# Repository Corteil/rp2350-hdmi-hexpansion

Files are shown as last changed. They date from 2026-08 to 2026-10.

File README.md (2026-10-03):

# Hexi-GFX — RP2350 HDMI Hexpansion for the EMF Tildagon Badge

A Tildagon hexpansion that mirrors the EMF badge's 240×240 round screen onto a
real HDMI/DVI monitor — an RP2350 drives the video over HSTX, pixel-doubled and
pillarboxed into a standard 640×480@60 signal. Every existing badge app gets
HDMI output with no code changes.

For the full design rationale, bench measurements, BOM, costing, and the
phase-by-phase delivery plan that got here, see [`HISTORY.md`](HISTORY.md).
This file covers what's true *now*.

## Status (03/10/26)

**Real mirroring and stable HSTX video work together, confirmed on real
hardware** — not just clean logs, actual moving content on a monitor. Current
firmware is `firmware/pio-testcard/`, running on an **Adafruit Metro RP2350**
dev board wired to a real badge hexpansion port, and since 03/10/26 also on
a **Raspberry Pi Pico 2 + Adafruit DVI Sock** (`-DHEXI_BOARD=pico2`, see
[its section](#alternative-bench-board-raspberry-pi-pico-2--adafruit-dvi-sock-tested)),
powered straight from the badge's 3V3. The custom hexpansion PCB's
schematic is drafted in `hardware/`; layout hasn't started (see
[Next step](#next-step)).

- Badge side: `display.attach_mirror()`, from a fork of
  [hazanjon/badge-2024-software](https://github.com/hazanjon/badge-2024-software)
  PR #454, with three real bugs found and fixed (SPI acquire-bus timeout, a
  non-idempotent display init that froze the badge's own screen, and an
  SPI-host/GPIO-pin ordering bug). Fixes were merged into hazanjon's
  `feature/hdmi-mirror` branch as
  [hazanjon/badge-2024-software#1](https://github.com/hazanjon/badge-2024-software/pull/1);
  that branch was rebuilt and flashed to the badge on 03/10/26 and the
  mirror was confirmed working with the Pico 2.
- RP2350 side: a from-scratch PIO-based SPI0 slave receiver (the hardware
  SPI0/PL022 peripheral loses byte alignment mid-burst on this chip and never
  recovers), double-buffered HSTX/DVI scanout, and a grey-to-black vignette
  fade on the pillarbox/mask area around the circular content.
- Known, understood, non-blocking: ~12% of frames (Metro) to ~18% (Pico 2,
  one sample) get abandoned when the badge starts a new frame before the
  RP2350 finishes the previous one — benign, fully instrumented, not a bug
  to fix.
- Known, benign: on the Pico 2 each port insertion resets the board twice
  about 2 s apart (likely the badge power-cycling the port); the mirror
  re-attaches by itself.

## Repo layout

| Path | What it is |
|---|---|
| `firmware/pio-testcard/` | **Current firmware.** Real HSTX/DVI video and real SPI mirror reception together — what's actually flashed to the bench Metro RP2350 today. |
| `firmware/testcard/` | Earlier milestone: full hexpansion-identity EEPROM emulation + the first end-to-end SPI link demo. Superseded by `pio-testcard` for the mirror path itself, but still the reference for EEPROM emulation. |
| `firmware/pin-probe/` | Pico 2 bench tool that counts transitions on every header GPIO (read over SWD), used with the badge's Pin Tester app to prove which Pico pin each `HS_F`..`HS_I` wire lands on. |
| `firmware/mirror_debug/` | Bench diagnostic tool used to bring up the PIO-based SPI slave receiver protocol. |
| `firmware/phase0-*/` | Individual bring-up experiments from early de-risking (HSTX/DVI basics, colour-channel fix, SPI speed sweep, EEPROM emulation, ctx rasterisation benchmark, microSD). Each has its own README. |
| `hdmi-mirror-plan.md` | Implementation notes for switching to hazanjon's real `attach_mirror()` protocol (SPI mode, byte order, per-port pin overrides). Completed; kept for reference. |
| `HISTORY.md` | The full design journal — rationale, bench measurements, BOM, costing, risk register, phase plan. Read this for *why*, not *what's true now*. |
| `hardware/` | KiCad 10 project for the hexpansion PCB (schematic v0.1 done, layout not started), `lib/jlc.*` (JLCPCB/LCSC symbols, footprints and 3D models), and `hexpansion_bom.xlsx`, the JLCPCB assembly BOM tracker. |
| `tildagon-base/` | Tildagon KiCad symbol and footprint library (hexpansion edge connector etc.), used by `hardware/`. |
| `bom.csv` | Machine-readable bill of materials, generated from the schematic (LCSC numbers, JLC Basic/Extended, prices). |

## Hardware today

Bench rig: an Adafruit Metro RP2350 (SPI0 slave on GPIO20–23, HSTX on
GPIO12–19), wired to a real hexpansion port on an EMF Tildagon badge.

**HS wiring gotcha (all ports):** hazanjon's badge-side `PORT_PINS` table
puts SCK on `HS_G` and CS on `HS_H`, the opposite of this project's original
`HS_G`=CS / `HS_H`=SCK convention. For a real mirror test, wire
`HS_F`→GPIO20, `HS_G`→GPIO22, `HS_H`→GPIO21, `HS_I`→GPIO23 at the RP2350 end.
First found on port 4, since tested on all six ports; the PCB is wired this
way. See `HISTORY.md` §4.1 for the full derivation and why the two sides
disagree.

VID/PID assigned for the eventual EEPROM-emulating hexpansion: `0x1969` /
`0x4544`.

### Alternative bench board: Adafruit Feather RP2350 + HSTX (builds, not yet tested on hardware)

Build with `-DHEXI_BOARD=feather` (see [Building and flashing](#building-and-flashing)).
The Feather is an RP2350A: the same die as the RP2354A the real hexpansion
uses (the RP2354A just adds 2 MB of flash in the package), and
its 22-pin HSTX FPC connector carries GPIO12–19 in the same lane order the
firmware already uses. So video needs no changes: plug in the same DVI
breakout and FPC cable as on the Metro.

Two things do move. GPIO21 is the Feather's onboard NeoPixel and isn't
broken out, so the Metro's GPIO20–23 SPI block can't be used. The
PIO-based receiver doesn't need hardware-SPI pins, just three consecutive
GPIOs for MOSI/CS/SCK, so it moves to D9–D11:

| Function | RP2350 GPIO | Feather pin |
|---|---|---|
| HSTX video (all 8 lines) | 12–19 | 22-pin HSTX FPC connector |
| SPI MOSI (`HS_F`) | 9 | D9 |
| SPI CS (`HS_H` on port 4) | 10 | D10 |
| SPI SCK (`HS_G` on port 4) | 11 | D11 |
| SPI MISO (`HS_I`, never driven) | 20 | MI |
| EEPROM-emulation I2C0 SDA / SCL | 4 / 5 | GPIO4 (CircuitPython `D12`/`IO4`) / D5 |
| Debug UART0 TX / RX (`_debug` build) | 0 / 1 | TX / RX |
| Status NeoPixel | 21 | onboard |
| `LS_A` → RUN | — | RST |
| GND | — | GND |

The port-4 SCK/CS crossover is already applied above. GPIO4 is labelled
from CircuitPython's pin map, so check the board silkscreen for that pad.
SWD is on the Feather's 3-pin JST-SH connector, so the Debug Probe cable
plugs straight in. UF2 flashing (hold BOOT, tap RESET) also works. Flash
is 8 MB, not 16 MB, which is plenty for this firmware. Use the RESET
button for step 3 of the reinsertion procedure below.

### Alternative bench board: Raspberry Pi Pico 2 + Adafruit DVI Sock (tested)

Build with `-DHEXI_BOARD=pico2`. **Confirmed working end to end on 03/10/26**:
stable mirror picture on the official Raspberry Pi monitor, status LED at
5 Hz while frames arrive. The Pico 2 is an RP2350A, so HSTX reaches the same
GPIO12–19 block the [Adafruit DVI Sock for Pico](https://www.adafruit.com/product/5957)
is wired to. The Sock is a passive connector plus 220 Ω series resistors, and
its product page describes it for the RP2040. It works fine with HSTX, but its
**lane order differs from the Metro/Feather wiring**, so this variant uses
`lane_to_output_bit = {0, 6, 4}` (D0 = GP12/13, D1 = GP18/19, D2 = GP16/17,
CK = GP14/15, "+" on the even GPIO).

| Function | RP2350 GPIO | Notes |
|---|---|---|
| HSTX video | 12–19 | DVI Sock, see lane order above |
| SPI MOSI (`HS_F`) | 0 | |
| SPI CS (`HS_H` on port 4) | 1 | |
| SPI SCK (`HS_G` on port 4) | 2 | port-4 SCK/CS crossover already applied |
| SPI MISO (`HS_I`, never driven) | 3 | |
| EEPROM-emulation I2C0 SDA / SCL | 4 / 5 | unchanged |
| Debug UART1 TX / RX (`_debug` build) | 8 / 9 | moved off GP0/1, which are now SPI inputs |
| Status LED (plain GPIO) | 25 | 1 Hz = running, no frames; 5 Hz = frames arriving |
| Status NeoPixel (external WS2812) | 22 | same colours as the other boards |
| `LS_A` → `RUN` | — | lets the badge reset the Pico 2; a reset switch from `RUN` to GND is also fitted |
| Badge 3V3 → VSYS (pin 39) | — | powers the board, with no USB attached |
| GND | — | shared with the badge: any GND pin on the port breakout hexpansion |

A step-by-step hardware build and flashing guide for this variant is in
[`docs/index.md`](docs/index.md), also published at
<https://corteil.github.io/rp2350-hdmi-hexpansion/>. A prebuilt UF2 is on the
[`pico2-v1` release](https://github.com/Corteil/rp2350-hdmi-hexpansion/releases/tag/pico2-v1).

Notes from bring-up:

- **Power:** it runs fine from the badge's 3V3 with no USB. Never connect USB
  and an external 3V3 into VSYS together: VBUS feeds VSYS through a diode, so
  the external source gets back-fed. Use a series Schottky if both are needed.
- **5 V on the Sock's 5 V pad** is monitor-dependent. Some monitors only show
  a signal when it is present; the official Raspberry Pi monitor and a video
  capture dongle don't need it. With no USB attached there is no VBUS, so for
  a monitor that needs it, use a boost converter: input from VSYS and GND,
  5 V output to the Sock's 5 V pad, GND common with the port breakout's GND.
- **Each port insertion resets the Pico 2 twice, about 2 s apart** (probably
  the badge power-cycling the port; not scoped). It is harmless: the mirror
  re-attaches and the picture returns by itself.
- **Wire-continuity check:** `firmware/pin-probe` plus Pin Tester's `blink`
  (via `mpremote exec`, store-installed path `/apps/Corteil_Pin_Tester`) maps
  each badge pin to a Pico GPIO. A bad `HS_F` wire here looked like CS/SCK
  arriving but a stuck-high or stuck-low data line and no `TDHD` match.

### Alternative bench board: Waveshare RP2350-PiZero (not yet tested)

The [Waveshare RP2350-PiZero](https://www.waveshare.com/wiki/RP2350-PiZero)
can stand in for the Metro, with one big caveat: its onboard mini-HDMI is
wired to **GPIO32–39**, and HSTX only reaches **GPIO12–19**, so the current
firmware can't drive the onboard connector. Instead, wire HSTX from the
40-pin header to an external DVI breakout, exactly as on the Metro.

Its chip (RP2350B), flash (W25Q128, 16 MB) and 12 MHz crystal match the
Metro, and every pin the firmware uses is on the header. The existing
`pio_testcard` build should therefore run unmodified, but that hasn't been
checked on real hardware yet.

**The header is not Raspberry-Pi numbered.** Waveshare's J5 net labels are
RP2350 GPIOs and differ from the silkscreen/BCM names (e.g. header pin 7 is
BCM4 but RP2350 **GPIO14**). Wire by *header pin number* from this table,
taken from Waveshare's schematic (`RP2350-PiZero.pdf`):

| Function | RP2350 GPIO | PiZero header pin |
|---|---|---|
| HSTX D2+ / D2− | 12 / 13 | 21 / 33 |
| HSTX CLK+ / CLK− | 14 / 15 | 7 / 29 |
| HSTX D1+ / D1− | 16 / 17 | 36 / 11 |
| HSTX D0+ / D0− | 18 / 19 | 12 / 35 |
| SPI MOSI (`HS_F`) | 20 | 38 |
| SPI CS (`HS_H` on port 4) | 21 | 40 |
| SPI SCK (`HS_G` on port 4) | 22 | 15 |
| SPI MISO (`HS_I`) | 23 | 16 |
| EEPROM-emulation I2C0 SDA / SCL | 4 / 5 | 8 / 10 |
| Debug UART0 TX / RX (`_debug` build) | 0 / 1 | 27 / 28 |
| GND | — | 6, 9, 14, 20, 25, 30, 34, 39 |
| `LS_A` → RUN | — | not on the header: solder to the RUN side of the reset button (Key2) |

HSTX lane assignment comes from `hstx_dvi_init()` in
`firmware/pio-testcard/src/main.c` (`lane_to_output_bit`), and the port-4
SCK/CS crossover above is already applied. Other differences from the Metro:

- **No addressable RGB LED.** The only LED is a red power LED. The firmware
  still drives its status-LED signal on GPIO25 (header pin 22). That's
  harmless, and you can wire a WS2812 there to get the status colours back.
- **SD card-detect isn't on a GPIO** (the slot's CD pin goes to GND), so
  GPIO22 is free for SCK.
- **Buttons:** Key1 is BOOTSEL and Key2 is reset (RUN). Use Key2 for step 3
  of the reinsertion procedure below.
- **SWD** is on the 3-pin header H1 (SWCLK / GND / SWDIO), so Debug Probe
  flashing works as documented. Holding Key1 while plugging in USB and
  copying `pio_testcard.uf2` also works.
- **Don't switch the build to the Pico SDK's `waveshare_rp2350_pizero` board
  file** without overriding its default UART. It puts UART1 on GPIO4/5,
  which collides with the EEPROM-emulation I2C in the `_debug` build. The
  Metro board file already used here puts UART0 on GPIO0/1.
- **Signal integrity:** the TMDS pairs are spread across the header, so they
  run at 252 Mbit/s over hand-run wires rather than an FPC cable. Keep each
  +/− pair short, equal-length and twisted together. Suspect the wiring
  first if the picture sparkles or drops out.

Using the onboard mini-HDMI would need one of two things. One is a PIO-based
PicoDVI scanout: 252 MHz `clk_sys`, a PIO block set to see GPIO16–47, and a
reworked framebuffer. The other is a board mod: remove the eight 200 Ω
series resistors (R1–R4, R6, R7, R10, R12) and feed GPIO12–19 into their
connector-side pads. Neither has been tried. The first diverges from the
HSTX design the hexpansion PCB will use.

## Reinsertion procedure (corrected 03/10/26, still manual)

Plugging the hexpansion into an already-running badge doesn't reliably start
mirroring on its own yet, even with the auto-attach relay packed into the
fake EEPROM (`firmware/testcard/badge_app/app.py`) and its LS_A-pulse
hardware reset (`firmware/pio-testcard/src/main.c`'s own comments have the
full root-cause trail on why a reset is needed at all). The sequence
confirmed working on the bench, in order:

1. Insert the `HDMI-HEX` hexpansion.
2. In `tildagon-hdmi-manager` (or `display_manager`), **detach** the mirror.
3. Press the physical **reset button** on the RP2350 board (SW2 on the Metro).
4. **Attach** the mirror again, from the same app.

The order matters: the reset goes between detach and attach, not after.
Auto-attach alone wasn't enough.

## Building and flashing

### RP2350 firmware (`pio-testcard`)

Needs the Raspberry Pi Pico SDK (2.x) and an `arm-none-eabi-gcc` toolchain,
with `PICO_SDK_PATH` set.

```sh
cd firmware/pio-testcard
mkdir -p build && cd build
cmake ..
cmake --build .
```

That builds for the Metro RP2350 (the default). For the Adafruit Feather
RP2350 + HSTX, configure a separate build directory from
`firmware/pio-testcard` instead:

```sh
cmake -B build-feather -DHEXI_BOARD=feather
cmake --build build-feather
```

For the Raspberry Pi Pico 2 + Adafruit DVI Sock, use `-DHEXI_BOARD=pico2`
the same way (`cmake -B build-pico2 -DHEXI_BOARD=pico2`).

Flash over SWD with a Raspberry Pi Debug Probe:

```sh
openocd -f interface/cmsis-dap.cfg -f target/rp2350.cfg -c "adapter speed 5000" \
  -c "program pio_testcard.elf verify reset exit"
```

### Badge-side driver

Depends on `display.attach_mirror()` from the fork above. Built via the
project's own Docker image (`ghcr.io/emfcamp/esp_idf:v5.5.1`):

```sh
git clone --recursive --branch pr-454-hazan-mirror https://github.com/Corteil/badge-2024-software.git
cd badge-2024-software
./scripts/firstTime.sh
docker run --rm --env "TARGET=esp32s3" -v "$(pwd)":/firmware -u "$(id -u):$(id -g)" \
  -e HOME=/tmp ghcr.io/emfcamp/esp_idf:v5.5.1
```

Flash to a real badge in bootloader mode (disconnect USB, hold **BAT + BOOP**
for ~20s, reconnect):

```sh
docker run --rm --device /dev/ttyACM0:/dev/ttyUSB0 --group-add <your dialout/plugdev GID> \
  --env "TARGET=esp32s3" -v "$(pwd)":/firmware -u "$(id -u):$(id -g)" -e HOME=/tmp \
  ghcr.io/emfcamp/esp_idf:v5.5.1 deploy
```

The badge stays in bootloader mode after flashing — disconnect/reconnect the
USB cable once more to actually boot the new image.

## Next step

Designing the actual hexpansion PCB (44 mm hexagon, EEPROM emulation, USB-C +
HDMI power isolation) — the whole plan for it, including the pin map, power
architecture, BOM, and costing this bench work was de-risking, is in
[`HISTORY.md`](HISTORY.md).

**Schematic v0.1 is done** (`hardware/rp2350-hdmi-hexpansion.kicad_sch`,
28/09/26). The PCB layout hasn't started: open the project and run
*Tools → Update PCB from Schematic*. Every part has a JLCPCB/LCSC number,
and its symbol, footprint and 3D model are in the project library
`hardware/lib/jlc.*`, pulled with
[easyeda2kicad](https://github.com/uPesy/easyeda2kicad.py). KiCad's ERC is
clean apart from one expected warning (HEXP_DET tied to GND is how the
badge detects a hexpansion), and the exported netlist was checked
pin-for-pin against the design. `bom.csv` and `hardware/hexpansion_bom.xlsx`
are generated from the schematic.

Changes from the `HISTORY.md` plan:

- **MCU is the RP2354A**, not the RP2350A: the same die and QFN-60 pinout,
  with 2 MB of flash in the package on QSPI CS0. There's no external flash
  chip (the W25Q128 is gone). 2 MB is plenty: the largest firmware build is
  about 260 KB. Build with `PICO_FLASH_SIZE_BYTES` set to 2 MB.
- **The PSRAM is footprint-only (DNP)**, for optional hand soldering. The
  part is the **APS6404L-3SQR-SN** (SOP-8, 3.3 V); the `-ZR` that the old
  BOM listed is USON-8. It stays on QSPI CS1 = GPIO0, with a 10k pull-up on
  CS that is fitted even when the PSRAM isn't, so firmware must detect it
  at boot rather than assume it.
- **Full-size HDMI Type A** socket instead of mini-HDMI. It's wider, so check
  the fit on the outer flat.
- **One Qwiic socket** instead of two, to save edge space.
- **TLV62569** 2 A buck instead of the TPS62203 (300 mA, poor stock).
- **No HDMI DDC/EDID.** The output is always 640×480@60, which every
  monitor must accept, so there's nothing to read. The PCA9306 and its six
  passives are gone. Hot-plug detect stays (GPIO2).
- **No microSD.** That frees the second side flat and GPIO5 and 8–11.
  Spare GPIOs are now **3, 4, 5, 8, 9, 10, 11**, all left no-connect.
- **Trimmed to the Raspberry Pi minimal design.** TMDS lines go straight
  from GPIO12–19 to the ESD chips and socket, with no 0R insurance resistors,
  as the bench has always run. There are 7 × 100 nF on 3.3 V (pins 44/45 and
  53/54 share, as in Raspberry Pi's reference), no BOOTSEL pull-up (QSPI_SS
  has one internally) and no RUN debounce cap. The ferrite beads are gone.
- Kept from the design guide: the 1k crystal series resistor, 33R
  VREG_AVDD filter, 27R USB series resistors and a 10k RUN pull-up (because
  of the badge reset). Also added: an HDMI +5V PTC fuse and test pads.
- Result: **80 JLC-placed parts, about $5.11 a board** at the 10-board price
  tier (25 capacitors, 32 resistors).

**Pin map changes from `HISTORY.md` §4.1.** It had no free GPIOs for three
signals, so `LS_C`/`LS_D`/`LS_E` are left unconnected and their GPIOs reused:

| GPIO | Now | Was |
|---:|---|---|
| 27 | SK6805 RGB LED data | `LS_C` (bootloader-entry idea) |
| 28 | Badge-rail sense (ADC2, 100k/100k from `3V3_BADGE`) | `LS_D` spare |
| 29 | HDMI +5V boost enable (100k pull-down) | `LS_E` spare |

On the board, `HS_G`→GPIO22 (SCK) and `HS_H`→GPIO21 (CS). That's the
crossing the badge's mirror driver needs, **tested on all six ports**.

**Firmware changes the PCB needs** (from `pio-testcard`): EEPROM emulation
moves from GPIO4/5 to **GPIO24/25**, with its internal pull-ups *off*
(they'd back-power an unpowered badge). The status NeoPixel moves to
**GPIO27**. Set the flash size to 2 MB.

**Badge reset without backfeed.** `LS_A` drives RUN through **U11, an
SN74LVC1G07 open-drain buffer powered from `3V3_BADGE`**. R4 (10k to
`3V3_BADGE`) holds `LS_A` high, so it idles at "not reset". When the badge
is off, U11 is unpowered. Its partial-power-down (I_off) spec, ≤10 µA and
typically far less, stops the RUN pull-up leaking into the badge, and the
RP2354A keeps running from USB. A plain diode can't do this: the reset
current and the leak flow the same way.

## Acknowledgements

This project depends on the work of [hazanjon](https://github.com/hazanjon).
The badge-side display mirroring that the hexpansion receives, including
`display.attach_mirror()`, the SPI frame protocol with its `TDHD` header, and
the per-port pin handling in `flow3r_bsp_display_mirror.c`, comes from
his [badge-2024-software](https://github.com/hazanjon/badge-2024-software)
work (PR #454 against `emfcamp/badge-2024-software`). His
[display_manager](https://github.com/hazanjon/display_manager) app provides
the badge-side driver definitions and attach controls used to drive it.
Without that groundwork there would be nothing for this hexpansion to mirror,
and the fixes in this repo's badge-side PR were built on top of it. Thank you.

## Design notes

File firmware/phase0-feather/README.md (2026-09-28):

# Phase 0, Part A / B3 — Adafruit Feather RP2350 (+ HSTX) bring-up

Bench firmware for the Feather in the design's [Phase 0
plan](../../HISTORY.md#phase-0--de-risk-on-the-bench-23-weekends) —
RP2350A, the chip variant the actual hexpansion design targets (see
`HISTORY.md` §4.1, "Why the RP2350A and not the B"). The PCB now uses the
RP2354A, which is the same RP2350A die with 2 MB of flash in the package,
so this bench is still representative.

Board: **Adafruit Feather RP2350 (+ HSTX)**, RP2350A, no PSRAM populated
by default (DNP footprint) unless someone's soldered an APS6404L onto it.

## What this is (and isn't)

Part A's real job — HSTX DVI mirroring (A1), pin-map validation against
the badge's hexpansion edge connector (A2), DVI output on a real monitor
(A3), current draw (A4) — needs the badge, a protoboard hexpansion, an
HSTX-to-DVI adapter, and a monitor. None of that is here yet.

**This is B3**: reusing `firmware/phase0-metro`'s PSRAM and ctx
benchmarks — both board-agnostic, no board-specific pins involved — to
get RP2350A vs. RP2350B numbers to compare against the Metro's results.
`src/ctx_bench.c`, `src/psram_dma_bench.c` and `third_party/ctx/` are
copies of the Metro's, not shared library code — see the note in
`firmware/phase0-metro/README.md` (and the design's own general
"duplication over premature abstraction" instinct) for why: this is
disposable Phase 0 bench code, not the eventual product firmware, so two
small independent copies beat coupling two separate bench projects
together.

**No SD card bench** — the Feather has no microSD slot, unlike the Metro.

**No custom board header needed** — unlike the Metro, Adafruit's Feather
RP2350 already has an official pico-sdk board header
(`adafruit_feather_rp2350.h`, RP2350A, LED GPIO7, PSRAM CS GPIO8 with
`PICO_AUTO_DETECT_PSRAM_SIZE` since Adafruit sells this board both with
and without PSRAM). `CMakeLists.txt` just sets `PICO_BOARD
adafruit_feather_rp2350`.

## PSRAM: populated or not, this runs either way

Both benchmarks already check `psram_is_available()` and skip themselves
cleanly (printing why) if PSRAM isn't detected. If you see them skip,
that itself answers "is PSRAM populated on this specific board" — no
separate check needed.

## Build

```bash
export PICO_SDK_PATH="$HOME/.pico-sdk/sdk/2.3.0"
export PICO_TOOLCHAIN_PATH="$HOME/.pico-sdk/toolchain/14_2_Rel1"
export PATH="$HOME/.pico-sdk/toolchain/14_2_Rel1/bin:$HOME/.pico-sdk/cmake/v3.31.5/bin:$HOME/.pico-sdk/ninja/v1.12.1:$HOME/.pico-sdk/picotool/2.3.0/picotool:$PATH"

cmake -G Ninja -B build .
cmake --build build
```

## Flash

Hold BOOT, tap RESET (or plug in while holding BOOT) to drop the Feather
into UF2 bootloader mode, then copy `build/bringup.uf2` onto the
`RPI-RP2` drive that appears. Or, with the board already running:

```bash
picotool load -f build/bringup.uf2
```

## Expected result

Same shape as the Metro's: USB CDC prints PSRAM detection (or a clear
"not populated" line), the self-test, the `clk_sys`/PSRAM-clock
diagnostic, the B1 ctx benchmark, then the B2 PSRAM-scanout DMA
benchmark — once. Then the LED (GPIO7) blinks at 1 Hz with a
`phase0-feather alive: tick N` heartbeat every 500 ms.

## Results (2026-08-30)

```
phase0-feather: PSRAM bring-up
PSRAM: not detected (CS GPIO 8) - expected if this board's
PSRAM footprint hasn't been populated (it ships DNP).

phase0-feather: B1 ctx rasterisation benchmark
  skipped: need >= 614400 bytes of PSRAM for a 640x480 framebuffer, have 0

phase0-feather: B2 PSRAM-backed scanout (DMA read) benchmark
  skipped: PSRAM not available
```

**This specific Feather doesn't have PSRAM populated.** Everything else
worked as designed: toolchain/board bring-up on real RP2350A silicon,
USB-CDC-wait logic, and both benchmarks skipping themselves cleanly with
a clear reason rather than hanging or crashing. No RP2350A vs. RP2350B
PSRAM/ctx comparison numbers without either populating the DNP PSRAM
footprint with an APS6404L (~$1.15, BOM line 3 — see `HISTORY.md` §8's
Phase 0 rig note) or accepting that this comparison isn't available on
this board as-is.

(An initial run of this firmware mislabelled both benchmarks'
output as "phase0-metro" — a copy-paste artifact in the duplicated
`ctx_bench.c`/`psram_dma_bench.c`, since fixed. The output above is from
the corrected build.)

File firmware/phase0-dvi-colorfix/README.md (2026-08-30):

# Phase 0, A1 — root-causing the colour channel rotation

Bench firmware for the **Metro RP2350**, not the Feather — see the main README's Phase 0
Part A ([A1](../../README.md#phase-0--de-risk-on-the-bench-23-weekends)) "Still open" note.
`firmware/phase0-dvi/` (Feather, Stage 1) found a clean 3-way colour rotation on real
hardware and worked around it with an empirically-inverted test-pattern colour table — a
test-pattern-level fix, not usable for real badge pixel data. This firmware is the actual
root-cause fix, derived from first principles and confirmed on real hardware, then backported
unchanged into `phase0-dvi/` and `phase0-dvi2/`.

## Why the Metro, not the Feather

The board available to test with at the time. Not a problem: HSTX is silicon-fixed to
GPIO12–19 regardless of RP2350A/RP2350B package (HSTX bit index `n` is always GPIO `12+n`),
and Adafruit's own Metro RP2350 pinout page confirms its dedicated 22-pin HSTX connector
breaks out exactly GPIO12–19 as D0P/D0N/D1P/D1N/D2P/D2N/CKP/CKN — the identical mapping
`phase0-dvi` already uses on the Feather. **The main README previously claimed the Metro has
"no HSTX peripheral broken out" — that was wrong**, corrected alongside this firmware. A fix
that's purely register-level TMDS math (this one) transfers between boards with zero risk;
DMA/HSTX/timing mechanics (already proven separately on the Feather in `phase0-dvi`/
`phase0-dvi2`) are untouched here.

## The root cause

Not a simple "swap two lanes" bug. Two separate mistakes compounded:

1. **Wrong lane order.** `phase0-dvi` copied Adafruit's PicoDVI driver's `expand_tmds`
   ROT/NBITS values under the assumption L0=Red, L1=Green, L2=Blue. The real DVI/HDMI TMDS
   channel convention is **L0=Blue, L1=Green, L2=Red** — not alphabetical, a well-known trap.
2. **Wrong bit-field math even for the assumed lane order.** Per pico-sdk's
   `hardware/regs/hstx_ctrl.h` (straight from the SVD): each lane's `ROT` is a **right-rotate**
   applied to the current 32-bit shifter word before that lane's encoder, and `NBITS` is the
   valid-bit count "starting from bit 7 of the rotated data" — so a channel's own MSB must
   land exactly on bit 7 after rotation. Adafruit's specific ROT values don't decode to a
   clean single-channel window under this formula against this project's own RGB565 packing
   (two pixels/word, earlier pixel in the low 16 bits, standard R\[15:11\]/G\[10:5\]/B\[4:0\]
   layout) — they must assume a different internal convention Adafruit's own driver uses
   internally, not stated anywhere obvious in their source.

**Validated the formula against a known-good reference before trusting it**: fetched
`raspberrypi/pico-examples`' own `hstx/dvi_out_hstx_encoder` RGB332 sample (L0 NBITS=1/ROT=26,
L1 NBITS=2/ROT=29, L2 NBITS=2/ROT=0) and decoded it by hand —

> `original_bit_index = (output_bit + ROT) mod 32`, window = rotated bits `[7 : 7-count+1]`

— which resolves EXACTLY to L0=Blue, L1=Green, L2=Red, matching RGB332's known bit layout
bit-for-bit. That confirmed both the rotate-direction/window formula and the true lane order,
independent of anything Adafruit-specific.

**Recomputed from scratch for this project's own RGB565 layout** using
`ROT = (channel_MSB_bit_index - 7) mod 32`:

| Channel | Lane | MSB bit | ROT | NBITS field | Bits |
|---|---|---:|---:|---:|---:|
| Red | L2 | 15 | 8 | 4 | 5 |
| Green | L1 | 10 | 3 | 5 | 6 |
| Blue | L0 | 4 | 29 | 4 | 5 |

`expand_shift`'s `ENC_SHIFT=16` right-rotates the whole 32-bit word by 16 between the two
packed pixels, bringing the second pixel down into the same low-16-bit position the first
started in — so these same fixed ROT values correctly decode both pixels per word, the same
way pico-examples' single fixed set works across all 4 sub-pixels of its RGB332 case.

## Test pattern

Same 8-bar pattern as `phase0-dvi` Stage 1 (white/yellow/cyan/green/magenta/red/blue/black,
80px each), but using the **true, uncompensated** RGB565 values directly — no software
inversion table. If the fix is right, colours come out correctly ordered with no further
massaging.

## Build

```bash
export PICO_SDK_PATH="$HOME/.pico-sdk/sdk/2.3.0"
export PICO_TOOLCHAIN_PATH="$HOME/.pico-sdk/toolchain/14_2_Rel1"
export PATH="$HOME/.pico-sdk/toolchain/14_2_Rel1/bin:$HOME/.pico-sdk/cmake/v3.31.5/bin:$HOME/.pico-sdk/ninja/v1.12.1:$HOME/.pico-sdk/picotool/2.3.0/picotool:$PATH"

cmake -G Ninja -B build .
cmake --build build
```

## Flash

`picotool load -f build/bringup.uf2` (forces a reboot over USB, no BOOTSEL button needed if
the board is already running any pico-sdk firmware with a live USB connection), or hold BOOT
+ tap RESET and copy `build/bringup.uf2` onto the `RPI-RP2` drive. No USB CDC console output
(pure video, same as `phase0-dvi` Stage 1) — check the monitor, connected via the Metro's
22-pin HSTX port and the Adafruit HSTX-to-DVI adapter.

## Results (2026-08-30, Metro RP2350, real monitor)

**Confirmed correct on the first attempt.** 8 sharp, evenly-spaced, **correctly-coloured**
vertical bars — white/yellow/cyan/green/magenta/red/blue/black, left to right, stable, no
compensation table involved. The derivation above is the real fix, not a guess that happened
to work.

**Backported unchanged into `firmware/phase0-dvi/` and `firmware/phase0-dvi2/`** (both
rebuild cleanly) — the register math is board-independent, so the same fix applies there
without re-deriving anything. Not re-flashed on the physical Feather in this session (only
the Metro was connected), but there is no board-specific mechanism left in this fix to
re-verify: same silicon, same GPIO/lane mapping, same RGB565 packing convention, same
`expand_shift` config, all already true on both boards. Re-flashing the Feather to visually
re-confirm is cheap whenever it's next connected, but not expected to reveal anything new.

Settles the main README's A1 "still open" item: the colour channel rotation is now fixed at
the source, not compensated in the test pattern.

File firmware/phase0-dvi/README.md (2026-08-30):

# Phase 0, Part A — HSTX DVI bring-up (Stage 1)

Bench firmware for the Feather in the design's [Phase 0
plan](../../README.md#phase-0--de-risk-on-the-bench-23-weekends), Part A —
specifically **A1** (scale-during-scanout) and **A3** (640×480@60 DVI
output on a real monitor).

Board: **Adafruit Feather RP2350 with HSTX**, plus the Adafruit RP2350
22-pin FPC HSTX-to-DVI adapter and a monitor.

## What this is (Stage 1, not the full A1 yet)

The real A1 target is a 240×240 source, pillarboxed and circular-masked,
scaled 2× into 640×480 — see main README §3.1/§3.4. That's a substantial
per-scanline command table (the mask boundary varies every line). Rather
than write and test all of that blind, this stage proves the more basic
plumbing first:

- **320×240 source doubled to fill 640×480 exactly** — no pillarbox, no
  circular mask needed, since 320×2=640 and 240×2=480 land exactly on the
  output size. Once this works, the harder pillarboxed/masked 240×240
  case is an extension, not a from-scratch rewrite.
- **Horizontal 2× done by pre-expanding into 640-wide rows in SRAM at
  init**, not via HSTX/DMA's pixel-duplication register trick. Sidesteps
  a fiddly bit-packing detail for this first attempt; vertical 2× is done
  the simple way regardless (re-reading each source row twice).
- **Two-DMA-channel ping-pong + one IRQ per scanline** (from the official
  [`raspberrypi/pico-examples`](https://github.com/raspberrypi/pico-examples)
  `hstx/dvi_out_hstx_encoder` example), not the more CPU-efficient
  one-IRQ-per-*frame* ring-buffer mechanism. The ring-buffer approach
  (used by Adafruit's own PicoDVI driver — see below) is real and worth
  adopting once this simpler, fully-traced version is confirmed correct on
  hardware — CPU load is what A1 actually needs to measure, just not
  from this stage.

Two references, both credited in `src/main.c`'s file header:
- **[`raspberrypi/pico-examples`](https://github.com/raspberrypi/pico-examples)**
  `hstx/dvi_out_hstx_encoder` (BSD-3) — the DMA ping-pong mechanism, the
  standard 640×480@60 timing constants (`V_BACK_PORCH=33`, CEA-861 VIC 1),
  and the overall command-list structure this firmware is built from.
- **[`adafruit/circuitpython`](https://github.com/adafruit/circuitpython)**
  `ports/raspberrypi/common-hal/picodvi/Framebuffer_RP2350.c` (MIT) — the
  RGB565 `expand_tmds`/`expand_shift` register values (proven on real
  HSTX+DVI hardware), and confirmation of the BSWAP-during-DMA idea for
  RGB565. **Not used for timing** — that file's own `MODE_640_V_BACK_PORCH`
  is 133, not the standard 33, for reasons unclear; the spec-correct
  pico-examples numbers are used instead, matching main README §3.3.

## Feather-specific pin mapping

Confirmed from [Adafruit's Feather RP2350 pinout
page](https://learn.adafruit.com/adafruit-feather-rp2350/pinouts), **not**
assumed from the Pico DVI Sock pinout pico-examples' own comment
describes (different board, different mapping):

| GPIO | Signal |
|---|---|
| 12/13 | TMDS lane 2 |
| 14/15 | Clock |
| 16/17 | TMDS lane 1 |
| 18/19 | TMDS lane 0 |

Color-channel-to-lane assignment (which of R/G/B is "lane 0" and so on)
is inferred from Adafruit's driver's own internal naming (`red` feeds
`expand_tmds`'s L0 field in their code) matched against their pinout
page's own "Lane0/1/2" terminology — consistent, but not seen stated
explicitly as "GPIO18/19 carries red" in so many words. If the test
pattern's colours come out channel-swapped, that's a one-line fix
(swap two entries in `lane_to_output_bit[]` in `src/main.c`) — a cheap,
easily visually diagnosed thing to get wrong, not a hardware risk.

## Test pattern

8 vertical colour bars, 80px each: white / yellow / cyan / green /
magenta / red / blue / black — the classic order. Lets one glance confirm
both geometry (bars should be sharp, evenly spaced, no skew) and colour
wiring (each bar is a known, named colour) at once.

## Build

```bash
export PICO_SDK_PATH="$HOME/.pico-sdk/sdk/2.3.0"
export PICO_TOOLCHAIN_PATH="$HOME/.pico-sdk/toolchain/14_2_Rel1"
export PATH="$HOME/.pico-sdk/toolchain/14_2_Rel1/bin:$HOME/.pico-sdk/cmake/v3.31.5/bin:$HOME/.pico-sdk/ninja/v1.12.1:$HOME/.pico-sdk/picotool/2.3.0/picotool:$PATH"

cmake -G Ninja -B build .
cmake --build build
```

## Flash

Hold BOOT, tap RESET (or plug in while holding BOOT), copy
`build/bringup.uf2` onto the `RPI-RP2` drive. No USB CDC console output
from this firmware (it's pure video output, no `stdio` use in the render
path) — the only thing to check is the monitor.

## What to check

1. **Does a picture appear at all** — the fundamental TMDS/HSTX/DMA/timing
   chain working, independent of anything else.
2. **Is it stable** — no flickering, rolling, or loss of sync.
3. **Are there exactly 8 sharp, evenly-spaced vertical bars filling the
   whole 640×480 area**, in the order listed above — confirms the
   doubling math and DMA read addressing are right.
4. **Are the colours right** (white/yellow/cyan/green/magenta/red/blue/
   black, in that order) — confirms the RGB565 TMDS config and the
   lane/pin mapping. If channel-swapped (e.g. red and blue traded), see
   the note above — cheap, expected-possible, easy fix.

## Results (2026-08-30, Adafruit Feather RP2350 with HSTX)

**Working, after three real bugs found and fixed on hardware:**

1. **Ribbon cable inserted backwards** — showed as "no signal" on the
   monitor. Diagnosed by flashing CircuitPython and running Adafruit's own
   `picodvi` example (same resolution, same adapter) — it also showed
   nothing until the cable was reseated correctly, which isolated the
   problem to the physical connection rather than any code, ours or
   Adafruit's.
2. **Wrong pixel clock** — `clk_hstx` follows `clk_sys` undivided by
   default (confirmed via [RP2350 datasheet](https://pip.raspberrypi.com/documents/RP-008373-DS-rp2350-datasheet.pdf)
   §12.11.4), and the real pixel clock is `clk_hstx`/5 (fixed by the
   `N_SHIFTS=5` DDR scheme) — not adjustable via `CSR.CLKDIV`, which is
   only the *clock generator* output's own period and must equal
   `N_SHIFTS` to keep clock and data aligned. An initial attempt to "fix"
   the pixel clock by changing `CLKDIV` (5→6) was wrong and made things
   worse (regressed from "out of range" to "no signal" — see git history).
   The actual fix: `set_sys_clock_khz(126000, true)` at the top of
   `main()`, confirmed against
   [`Panda381/DispHSTX`](https://github.com/Panda381/DispHSTX)'s own
   tested video mode table, which explicitly uses "system clock 126 MHz"
   for 640×480@60.
3. **Colour channels rotated** — white and black round-tripped correctly
   (colour-order invariant), every other colour came out as a fixed,
   consistent substitute — a clean 3-way rotation, not a scramble.
   **Root-caused and fixed at the source (2026-08-30)** — see the
   `expand_tmds` comment in `src/main.c` and
   [`../phase0-dvi-colorfix/README.md`](../phase0-dvi-colorfix/README.md)
   for the full derivation and hardware confirmation (on a Metro RP2350 —
   the fix is pure register-level TMDS math, board-independent, and was
   backported here unchanged). Not a lane swap: Adafruit's PicoDVI driver
   values this project originally copied assumed the wrong lane order
   (L0=Red instead of the real DVI/HDMI convention L0=Blue) *and* didn't
   decode to a clean bit-field under RP2350's own documented `ROT`/`NBITS`
   semantics for this project's RGB565 packing — recomputed from scratch
   instead, and validated against `pico-examples`' own RGB332 sample
   before trusting the result.

**Fully confirmed on hardware, including the colour fix**: 8 sharp,
evenly-spaced, correctly-coloured vertical bars (white/yellow/cyan/green/
magenta/red/blue/black, left to right), stable (no flicker/rolling/sync
loss). Black bars either side on a widescreen monitor are expected —
640×480 is a 4:3 signal, shown at native size on a 16:9 panel rather than
stretched. **Stage 1 is done.**

## Next: the real A1

Once this is confirmed, extend to the actual A1 target: 240×240 source,
2× scaled, pillarboxed (80px black bars each side, since 640−480=160),
circular-masked (matching what the badge's own round display would show).
That needs a per-scanline command table where the "real pixel data" width
varies with a circle equation, computed once at mode-set — see main
README §3.4. Also worth then measuring actual CPU load against §3.4's
2–5% estimate, and (per B3/A2) comparing the ring-buffer one-IRQ-per-frame
mechanism against this stage's simpler one-IRQ-per-scanline approach.

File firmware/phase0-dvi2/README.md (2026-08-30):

# Phase 0, Part A — HSTX DVI bring-up (Stage 2: the real A1 target)

Builds on [`../phase0-dvi/`](../phase0-dvi/) (Stage 1, confirmed working
on real hardware — three bugs found and fixed there: flipped ribbon
cable, wrong pixel clock, rotated colour channels; see its README). This
is the actual **A1** target from the design's [Phase 0
plan](../../README.md#phase-0--de-risk-on-the-bench-23-weekends): a
240×240 source, scaled 2×, pillarboxed and circular-masked into 640×480 —
main README §3.1/§3.4.

Board: **Adafruit Feather RP2350 with HSTX**, plus the HSTX-to-DVI
adapter and a monitor.

## What's new vs. Stage 1

- **240×240 source** (not 320×240), pre-doubled horizontally in software
  into 480-wide rows in SRAM — same technique as Stage 1.
- **Pillarbox**: 80px of black on each side of the 480-wide doubled
  content (640−480=160, ÷2=80) — always present.
- **Circular mask**: `row_half_width[]`, one value per output row
  (0–479), computed once at init from the circle equation (diameter
  480, centred on the 480×480 square) — "the per-line descriptor table
  for the circular mask" main README §3.4 describes. Rows near the
  vertical centre show close to the full width; rows near the top/bottom
  show progressively less, down to nothing outside the circle's radius.
- **CPU load measurement**: a busy-loop counter, timed for a fixed window
  before HSTX/DMA starts and again after — printed over USB CDC. The
  design's own estimate (main README §3.4) is 2–5% of one core.

## Known limitations of this measurement (read before trusting the number)

- **Per-row IRQ overhead is higher here than the design's target
  mechanism.** Each active row now takes 4 DMA-completion IRQs (command
  list / left black fill / pixel data / right black fill) instead of
  Stage 1's 2, on top of Stage 1's own already-simpler-than-the-real-design
  starting point (two-channel per-scanline IRQ, not the CPU-efficient
  one-IRQ-per-*frame* ring-buffer mechanism the actual product firmware
  should use — see Stage 1's README). **Treat the measured CPU load as an
  upper bound**, not the number the real design will achieve.
- **USB CDC adds its own interrupt overhead**, present in this build's
  "loaded" measurement but absent from a hypothetical console-free build.
  Stage 1 had no USB CDC at all (pure video, no diagnostics beyond the
  LED) for exactly this reason; Stage 2 trades a small amount of measurement
  purity for actually being able to read the CPU-load number out.
- The busy-loop technique itself is coarse (counts loop iterations in a
  fixed wall-clock window, compares to a no-DVI baseline) — good enough
  to sanity-check "is this in the same ballpark as 2-5%, or way off,"
  not a precise profiler.

## Command-list structure — one HSTX command per row, not three

**First hardware attempt at this stage used three separate
`HSTX_CMD_TMDS`/`TMDS_REPEAT` *commands* per active row (left fill,
pixel-data-priming, right fill) and got "no signal" on the monitor** —
the board stayed alive (LED heartbeat, CPU-load measurement both
completed fine), but no valid picture, worse than Stage 1's "out of
range." Root cause: RP2350 datasheet §12.11.5 — "the command expander
cannot output data on the cycle where it pops a command from the FIFO,
so the expansion shift register is empty for at least one cycle."
Stage 1's proven active line has exactly **one** command word
(`HSTX_CMD_TMDS|640`); the three-command version added two extra
command-boundary stalls per active row that blanking lines don't have,
almost certainly breaking the constant per-line duration a monitor needs
to lock horizontal sync to.

**Fixed by restructuring to match Stage 1's command shape exactly**: one
`HSTX_CMD_TMDS|640` command per active row (`vactive_line`, byte-for-byte
Stage 1's version), consuming its declared 320-word budget across up to
three separate DMA *data* transfers with no command words in between:

1. **Command phase** — `vactive_line`'s single `TMDS|640` command
   (unchanged from Stage 1).
2. **Left fill** — `left_black/2` words of pure black, read from
   `zero_buf` (a static all-zero SRAM buffer, sized for the worst case —
   see its comment for why it's deliberately *not* `const`/flash-resident).
3. **Pixel data** — `half_width` words read directly from `framebuf`, at
   a per-row column offset so the visible span is horizontally centred.
4. **Right fill** — `right_black/2` words, also from `zero_buf`.

`left_black` and `right_black` are always equal by construction (the mask
is centred), and — since `PILLARBOX` alone is 80px — always nonzero, so
phases 2 and 4 always run for every active row; only phase 3 (real pixel
data) can be zero-length, on fully-masked rows near the very top/bottom
of the circle (a zero-length DMA transfer completes immediately and is
harmless, no special-casing needed). The word budget always sums to
exactly 320 (`left_black/2 + half_width + right_black/2` — the pixel-level
identity `left_black + 2·half_width + right_black = 640` divided by 2),
matching `vactive_line`'s declared consumption precisely.

## Test pattern

Same 8-bar pattern and colour table as Stage 1 (see its README for how
those colour values were empirically derived), scaled to the new content
width: 60px/bar (480/8) instead of 80px/bar (640/8).

## Build

```bash
export PICO_SDK_PATH="$HOME/.pico-sdk/sdk/2.3.0"
export PICO_TOOLCHAIN_PATH="$HOME/.pico-sdk/toolchain/14_2_Rel1"
export PATH="$HOME/.pico-sdk/toolchain/14_2_Rel1/bin:$HOME/.pico-sdk/cmake/v3.31.5/bin:$HOME/.pico-sdk/ninja/v1.12.1:$HOME/.pico-sdk/picotool/2.3.0/picotool:$PATH"

cmake -G Ninja -B build .
cmake --build build
```

## Flash

Hold BOOT, tap RESET, copy `build/bringup.uf2` onto `RPI-RP2`. Unlike
Stage 1, this build **does** have USB CDC — open a serial terminal on its
port to see the CPU-load measurement print once at boot.

## What to check

1. **On the monitor**: a circle (not a square) of 8 coloured bars,
   pillarboxed and letterboxed by black, roughly filling the 480×480
   region centred in the 640×480 frame. Top and bottom of the circle
   should curve smoothly, not step raggedly (the mask is computed
   per-pixel-row, so it should look genuinely round, not blocky) —
   though at 480px diameter some visible stepping at extreme angles is
   normal for a pixel-quantised circle, not a bug.
2. **Stability** — no flicker, rolling, or sync loss (same as Stage 1).
3. **On the USB serial console**: the CPU load percentage. Sanity-check
   against the caveats above rather than the raw design target.

## Results (2026-08-30, Adafruit Feather RP2350 with HSTX)

**Working, after one real bug found and fixed on hardware** (see the
"Command-list structure" section above for the full story — first
attempt used three separate HSTX commands per active row and got "no
signal"; fixed by restructuring to Stage 1's proven single-command shape).

**Confirmed on the monitor**: a circle of 8 coloured bars, correctly
pillarboxed and circular-masked, centred in the 640×480 frame. The
circle's outline shows some pixel-level stepping — expected, from the 2px
horizontal quantisation needed for word-aligned DMA reads (documented
above, not a bug) — geometry and colours otherwise correct, stable (no
flicker/rolling/sync loss).

**Colour path since changed (2026-08-30):** the above run used Stage 1's
empirically-compensated `bar_colours[]`/`expand_tmds` (correct-looking
output, root cause not yet found). Both are now replaced with the actual
root-cause fix — see `expand_tmds`'s comment in `src/main.c` and
[`../phase0-dvi-colorfix/README.md`](../phase0-dvi-colorfix/README.md).
Builds cleanly with the new values; not yet re-flashed on the physical
Feather to re-confirm visually (the fix is board-independent register
math, already hardware-confirmed on a Metro RP2350, so this is a
formality rather than an open question — but genuinely not yet done).

**CPU load measurement**:

```
CPU load baseline (DVI not yet running): 1399971 busy-loop iterations / 200ms
CPU load with DVI running: 1304061 busy-loop iterations / 200ms
-> approx 6.9% of one core spent servicing the DVI scanout IRQ
```

**6.9% is close to the design's own 2–5% estimate** (main README §3.4),
despite this stage deliberately using a less efficient mechanism than the
real design calls for (4 DMA-completion IRQs per active row instead of
the target one-IRQ-per-*frame* ring-buffer approach, plus USB CDC's own
interrupt overhead present in this measurement but not in a console-free
build). A more optimised implementation should land inside the original
estimate. **This is a strong validation of the whole mirroring
architecture's core CPU-budget assumption** — the thing A1 exists to
check.

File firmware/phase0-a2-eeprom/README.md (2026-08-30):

# Phase 0, A2 / C4 — emulated hexpansion EEPROM over I2C0 target

Bench firmware for the Metro RP2350, testing two things at once:

- **A2** ([Phase 0 plan](../../README.md#phase-0--de-risk-on-the-bench-23-weekends)) —
  does RP2350's I2C0 target/slave mode actually work, wired the way §4.1 (as adapted for
  this specific bench board — see the main README's A2 section) says it should?
- **C4** — does the badge actually discover and enumerate this emulated EEPROM reliably?
  (§5's "one genuine risk": the badge scans shortly after power-on; if the RP2350 hasn't
  brought its I2C target up yet, the port enumerates as "no EEPROM" and nothing runs.)

Board: **Adafruit Metro RP2350** — see the main README's A2 section for why this replaced
the Feather (GPIO21/CS wasn't accessible there for the SPI0 test; unrelated to this I2C0
test, but same board now used for both).

## Wiring

I2C0 target uses **GPIO4 (SDA) / GPIO5 (SCL)** — a bench-test-only substitution for the
real design's GPIO24/25 (see the main README's A2 section for why: Metro's own GPIO24
isn't broken out, GPIO25 is its onboard NeoPixel). `HEXP_DET` tied to GND, badge `SDA`/`SCL`
to GPIO4/5, `GND` shared, **badge `+3V3` NOT connected** (Metro is USB-powered; no
isolation circuit exists in this bench setup to safely tie two live 3.3V rails together —
see the main README §4.5 for the real design's protection, not present here).

## What this does

- `eeprom_i2c_start()` runs as the **literal first line of `main()`**, before
  `stdio_init_all()` or anything else — §5's mitigation #1 ("bring the I2C target up in
  the first few hundred microseconds ... target < 20 ms from power-good").
- Emulates a 64 KiB I2C EEPROM at address `0x50`, 16-bit addressing, RAM-only (no flash
  persistence — proving reliable *enumeration* is this test's goal, not the product's
  eventual field-update-via-EEPROM-write feature).
- Header at offset 0 matches §1.4's `<4s4sHHIHHH9s` + checksum layout exactly: magic
  `THEX`, manifest `2026`, `fs_offset`=64, `page_size`=64, `total_size`=65536, placeholder
  `vid`/`pid` (0x0000 — **not yet requested from the badge team ("UHB-IF"), §1.4 flags this
  as a "do this early" item, still outstanding**), `unique_id` from the RP2350's own
  factory-programmed chip ID (low 16 bits, via `pico_get_unique_board_id()`), friendly name
  `Hexi-GFX`.
- I2C slave ISR technique (raw register access, ISR in RAM, 2-byte address state machine)
  adapted from
  [`sammachin/rp2040-hexpansion`](https://github.com/sammachin/rp2040-hexpansion) (MIT) —
  a real working THEX-header EEPROM emulator whose header layout independently
  cross-validates this design's own §1.4. Ported from Arduino/RP2040 to bare pico-sdk C
  targeting RP2350's I2C0; pico-sdk's own `gpio_set_function()`/`i2c_init()` are used for
  setup, only the slave-mode register overrides and the ISR itself need raw access (pico-sdk
  has no built-in slave/target API).
- Prints I2C read/write byte counts and a "header has been read" announcement over USB CDC
  whenever they change, so you can watch the badge's scan happen live.

## Build

```bash
export PICO_SDK_PATH="$HOME/.pico-sdk/sdk/2.3.0"
export PICO_TOOLCHAIN_PATH="$HOME/.pico-sdk/toolchain/14_2_Rel1"
export PATH="$HOME/.pico-sdk/toolchain/14_2_Rel1/bin:$HOME/.pico-sdk/cmake/v3.31.5/bin:$HOME/.pico-sdk/ninja/v1.12.1:$HOME/.pico-sdk/picotool/2.3.0/picotool:$PATH"

cmake -G Ninja -B build .
cmake --build build
```

## Flash

Hold BOOT, tap RESET, copy `build/bringup.uf2` onto `RPI-RP2`.

## What to check

1. **USB serial console**: should print the startup banner, then activity lines as I2C
   traffic happens.
2. **Plug the hexpansion into the badge** (or use the badge's Hexpansions app to trigger a
   scan on the port it's in). Watch for the "*** Header (byte 0) has been read ***" line —
   that's the badge's own enumeration scan finding this EEPROM.
3. **Does the badge itself recognise the port as occupied** — check the badge's own UI/menu
   for the hexpansion slot in question. It likely won't run an *app* yet (no LittleFS
   filesystem is present past the header, and `vid`/`pid` are placeholders), but it should
   at minimum detect *something* answering at `0x50`.

## Results (2026-08-30, Metro RP2350, real badge)

**Worked on the first attempt — no bugs found.**

```
phase0-a2-eeprom: I2C0 target 0x50 running (started before stdio/USB init)
  Plug the hexpansion into the badge now, or run the badge's Hexpansions app
  to trigger a scan. Watching for reads/writes below.

  I2C activity: 632 bytes read, 0 bytes written (total)
  *** Header (byte 0) has been read -- badge has scanned this EEPROM ***
  I2C activity: 664 bytes read, 0 bytes written (total)
```

The badge found the EEPROM and read well past the 32-byte header (632, then 664 bytes) —
strong evidence the header **validated correctly** (magic `THEX`, manifest `2026`, checksum
all passed), since a failed check would have made the badge stop at byte 32. The extra reads
are almost certainly the badge attempting to mount a LittleFS filesystem at `fs_offset=64`
(§1.4, 512-byte blocks) and finding nothing there — expected, since no real filesystem image
was provided; that wasn't this test's goal.

**No enumeration race observed** — confirms §5's mitigation #1 (I2C target started as the
literal first line of `main()`) is sufficient in practice, at least for this single test.
Settles main README risk 1 (§9) in principle; the formal 50×-cold-plug reliability/timing
measurement C4 calls for is still outstanding.

**C4's 50×-cold-plug run cannot happen on this bench rig at all, not just "not yet done"
(2026-08-30).** C4 needs to measure worst-case time from **port power-on** to the badge's
first I2C read, against the RP2350's time-to-I2C-ready — but this rig's Metro is
USB-powered, with badge `+3V3` deliberately left unconnected (see Wiring above: "no
isolation circuit exists in this bench setup to safely tie two live 3.3V rails together").
So unplugging/replugging the hexpansion into the badge port never power-cycles the RP2350 at
all — it stays continuously powered and running throughout every "cold" plug, which is
exactly the condition C4 needs to NOT be true to measure anything. Cold-plug timing needs
either the real product (RP2350 powered from the hexpansion's own +3V3, badge-supplied,
Phase 2) or a bench modification that actually power-cycles the RP2350 from the badge rail
with isolation from USB during the test — out of scope for a quick Phase 0 bench check. C4
moves to Phase 2 rather than staying an open Phase 0 item.

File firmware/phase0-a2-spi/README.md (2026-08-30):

# Phase 0, A2 — SPI0-slave half

Bench firmware for the Metro RP2350, testing whether RP2350's SPI0 in slave mode actually
works as wired for the badge link — see the main README's A2 section for the bench board
choice/wiring, and section 4.1's "resolved" note on how the `HS_F/G/H/I` SPI role mapping
was chosen (this project's own free choice, matched by the badge-side script here).

Companion to [`../phase0-a2-eeprom/`](../phase0-a2-eeprom/) (the I2C0-target half, already
confirmed working on real hardware). **Unlike I2C0, nothing happens here until something on
the badge actively drives SPI0 as master** — the badge doesn't touch these pins on its own,
so this test needs both the RP2350 firmware below *and* [`badge_test.py`](badge_test.py)
run against the badge.

## Wiring

Same as `phase0-a2-eeprom` for GND/HEXP_DET, plus the four SPI0 pins:

| Badge signal | RP2350 GPIO | Role |
|---|---:|---|
| `HS_F` | 20 | MOSI (badge → RP2350) |
| `HS_G` | 21 | CS |
| `HS_H` | 22 | SCK |
| `HS_I` | 23 | MISO (RP2350 → badge) |

## What this does

- RP2350 side (`src/main.c`): brings up SPI0 as slave on the four pins above (register-level
  technique — `spi_init` + `spi_set_slave` + `gpio_set_function` on all 4 pins, CS included
  — same pattern as the official
  [`raspberrypi/pico-examples`](https://github.com/raspberrypi/pico-examples)
  `spi/spi_master_slave/spi_slave` example, BSD-3, not copied verbatim). Blocks on
  `spi_write_read_blocking()` waiting for a 16-byte transfer from the badge; transmits a
  fixed known pattern (`0xA0..0xAF`) back on every round, and prints whatever it received
  over USB CDC.
- Badge side (`badge_test.py`): a MicroPython script using `machine.SPI` as master on the
  ESP32-S3's matching `hs_x` pins for **badge port 3 (C)** specifically (`MOSI=GPIO34,
  CS=GPIO33, SCK=GPIO47, MISO=GPIO48` — see the script's own header comment for the port
  table if the hexpansion is in a different port). Sends an ascending byte pattern
  (`0x00..0x0F`), 3 rounds, 500 ms apart, printing what came back.

## Build (RP2350 side)

```bash
export PICO_SDK_PATH="$HOME/.pico-sdk/sdk/2.3.0"
export PICO_TOOLCHAIN_PATH="$HOME/.pico-sdk/toolchain/14_2_Rel1"
export PATH="$HOME/.pico-sdk/toolchain/14_2_Rel1/bin:$HOME/.pico-sdk/cmake/v3.31.5/bin:$HOME/.pico-sdk/ninja/v1.12.1:$HOME/.pico-sdk/picotool/2.3.0/picotool:$PATH"

cmake -G Ninja -B build .
cmake --build build
```

## Running the test

1. Flash `build/bringup.uf2` onto the Metro (hold BOOT, tap RESET, copy the file).
2. Open a serial terminal on the Metro's USB CDC port. It'll print the pin config and then
   block, waiting — nothing else happens until step 3.
3. Run `badge_test.py` against the badge:
   ```bash
   mpremote connect COMx exec "$(cat badge_test.py)"
   ```
   **This interrupts whatever's running on the badge's screen** (any `mpremote` command
   does — see the project's own mpremote-gotcha notes) — expected here, this is a
   deliberate test run, not passively watching an app. The badge will need resetting
   afterward to get back to normal use.
4. Watch both consoles: the badge's should show 3 rounds of "sent ... received ...", and the
   Metro's should show matching "round N: transferred 16 bytes. Received from badge (MOSI):
   00 01 02 ... 0f" lines.

## What success/failure looks like

- **Working**: Metro's console shows the badge's ascending `00..0f` pattern; badge's console
  shows the Metro's fixed `a0..af` pattern. Both sides received exactly what the other sent.
- **No signal at all** (Metro never unblocks): SPI0 isn't seeing clock activity — check the
  SCK wiring (`HS_H`↔GPIO22) first, then CS (without CS asserted low, the PL022 slave
  peripheral won't sample MOSI/SCK at all — confirmed from the RP2350 datasheet's SPI
  chapter, this isn't optional).
- **Metro unblocks but data is garbled**: check SPI mode (`polarity`/`phase`) match between
  both scripts (both use mode 0 here — CPOL=0, CPHA=0), and bit order (both default to
  MSB-first).

## Results (2026-08-30, Metro RP2350, real badge)

**First attempt: RP2350 never unblocked.** Badge's `badge_test.py` completed all 3 rounds
without error, but received all zeros back (not the expected `a0..af`) — and the Metro's
console never printed past the startup/waiting banner, meaning `spi_write_read_blocking()`
never saw a complete 16-byte transfer. Since MicroPython's master-mode SPI has no handshake
with the slave, the badge finishing cleanly does **not** prove the RP2350 received anything —
a mode/bit-order mismatch would still let bytes clock in (just garbled), so a full stall
points at CS or SCK not reaching the RP2350 at all (see the datasheet-sourced note above).

Also found in passing (not yet confirmed as the cause, but a real conflict): this board's
`PICO_DEFAULT_LED_PIN` is GPIO23 — the same pin `PIN_MISO` uses. `gpio_set_function()` on
GPIO23 overrides the LED's SIO function to SPI TX, so this is survivable for the SPI signal
itself (the LED is just a few-mA load), but it's a real, board-specific pin conflict worth
fixing before this becomes anything beyond a bench test.

Built `src/gpio_probe.c` (second target, `build/gpio_probe.uf2`) to isolate wiring from SPI
peripheral config: watches MOSI/CS/SCK/MISO as plain SIO inputs with edge-count IRQs, no SPI
peripheral involved at all. First run (against the then-current mode-0, per-byte-CS-toggle
script) showed clean CS/SCK/MOSI activity matching the badge's transfer — wiring judged good
at that point.

**Second attempt (v3: mode 3, CS held low for the whole burst) — also failed, differently.**
Badge received all `0xff` this time (not all-zero like v1), and the Metro's console again
never printed anything — `spi_write_read_blocking()` still never unblocked. Root-caused with
three more probes, all flashed and run against real hardware in this session (via
`picotool load -f` / `picotool reboot -f` — no BOOTSEL button needed, the running app's own
USB connection is enough for picotool to force a reboot):

1. **`src/spi_loopback_test.c`** (`spi_lbm.uf2`) — SPI0 master mode with the PL022's internal
   loopback bit (LBM) set, entirely bypassing external pins. **Result: MATCH** — sent
   `10..1f`, received `10..1f` back, 154 µs. **The SPI0 peripheral itself is functional.**
2. **`src/spi_status_probe.c`** (`spi_status_probe.uf2`) — polls `SSPSR` directly instead of
   calling `spi_write_read_blocking()`, so it can show partial/failed activity that the
   blocking call would hide. FUNCSEL readback confirmed all 4 pins correctly muxed to SPI
   (`MOSI=1 CS=1 SCK=1 MISO=1`, matching `GPIO_FUNC_SPI`); `cr0`/`cr1` confirmed slave mode 3
   as configured (`SSE=1 MS=1 DSS=7 SPO=1 SPH=1`). **Result: `SR` never changed at all**
   across a full 3-round badge transfer — `BSY` and `RNE` stayed 0 throughout. Not corrupted
   data, not partial reception — the peripheral never reacted to the transfer at all.
3. **`src/gpio_probe.c`, re-run against the current v3 script** (the first gpio_probe result
   above predates the mode-3/CS-continuous change, so it needed re-confirming). **This is the
   finding that explains everything above it:**

   ```
   MOSI=0(edges=120)  CS=1(edges=0)  SCK=1(edges=768)  MISO=1(edges=63)
   ```

   Over 3 rounds × 16 bytes: **SCK shows exactly 768 edges** (16 bytes × 8 bits × 2 edges ×
   3 rounds — a perfect match) and **MOSI shows 120 edges** of real data activity. **CS shows
   zero edges and never leaves logic 1**, despite `badge_test.py` explicitly calling
   `cs.value(0)` before every round and `cs.value(1)` after. SCK and MOSI are proven to be
   wired correctly and arriving cleanly; **CS (`HS_G`, RP2350 GPIO21) is not** — the badge is
   driving it, but the RP2350 pin never sees it move. This is consistent with every failure
   mode observed so far: per the datasheet note above, the PL022 slave will not sample
   MOSI/SCK at all without CS asserted low, so a CS line that never reaches the RP2350 fully
   explains both the v1 all-zero result and the v3 zero-register-activity result, with no need
   to invoke an SPI-mode or silicon-errata explanation for either. (The CPOL=1/CPHA=1 research
   that produced v3 is still probably correct per
   [pico-sdk#941](https://github.com/raspberrypi/pico-sdk/issues/941) and the
   [Pico 2 SPI-slave forum thread](https://forums.raspberrypi.com/viewtopic.php?t=375430) — it
   just wasn't the blocking problem here, and can't be properly evaluated until CS itself is
   confirmed reaching the chip.)

**Conclusion: this was a physical wiring problem specific to the CS line** — `HS_G` on the
badge side to GPIO21 (`SCL` on the Metro's silkscreen) on the RP2350 side (bench protoboard
wiring, per this project's own free choice of `HS_x` SPI roles in the main README's §4.1).
SCK and MOSI on the same connector, same protoboard, same wiring pass, both worked
perfectly throughout, which pointed at a single bad connection (loose/broken wire, missed
pad, cold joint) rather than a systemic issue.

## Fixed and confirmed working (2026-08-30, same session)

**Rewired the CS line and re-ran the full diagnostic sequence. Working end to end.**

1. `gpio_probe` re-run: `CS` now shows exactly 6 edges over 3 rounds (2 per round — low then
   high), matching `SCK`'s 768 and `MOSI`'s 120 exactly. Confirms the physical fix.
2. `spi_status_probe` re-run: `SR`'s `RNE` bit now toggles continuously through the whole
   transfer, and cumulative `rx_bytes` reaches **exactly 48** (16 bytes × 3 rounds) — the
   PL022 slave is now receiving every byte. (Its all-zero "received from RP2350 TX" in the
   badge's own printout at this step is **not** a transmit-path finding — this probe never
   loads the TX FIFO with real data, so that result is expected and uninformative for MISO.)
3. **`bringup` (the real firmware) re-run — full bidirectional match:**
   - Badge received `a0 a1 a2 ... af` — the RP2350's fixed test pattern, exactly, all 3
     rounds.
   - Metro's console showed `Received from badge (MOSI): 00 01 02 03 04 05 06 07 08 09 0a 0b
     0c 0d 0e 0f` — the badge's ascending pattern, exactly, all 3 rounds.

**A2's SPI0-slave half is done: confirmed working on real hardware**, mode 3 (CPOL=1,
CPHA=1), CS held low for the whole burst, matching A2's I2C0-target half
(`../phase0-a2-eeprom/`, already confirmed working). Both halves of the SPI0 role mapping
chosen in the main README's §4.1 are now hardware-verified, not just planned.

## C3 — SPI link speed sweep and a real 115,200-byte frame (2026-08-30, same session)

Bench wiring for this run: the badge's edge connector **is** in circuit — via the official
`emfcamp/badge-2024-hardware/hexpansion` devkit board, plugged into the badge port as
designed — but the last leg, from that devkit board's own header pins to the Metro's
headers, is **dupont jumpers**. So this measures the real connector plus an extra, worse
stretch of wire on top of it, not a raw badge-pin-to-Metro dupont run. Still expect a lower
ceiling than the eventual product PCB (no devkit-to-Metro leg at all, direct short traces),
but higher than if the connector itself were being bypassed. No RP2350 firmware change was
needed to sweep badge-side rates: in
slave mode the PL022 derives its bit timing from whatever SCK the master drives (`main.c`'s
own comment), so `bringup.uf2` self-adapts across rates.

### Speed sweep (`spi_speed_sweep.py`, 5 rounds/rate, 16-byte known pattern)

| Rate | Result |
|-----:|---|
| 100 kHz | 5/5 clean |
| 250 kHz – 20 MHz | 4/5 clean — **always the same deterministic corruption on round 0 only** |
| 30 MHz | 0/5 — genuinely corrupted, different garbage each round |
| 40 MHz | 1/5 — genuinely corrupted, different garbage each round |

**The 250 kHz–20 MHz "failures" are not a link problem.** Every one of them shows the exact
same 16 bytes (`41 43 45 47 49 4b 4d 4f 51 53 55 57 59 5b 5d 5e` — `[65, 67, 69, ... 94]`
decimal) on round 0, and only round 0, regardless of rate — a fixed, repeatable pattern, not
noise. A first run of `badge_test.py` on its own showed the identical signature: round 0
corrupted, rounds 1–2 clean, on a link already independently proven working. That points at
the **badge's own ESP32-S3 SPI master peripheral producing a corrupted first transaction
right after `machine.SPI(...)` is constructed** — every subsequent transfer on the same
object is clean — rather than anything wrong with the RP2350 slave, the wiring, or the mode.
The sweep script builds a fresh `SPI` object per rate, so it hits this once per rate; a
script that reuses one `SPI` object and only reconfigures baudrate would likely avoid it
entirely, but wasn't necessary to draw the conclusion here.

30 MHz and 40 MHz are different in kind — different garbage every round, no fixed pattern —
consistent with genuine bit errors from dupont-wire signal integrity at that speed, matching
the main README §1.2 expectation that the badge's matrix-routed (non-IOMUX) HS pins top out
around 40 MHz even in the best case.

**Conclusion: 100 kHz–20 MHz is fully reliable** (after the first, discardable transaction on
a freshly constructed master object); real degradation starts at 30 MHz, over dupont wire.

### Real frame push (`src/spi_frame_test.c` + `spi_frame_timing.py`)

One 115,200-byte transfer (240×240 RGB565 — the badge's actual mirrored-framebuffer size,
main README §3.1), preceded by one small discarded warmup transfer (see above), with both
sides verifying every byte against a known pattern.

| Rate | Result | Badge-measured wire time | vs. theoretical minimum | Full-frame-equivalent |
|-----:|---|---:|---:|---:|
| 10 MHz | **0/115200 mismatches, both sides** | 93,673 µs | 92,160 µs → **98.4% efficiency** | 10.7 fps |
| 20 MHz | **0/115200 mismatches, both sides** | 47,586 µs | 46,080 µs → **96.7% efficiency** | 21.0 fps |

**Use the badge-side timing, not the RP2350's.** The RP2350 firmware's own elapsed-time
number (4.6 **seconds**, both rates — obviously bogus) is a measurement artifact, not a
finding: its clock starts right after the warmup, before the badge has finished the slow job
of building a 115,200-byte `bytearray` via a Python generator expression in MicroPython —
that CPU-bound Python time lands entirely inside the RP2350's "waiting for CS" window and
gets counted as transfer time. The badge's own measurement, taken only around the actual
`spi.write_readinto()` call, is unaffected by this and lands within 2–4% of the
clock-rate-only theoretical minimum both times — that's the trustworthy number.

**C3 is settled for the devkit-connector-plus-dupont-leg bench case: a full mirrored frame
moves in well under the 100 ms budget C1 needs (worst real app measured: 14.3 fps → ~70
ms/frame) even at 10 MHz**, with headroom to spare at 20 MHz and likely beyond (30/40 MHz
weren't re-tried with a full frame — the small-packet sweep already shows they're unreliable
on this wiring). The product PCB (no dupont leg at all) is expected to do at least this well;
re-run once that exists rather than treating this as the final number.

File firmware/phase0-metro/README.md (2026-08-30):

# Phase 0, Part B — Adafruit Metro RP2350 bring-up

Bench firmware for the Metro RP2350 bring-up in the design's [Phase 0
plan](../../README.md#phase-0--de-risk-on-the-bench-23-weekends), Part B
(the PSRAM + microSD bench, RP2350B).

Board: **Adafruit Metro RP2350 with PSRAM** (RP2350B, 8 MB PSRAM, 16 MB
flash — the PSRAM variant, not the plain Metro RP2350).

See also `../phase0-feather/` — B3, the RP2350A comparison bench. It
reuses copies of this project's `ctx_bench.c`/`psram_dma_bench.c`/
`third_party/ctx/` (both are board-agnostic) rather than sharing a
library between the two: this is disposable Phase 0 bench code, not the
eventual product firmware, so two small independent copies beat coupling
two separate bench projects together.

## Status

- [x] Toolchain + custom board header bring-up: blink the onboard red LED
      (GPIO23), heartbeat over USB CDC.
- [x] **PSRAM bring-up** (GPIO47, QMI CS1) via pico-sdk's official
      `hardware_psram` library. Auto-detects size and self-tests by
      writing/reading back a pattern across the whole chip, timed.
- [x] **B1 — ctx rasterisation benchmark at 640×480** (the highest-value
      Phase 0 measurement — see README §8). `ctx` vendored under
      `third_party/ctx/` (single-header C, LGPL-3.0-or-later — see
      `third_party/ctx/VENDORED.md`). **Measured on hardware: 2.9 fps
      typical scene, 0.7 fps worst case — too slow for animation.**
      Decomposed to find out why: see below. Main README §3.2 and risk
      17 updated with these numbers.
- [x] **B2, microSD half** — SPI0 (GPIO34/35/36 SCK/MOSI/MISO, CS GPIO39)
      via `carlk3/no-OS-FatFS-SD-SDIO-SPI-RPi-Pico` (Apache-2.0) +
      elm-chan's FatFs, vendored as a submodule under `third_party/`.
      **Measured on hardware: mount, capacity report, and write/read-back
      all PASS** (FAT32, ~7.5 GB card). Card-detect (GPIO40) deliberately
      unused — see below.
- [x] **B2, PSRAM-backed scanout half** — DMA-driven bulk reads out of
      the PSRAM framebuffer (`src/psram_dma_bench.c`), simulating what
      real HSTX scanout would do (§3.3's "needs measurement" mode, target
      ~37 MB/s). **Measured on hardware: ~27.1 MB/s — short of the ~37
      MB/s target, root-caused to the PSRAM clock ceiling (75 MHz is the
      fastest reachable at stock `clk_sys` 150 MHz), not a config bug.**
      See below and main README §3.3.
- [ ] B3 — run the same firmware on the RP2350A Feather (Part A) to compare.

### PSRAM: using pico-sdk's official driver, not a hand-rolled one

The RP2350 PSRAM QMI dance (direct-mode ID read, then switching XIP CS1
into quad mode with M1_TIMING/M1_RFMT/M1_RCMD/M1_WFMT/M1_WCMD) isn't
something we wrote ourselves. It turns out **pico-sdk 2.3.0 (released
2026-07-03) added an official `hardware_psram` library** — BSD-3, written
by Raspberry Pi, with auto-detection of both the CS pin and chip size. That
landed after this repo started, so it wasn't in the pico-sdk 2.2.0 this
project began on.

This avoided a real alternative: the most complete third-party reference we
found (fanpico's `psram.c`) is GPL-3.0-or-later, which would have been a
heavier license obligation than intended — this design already carries one
LGPL dependency (ctx, for B1), and picking up a second, stronger copyleft
one for something as core as PSRAM deserved a deliberate decision, not an
accident. The official driver made that decision moot.

Board header just sets `PICO_PSRAM_CS_PIN 47` and
`PICO_AUTO_DETECT_PSRAM_SIZE 1` — the same idiom Raspberry Pi's own
`adafruit_feather_rp2350.h` uses, for the same reason (Adafruit sells this
board both with and without PSRAM fitted). PSRAM then initializes itself
before `main()` runs; `src/main.c` just calls `psram_is_available()` /
`psram_get_size()` and runs a write/read-back self-test.

**Upgrading to SDK 2.3.0 required a matching `picotool` 2.3.0** — the SDK's
CMake enforces picotool/SDK version parity. No prebuilt Windows binary
ships in picotool's own GitHub releases (source tarball only), but
`raspberrypi/pico-sdk-tools` release `v2.3.0-1` has
`picotool-2.3.0-x64-win.zip`, installed at `~/.pico-sdk/picotool/2.3.0/`
alongside the existing 2.2.0-a4 (kept, in case other projects still target
2.2.0).

### B1: ctx benchmark

`src/ctx_bench.c` renders two hand-built scenes into a 640×480
RGB565_BYTESWAPPED framebuffer in PSRAM, 10 iterations each, timed with
min/avg/max and derived fps:

- **raw write** — not a ctx scene: a plain sequential scalar write of the
  same byte count straight to the PSRAM framebuffer pointer. Reference
  upper bound for "solid fill" below.
- **solid fill** — the cheapest possible ctx draw call: one opaque,
  axis-aligned, full-canvas rectangle. Isolates "cost of one full-canvas
  pass through ctx's rasteriser" from gradient/shape cost.
- **typical** — a handful of rounded-rect cards with icon circles and a
  header gradient, roughly the complexity of a simple Tildagon app screen.
- **worst case** — ~160 overlapping translucent circles/rects plus a
  full-screen radial gradient, to stress alpha-compositing and AA hard.

The first measurement run used ctx's own default `CTX_RASTERIZER_AA`
(15) instead of the badge's actual setting (5); fixed, but the fix only
changed timing by ~7% — nowhere near the 3x expected — which is why
**raw write** and **solid fill** were added: to find out what's actually
dominating (PSRAM write bandwidth vs. ctx's own rasterisation cost)
instead of guessing.

These are **not** a drawlist captured from a real badge app — that needs
the badge itself plus the `display.get_fb()` upstream patch (Phase 0 Part
C, not started). They're a reasonable stand-in for "how fast can this
chip rasterise ctx content" until a real captured drawlist exists; see
`third_party/ctx/VENDORED.md` for the caveats. `ctx_bench_run()` skips
itself (prints why) if PSRAM isn't available or is too small for the
framebuffer.

#### Measured results (Metro RP2350 with PSRAM, 2026-08-30)

```
raw write   min   69.69 ms  avg   70.63 ms ( 14.2 fps)   [~8.70 MB/s]
solid fill  min  169.29 ms  avg  169.38 ms (  5.9 fps)
typical     min  343.10 ms  avg  343.21 ms (  2.9 fps)
worst case  min 1426.38 ms  avg 1426.57 ms (  0.7 fps)
```

Reading the decomposition: **raw write** (70.6 ms) is a hard floor —
even a hypothetically free rasteriser can't beat it, because that's just
what it costs to push 614 KB into PSRAM one scalar store at a time. ctx's
**solid fill** (169 ms, the cheapest possible draw call) is ~2.4× that
floor, meaning roughly 40% of even the cheapest frame's cost is PSRAM
write bandwidth rather than ctx's own rasterisation work. **typical**
(343 ms) is ~2× solid-fill; **worst case** (1426 ms) is ~8.4× solid-fill,
reflecting the full-screen radial gradient (expensive per-pixel
evaluation) plus 160 shapes with alpha blending.

DMA wasn't tried and wouldn't help here regardless: ctx's rasteriser
fills spans with plain C stores, not DMA, no matter where the target
buffer lives. DMA only helps the *scanout* (HSTX) side, which this
benchmark doesn't touch.

**Conclusion:** full-frame ctx drawlist forwarding can't support
animation on this chip (2.9 fps best case, hand-built scene). It may
still work for occasional full redraws of static screens (e.g. a
settings menu redrawn once on navigation) where a few hundred ms of
latency is acceptable. See the main README §3.2 and risk 17 for what
this means for the design.

ctx was configured stripped down for this target: no text/fonts, no
XML/parser/formatter/events (desktop-oriented features), and only the one
pixel format actually used — see the `#define`s at the top of
`ctx_bench.c`. Adds ~110 KB to the flash image (`arm-none-eabi-size`:
~169 KB text total vs. ~59 KB before ctx was added) — a non-issue against
16 MB of flash.

### B2: PSRAM-backed scanout (DMA reads)

`src/psram_dma_bench.c` measures the opposite direction from B1: DMA
engine reads *out of* the PSRAM framebuffer, rather than ctx's CPU-driven
writes into it. This is what real HSTX scanout would actually be doing —
§3.3 rates this mode "Medium — needs measurement", target ~37 MB/s for
640×480@60. Two shapes, mirroring B1's bulk-vs-decomposed approach:

- **bulk** — one 256 KB DMA transfer, PSRAM into a static SRAM buffer.
  The achievable ceiling, no per-transaction setup cost.
- **per-line** — 480 separate DMA transfers of one 1280-byte
  (640×RGB565) scanline each, back to back, totalling one frame's worth
  of bytes. Closer to how real chained per-line HSTX descriptors would
  actually drive this (§3.4) — captures per-transaction setup overhead
  the bulk number doesn't.

Reads via the PSRAM **uncached** XIP alias (`XIP_NOCACHE_NOALLOC_BASE`,
not the `XIP_BASE`-relative one main.c/ctx_bench.c use) deliberately: real
scanout reads different framebuffer content every frame, so it should
never hit in the small on-chip XIP cache. Using the cached alias here
could make repeated timing iterations look faster than a real streaming
scanout would be — same spirit as B1's raw-write/solid-fill decomposition,
measure the thing that's actually representative rather than whatever's
convenient.

DMA channel is claimed with `dma_claim_unused_channel`, so this coexists
fine with anything else on the board that also uses DMA (SD card SPI
DMA, USB). Skips itself if PSRAM isn't available or no DMA channel is
free.

#### Measured results (Metro RP2350 with PSRAM, 2026-08-30)

```
bulk     256 KB in one transfer   min   9.21 ms  avg   9.22 ms  max   9.27 ms  [~27.13 MB/s]
per-line 480 x 1280 B (one frame)   min  21.64 ms  avg  21.65 ms  max  21.68 ms  [~27.07 MB/s, 46.2 fps]
```

DMA is a real win over B1's CPU-scalar path — ~3.3× B1's raw-write
number (27.1 vs 8.3 MB/s) — and bulk vs. per-line being nearly identical
confirms per-transaction DMA setup overhead isn't the bottleneck; this
is close to the actual sustained hardware ceiling for whatever clock
PSRAM is running at.

**But 27 MB/s falls short of the ~37 MB/s continuous 640×480@60 scanout
actually needs** (not a target to merely beat — that's the literal
sustained byte rate a fixed 60 Hz signal demands: 640×480×2 bytes ×
60 fps ≈ 35.2 MB/s). A ~24% shortfall.

**Root cause, confirmed by a `clk_sys`/QMI CLKDIV diagnostic added to
`main.c`'s PSRAM section:**

```
clk_sys 150.0 MHz, PSRAM QMI CLKDIV 2 -> PSRAM clock ~75.0 MHz
(quad SPI, theoretical read ceiling ~35.8 MB/s)
```

27.1 MB/s achieved is ~76% of that 35.8 MB/s theoretical ceiling —
ordinary QSPI protocol overhead (command/address/dummy cycles, periodic
chip-select toggling for PSRAM page refresh), not a bug.

**This isn't a config problem to tune away — 75 MHz is already the
fastest PSRAM clock reachable at `clk_sys` 150 MHz.** `hardware_psram`'s
driver won't use divisor 1 above 100 MHz (safety margin below the
PSRAM's 133 MHz rating), and 150/2 is the only other integer divisor.
So even a hypothetical zero-overhead read at this clock (35.8 MB/s)
still falls short of the ~35-37 MB/s requirement. Closing the gap needs
a higher `clk_sys` — an RP2350 overclock (e.g. ~266 MHz would allow a
divisor-2 133 MHz PSRAM clock, the chip's full rating) — which is a real
hardware/reliability decision for a later phase, not a Phase 0 firmware
change. Full writeup, including what this means for the design, in the
main README §3.3.

**Doesn't affect v1** — mirroring's framebuffer lives entirely in SRAM,
never touches PSRAM. Combined with B1's finding (ctx rasterisation into
this same buffer is too slow for animation), the PSRAM-backed 16bpp
advanced display mode looks suited to occasional/static content at
stock clocks, not continuous animated use — two independent
measurements pointing the same direction.

### B2: microSD

`src/sd_bench.c` + `src/hw_config.c`, on top of a vendored (submodule)
copy of `carlk3/no-OS-FatFS-SD-SDIO-SPI-RPi-Pico` under
`third_party/no-OS-FatFS-SD-SDIO-SPI-RPi-Pico/` (Apache-2.0, wraps
elm-chan's FatFs — its own permissive BSD-1-Clause-style license). Chose
this over hand-rolling the SD-over-SPI protocol (CMD0/CMD8/ACMD41 init
sequence, R1/R7 response parsing, CRC, the 400 kHz-then-fast-clock dance)
for the same reason as pico-sdk's `hardware_psram`: a well-tested existing
implementation beats a hand-written one for something this fiddly to get
right at the protocol level.

**File-API only, deliberately never raw sectors.** This runs against
whatever card is actually inserted on the bench, which may have other
data on it — a distinctly-named test file (`phase0test.txt`,
`phase0bw.bin`, deleted after use) can't clobber that, a raw sector write
could.

`hw_config.c` wires the library to this board's socket: SPI0 on GPIO34
(SCK) / 35 (MOSI) / 36 (MISO), CS on GPIO39, matching
`boards/adafruit_metro_rp2350.h`. **Card-detect (GPIO40) is deliberately
not wired up** — its active-high/low polarity for this specific socket
isn't confirmed against Adafruit's schematic, and a wrong guess would
make the code misreport "no card" rather than just letting `f_mount()`'s
own success/failure say so.

`sd_bench_run()` mounts, prints capacity/free space, runs the
write/read-back correctness test, then (only if that passed) times
writing a 256 KB file in 4 KB chunks for a rough file-I/O bandwidth
number. Prints a clear "skipped" message and returns cleanly — never
panics — if there's no card or the mount fails for any reason.

**Needed a prebuilt `pioasm`, not just a matching SDK/picotool.** The
library's CMake unconditionally builds its SDIO backend too (even though
we only use SPI), which needs `pioasm` to compile a `.pio` file. Building
`pioasm` from source needs a host C++ compiler, which isn't installed on
this machine (see the PSRAM section above re: the same gap blocking a
from-source `picotool` build). Fix: `raspberrypi/pico-sdk-tools` release
`v2.3.0-1`'s `pico-sdk-tools-2.3.0-x64-win.zip` bundle has a prebuilt
`pioasm.exe`, installed at `~/.pico-sdk/tools/2.3.0/pioasm/`. `CMakeLists.txt`
points at it by default (`pioasm_DIR`) so this is transparent on rebuild.

#### Measured results (Metro RP2350 with PSRAM, ~7.5 GB FAT32 card, 2026-08-30)

```
mounted: 7503.9 MB total, 7503.9 MB free, FAT type 3
write/read-back test (phase0test.txt): PASS
write bandwidth: 262144 bytes in 287.75 ms (~0.87 MB/s)
```

Mount, capacity reporting, and the write/read-back correctness test all
passed cleanly — confirms the SPI wiring, chip select, and FatFs stack
all work on real hardware. FAT type 3 = FAT32, as expected for a card
this size.

**0.87 MB/s is a deliberately conservative number, not a driver
limitation.** `hw_config.c` set `baud_rate` to 12.5 MHz for first
bring-up (reliability over speed); at that clock, 1.5 MB/s is the
single-bit-SPI theoretical ceiling, so ~0.87 MB/s (58% of that) is in
the range expected once per-block command/response overhead is
accounted for. Raising the SPI clock (common SD-over-SPI cards handle
20-25 MHz) is the obvious next tuning step if this number ends up
mattering, but wasn't necessary to prove B2's actual question — does
this stack work at all on this board — which it does.

## Board header

`boards/adafruit_metro_rp2350.h` is a hand-written board header — Adafruit
doesn't ship one for bare pico-sdk (only Arduino-Pico and CircuitPython).
Pin numbers came from Adafruit's own pinout page
(learn.adafruit.com/adafruit-metro-rp2350/pinouts); the PSRAM CS pin
(GPIO47) is the RP2350B's fixed QMI CS1 alternate-function pin, not a
board-specific choice, confirmed against Pimoroni's Pico Plus 2 RP2350 and
Raspberry Pi's own Adafruit Feather RP2350 board headers in pico-sdk (same
pin, same PSRAM idiom).

## Build

This repo has a submodule (the SD/FatFs library); clone or update it first:

```bash
git submodule update --init third_party/no-OS-FatFS-SD-SDIO-SPI-RPi-Pico
```

Uses the pico-sdk toolchain already cached by the Raspberry Pi Pico VS Code
extension at `~/.pico-sdk` (SDK 2.3.0, matching picotool 2.3.0, and a
prebuilt `pioasm` were added there for this project — see above). From
this directory:

```bash
export PICO_SDK_PATH="$HOME/.pico-sdk/sdk/2.3.0"
export PICO_TOOLCHAIN_PATH="$HOME/.pico-sdk/toolchain/14_2_Rel1"
export PATH="$HOME/.pico-sdk/toolchain/14_2_Rel1/bin:$HOME/.pico-sdk/cmake/v3.31.5/bin:$HOME/.pico-sdk/ninja/v1.12.1:$HOME/.pico-sdk/picotool/2.3.0/picotool:$PATH"

cmake -G Ninja -B build .
cmake --build build
```

Or open this folder in VS Code with the Raspberry Pi Pico extension — point
its SDK version setting at 2.3.0.

## Flash

Hold BOOT, tap RESET (or plug in while holding BOOT) to drop the Metro into
UF2 bootloader mode, then copy `build/bringup.uf2` onto the `RPI-RP2` drive
that appears. Or, with the board already in USB-CDC-running mode:

```bash
picotool load -f build/bringup.uf2
```

## Expected result

On boot, the USB CDC serial port prints PSRAM detection (size, CS pin),
the self-test result (PASS/FAIL, time, throughput), the B1 ctx
benchmark's scene timings, the B2 PSRAM-scanout DMA read timings, then
the B2 SD card result (capacity, write/read-back PASS/FAIL, bandwidth —
or a clear "skipped" line if no card is inserted), once. Then the red
LED (next to BOOT/RESET) blinks at 1 Hz with a `phase0-metro alive: tick
N` heartbeat every 500 ms.

An SD card is optional for this firmware to run — if none is inserted
(or FatFs can't mount it), B2 just prints why and moves on to the
heartbeat loop like everything else did.

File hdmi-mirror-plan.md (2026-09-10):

# Plan: switch rp2350-hdmi-hexpansion to hazanjon's `attach_mirror` sink

## Goal

Two repos, two sets of changes, then a build+flash:

1. **`Corteil/rp2350-hdmi-hexpansion`** (this repo) — patch the RP2350 receive
   firmware and the badge-side app so they use hazanjon's push-based
   `display.attach_mirror()` sink instead of the current `display.get_fb()`
   polling loop.
2. **`hazanjon/badge-2024-software`**, branch **`feature/hdmi-mirror`**
   (upstream PR emfcamp/badge-2024-software#454 — NOT `main`, which only has
   an earlier, simpler version of the mirror sink) — build as-is, no patches
   needed there. Its `attach_mirror(port, driver, sck, mosi, cs, dc)` already
   accepts explicit pin overrides.

Do not attempt to patch hazanjon's C code — the plan below works entirely
by passing keyword overrides from Python.

---

## Part A — Patch `firmware/testcard/src/main.c`

**A1. SPI mode 0, not mode 3.**

hazanjon's mirror sink hardcodes `spi_device_interface_config_t.mode = 0`
(CPOL=0, CPHA=0) in `flow3r_bsp_display_mirror.c`, with no way to configure
it from Python. The current RP2350 firmware is built for mode 3.

Find:
```c
    spi_set_format(SPI_PORT, 8, SPI_CPOL_1, SPI_CPHA_1, SPI_MSB_FIRST);
```
Replace with:
```c
    spi_set_format(SPI_PORT, 8, SPI_CPOL_0, SPI_CPHA_0, SPI_MSB_FIRST);
```

**A2. Undo the byte-swap on this side instead of the badge side.**

`display.attach_mirror()` forwards the badge's raw `tildagon_fb` straight
from C (`flow3r_bsp_display_dispatch_sinks(tildagon_fb, ...)`), which is
`CTX_FORMAT_RGB565_BYTESWAPPED`. There is no per-frame Python callback left
to un-swap it (that's what the old `MirrorApp._swap_bytepairs()` used to
do) — so the swap has to happen when this firmware unpacks each pixel.

Find:
```c
            uint16_t *src16 = (uint16_t *)(void *)row_rx;
            uint32_t *dst32 = framebuf[recv_buf][row_index];
            for (int i = 0; i < DBL_WORDS; i++) {
                uint32_t px = src16[i];
                dst32[i] = px | (px << 16);
            }
```
Replace with:
```c
            uint32_t *dst32 = framebuf[recv_buf][row_index];
            for (int i = 0; i < DBL_WORDS; i++) {
                // hazanjon's attach_mirror sink forwards tildagon_fb raw
                // (CTX_FORMAT_RGB565_BYTESWAPPED) -- undo that here since
                // there's no Python-side _swap_bytepairs() step any more.
                uint32_t px = (row_rx[2 * i] << 8) | row_rx[2 * i + 1];
                dst32[i] = px | (px << 16);
            }
```

Leave everything else in `main.c` (DMA ring receive, `FRAME_MARKER`
handling, row-vs-frame framing) untouched — it's already
chunking-/CS-framing-agnostic and doesn't care that hazanjon's sink sends
in 4096-byte DMA bursts under one continuous CS-low frame.

---

## Part B — Patch `firmware/testcard/badge_app/app.py`

Replace the entire `MirrorApp` class (from `class MirrorApp(app.App):` down
to, but not including, the trailing `__app_export__ = MirrorApp` line) with:

```python
# Per-port GPIO overrides. hazanjon's PORT_PINS table
# (badge-2024-software feature/hdmi-mirror,
# components/flow3r_bsp/flow3r_bsp_display_mirror.c) labels these
# sck/mosi/cs/dc, but its physical role assignment doesn't match ours
# (this repo's README §4.1: HS_F=MOSI, HS_G=CS, HS_H=SCK). mosi already
# lines up; sck/cs are swapped relative to hazanjon's defaults. Re-check
# this table if that upstream file's PORT_PINS values ever change.
_PORT_OVERRIDE = {
    # port: (sck, mosi, cs)
    1: (41, 39, 40),
    2: (37, 35, 36),
    3: (47, 34, 33),
    4: (13, 11, 14),
    5: (15, 18, 16),
    6: ( 5,  3,  4),
}

class MirrorApp(app.App):
    def __init__(self, config):
        super().__init__()
        self.config = config
        self.buttons = Buttons(self)
        self.status = "starting..."

        port = getattr(config, "port", None) if config else None
        if port is not None:
            eventbus.emit(HexpansionAppLauncherAddEvent(port, "HDMI Mirror"))
            self._attach(port)

    def _attach(self, port):
        sck, mosi, cs = _PORT_OVERRIDE.get(port, (None, None, None))
        if sck is None:
            self.status = "no pin override for port %d" % port
            print(self.status)
            return
        driver = {
            "baudrate": 20_000_000,  # re-sweep once this is on real hardware
            "init": [], "prefix": [], "postfix": [],
            "header": FRAME_MARKER,  # bytes([0xA5, 0x5A] * 4) -- unchanged
        }
        try:
            display.attach_mirror(port=port, driver=driver, sck=sck, mosi=mosi, cs=cs)
            self.status = "mirroring (attach_mirror)"
        except Exception as e:
            self.status = "attach_mirror failed: {!r}".format(e)
            print(self.status)

    def deinit(self):
        port = getattr(self.config, "port", None) if self.config else None
        if port is not None:
            try:
                display.detach_mirror(port)
            except Exception as e:
                print("detach_mirror failed: {!r}".format(e))

    def update(self, delta):
        if self.buttons.pressed(BUTTON_TYPES["CANCEL"]):
            self.buttons.clear()
            self.minimise()
            return True

    def draw(self, ctx):
        ctx.save()
        clear_background(ctx)
        ctx.rgb(1, 1, 1).move_to(0, -30).text("HDMI Mirror")
        ctx.font_size = small_font_size
        ctx.rgb(1, 1, 0).move_to(0, 10).text(self.status)
        ctx.rgb(0.6, 0.6, 0.6).move_to(0, 45).text("CANCEL: back")
        ctx.restore()
```

Also **delete the now-unused `_swap_bytepairs` viper function** (the block
immediately above `class MirrorApp`, from its comment header down through
the `def _swap_bytepairs(...)` body) — nothing else in this file calls it
once `MirrorApp` no longer does its own SPI send loop.

Leave `TestcardApp` and everything above it untouched.

---

## Part C — Build hazanjon's badge firmware on the Pi 5

Docker + this base image are already proven working on this Pi 5 (built the
`get_fb()` version successfully over the weekend and the day after) — this
is the same process, different branch, no patching required.

```bash
git clone --recursive https://github.com/hazanjon/badge-2024-software.git
cd badge-2024-software
git checkout feature/hdmi-mirror
./scripts/firstTime.sh

docker run -it --rm --env "TARGET=esp32s3" \
  -v "$(pwd)":/firmware -u "$UID" -e HOME=/tmp \
  ghcr.io/emfcamp/esp_idf:v5.5.1
```

Flash to a real badge (put it in bootloader mode first: disconnect USB,
hold **BAT + BOOP** for 20s, reconnect):

```bash
docker run -it --rm --device /dev/ttyACM0:/dev/ttyUSB0 \
  --env "TARGET=esp32s3" -v "$(pwd)":/firmware -u "$UID" -e HOME=/tmp \
  ghcr.io/emfcamp/esp_idf:v5.5.1 deploy
```

---

## Part D — Verify before trusting it

1. **`HS_I`/`dc` pin contention** — hazanjon's firmware always drives a `dc`
   pin (falls back to the port's default, `HS_I`, if not overridden — there
   is no "disable" value). This repo's own convention wires `HS_I` as the
   RP2350's SPI0 MISO/TX line. Before connecting both boards live: either
   pass `dc=<some genuinely unused ESP32-S3 GPIO>` in `_attach()` above to
   redirect it away from `HS_I`, or confirm with a meter/scope that the
   RP2350's MISO line tri-states when not actively selected/clocked. Do not
   assume either side of this is safe without checking.
2. **Re-sweep SPI baudrate on real hardware.** The last speed data (20 MHz
   clean, 30 MHz+ bit errors) was measured against this repo's own
   Python-driven `machine.SPI` master (Phase 0 C3), not hazanjon's hardware
   SPI+DMA master. Confirm the same ceiling still holds before leaving
   `driver["baudrate"]` at 20 MHz.
3. Confirm the badge's "HDMI Mirror" launcher entry appears and mirrors
   correctly with the actual RP2350 hexpansion attached, not just that the
   firmware boots.

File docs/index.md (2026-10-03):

# Build an HDMI hexpansion for the Tildagon badge (Pico 2 + DVI Sock)

This guide builds a working HDMI output for the EMF Tildagon badge from two
cheap boards: a **Raspberry Pi Pico 2** and an **Adafruit DVI Sock**. The badge
mirrors its round screen to any HDMI monitor. If you don't want to compile
the firmware, there is a binary already compiled.

*Tested on 03/10/26 with the official Raspberry Pi monitor on badge port 4.*

## What you need

| Part | Notes |
|---|---|
| Raspberry Pi **Pico 2** | The plain Pico 2, **not** the Pico 2 W (its LED is on the wireless chip, so the status LED won't work). |
| [Adafruit DVI Sock for Pico](https://www.adafruit.com/product/5957) | Passive HDMI connector board, no active parts. |
| Port breakout hexpansion | The [port breakout hexpansion](https://github.com/emfcamp/badge-2024-hardware/tree/main/hexpansion) from the EMF badge hardware repo. It brings the port's pads out to pins you can wire to. |
| Reset push button | The Pico 2 has no reset button of its own, so add one between its `RUN` pin and GND. |
| HDMI cable and monitor | Some monitors need 5 V on the Sock's 5 V pad to show a picture, which needs a boost converter (see Troubleshooting). |
| 5 V boost converter (only if your monitor needs it) | Small 3.3 V to 5 V module. |
| Jumper wires | 8 wires, or 9 with the spare SPI pin: 3 SPI, 2 I2C, `LS_A` to `RUN`, VSYS power and GND (see below). |
| USB cable | Only for flashing. |
| Tildagon badge | Running badge firmware with display mirroring, see [Badge side](#badge-side). |

## 1. Attach the DVI Sock to the Pico 2

The Sock connects to **GP12 to GP19** on the Pico 2 and carries the HDMI
signals. Fit and solder it as Adafruit's product page describes, then check
that the connections match:

| Pico 2 pin | Sock signal |
|---|---|
| GP12 / GP13 | D0+ / D0− |
| GP14 / GP15 | CK+ / CK− |
| GP16 / GP17 | D2+ / D2− |
| GP18 / GP19 | D1+ / D1− |
| GND | GND |

The firmware is built for exactly this pin order, so don't swap the pairs.

## 2. Wire the Pico 2 to the badge port

Plug the port breakout hexpansion into the badge, and wire its pins to the
Pico 2 as below (the guide was tested on port 4):

| Badge signal | Pico 2 pin | Direction | Purpose |
|---|---|---|---|
| `HS_F` | GP0 | badge → Pico | SPI data (MOSI) |
| `HS_H` | GP1 | badge → Pico | SPI chip select (CS) |
| `HS_G` | GP2 | badge → Pico | SPI clock (SCK) |
| `HS_I` | GP3 | not used | spare |
| I2C SDA | GP4 | both | lets the badge identify the board |
| I2C SCL | GP5 | both | |
| `LS_A` | `RUN` | badge → Pico | lets the badge reset the Pico 2 |
| GND | GND | | **must be shared**: connect to any GND pin on the port breakout |
| 3V3 | VSYS (pin 39) | badge → Pico | power (see below) |

**Note the swap:** `HS_H` (the badge's chip select) goes to **GP1** and `HS_G`
(its clock) goes to **GP2**. The badge driver puts clock and chip select on
those two pins the opposite way round to what you might expect, and the
firmware needs them on GP1 and GP2 as shown.

The Pico 2 has no reset button, so also fit a **reset push button** between
its `RUN` pin and GND, so you can reset it by hand.

### Power

The Pico 2 runs fine from the badge's 3V3, wired to its **VSYS pin** (pin 39),
with no USB cable attached.
**Never connect USB and the badge's 3V3 together.** USB feeds the Pico's power
rail through a diode, so the badge's 3V3 would be pushed back into. Unplug USB
after flashing, before connecting the badge power.

## 3. Flash the firmware

1. Download [`pio_testcard_pico2.uf2`](https://github.com/Corteil/rp2350-hdmi-hexpansion/releases/latest/download/pio_testcard_pico2.uf2)
   from the latest release. Check it against the `.sha256` file on the same
   page (`sha256sum -c pio_testcard_pico2.uf2.sha256`).
2. Hold the **BOOTSEL** button on the Pico 2 and plug it into your computer
   by USB. Let go once a drive called **RP2350** appears.
3. Drag `pio_testcard_pico2.uf2` onto that drive. It reboots by itself when
   the copy finishes.
4. Unplug the USB cable.

The current release was built from commit `0a6ea73` and has the checksum
`381a32b4677d10293090b2ff0aa552e232379617f3af6e2996a23775f8e03e4d`.

## 4. First run

1. Connect the HDMI cable and power the Pico 2 from the badge's 3V3.
2. The monitor should show a test card, and the onboard LED should blink
   **once a second**. That means the board is running with no frames arriving.
3. When the badge starts sending its screen, the LED blinks **five times a
   second** and the monitor shows the badge screen.

### Badge side

The badge needs firmware with display mirroring and the `display_manager`
app (both by [hazanjon](https://github.com/hazanjon), see the
[README](https://github.com/Corteil/rp2350-hdmi-hexpansion#acknowledgements)).
On the badge:

1. Insert the board in the port (the Pico identifies itself as `HDMI-HEX`).
2. In `tildagon-hdmi-manager` (or `display_manager`), **detach** the mirror.
3. Press the **reset button** on the Pico 2.
4. **Attach** the mirror again, using the **HDMI** driver for that port.

The order matters: the reset goes between detach and attach.

## Troubleshooting

| Symptom | Likely cause |
|---|---|
| Monitor shows nothing at all | Some monitors only show a picture if the Sock's 5 V pad gets 5 V. The official Raspberry Pi monitor and a video capture dongle didn't need it. Because the Pico 2 runs from the badge's 3V3, there is no USB 5 V to use, so add a boost converter: input from the Pico 2's VSYS pin and GND, output 5 V to the 5 V pad on the Sock. Its GND must also be common with the port breakout's GND. |
| Test card shows, LED stays at 1 Hz after attaching | The badge frames aren't arriving. Check the SPI wires, above all `HS_F` to GP0, and that the mirror was attached with the **HDMI** driver. A broken data wire looks exactly like this: clock and chip select work but no frames decode. |
| Picture drops out, then returns, when you plug the badge in | Normal. The Pico 2 resets itself twice, about 2 s apart, when the port is inserted, then recovers. |
| Some frames missing | Normal. Around 18% of frames are dropped because the badge starts a new frame before the last finishes. It is not visible in practice. |

If a wire is suspect, the repo's `firmware/pin-probe` tool and the Pin Tester
badge app can show which Pico pin each badge pin actually reaches.

## Source and build

Everything, including how to build the firmware yourself, is in the
[repository README](https://github.com/Corteil/rp2350-hdmi-hexpansion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).

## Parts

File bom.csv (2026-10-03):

Item | Designator | Description | Value | MPN | LCSC | Footprint | Qty | JLC_Type | UnitUSD_10boards | ExtUSD | DNP | Notes
1 | C1,C2,C3,C4,C5,C6,C7,C10,C11,C12,C20,C32,C33 | Decoupling | 100nF | CL05B104KO5NNNC | C1525 | C0402 | 13 | Basic | 0.006 | 0.078
2 | C13,C14,C15 | Regulator caps | 4.7uF | CL05A475MP5NRNC | C23733 | C0402 | 3 | Basic | 0.0192 | 0.0576
3 | C16,C21,C23,C25 | Bulk / regulator caps | 10uF | CL10A106KP8NNNC | C19702 | C0603 | 4 | Basic | 0.0824 | 0.3296
4 | C17,C18 | Crystal load caps | 15pF | 0402CG150J500NT | C1548 | C0402 | 2 | Basic | 0.0022 | 0.0044
5 | J3 | SWD debug (RPi 3-pin) | SWD | BM03B-SRSS-TB(LF)(SN) | C160389 | CONN-SMD-3P-P1.00_BM03B-SRSS-TB-LF-SN | 1 | Extended | 0.2686 | 0.2686 |  | Vertical (top-entry) JST-SH
6 | L1 | RP2350 core regulator inductor | 3.3uH | AOTA-B201610S3R3-101-T | C42411119 | IND-SMD_L2.0-W1.6_AOTA-B201610S3R3-101-T | 1 | Extended | 0.2822 | 0.2822 |  | Part named in the RP2350 hardware design guide
7 | R1,R36,R37,R38,R39 | Resistor | 33R | 0402WGF330JTCE | C25105 | R0402 | 5 | Basic | 0.001 | 0.005
8 | R2,R6,R40,R51 | Resistor | 1k | 0402WGF1001TCE | C11702 | R0402 | 4 | Basic | 0.0011 | 0.0044
9 | R3,R4,R7,R41 | Resistor | 10k | 0402WGF1002TCE | C25744 | R0402 | 4 | Basic | 0.0029 | 0.0116
10 | SW1,SW2 | BOOTSEL + RESET buttons | BOOTSEL/RESET | TS-1088-AR02016 | C720477 | SW-SMD_L3.9-W3.0-P4.45 | 2 | Basic | 0.0557 | 0.1114
11 | U1 | Microcontroller, 2 MB flash in package | RP2354A | RP2354A | C41378174 | QFN-60_L7.0-W7.0-P0.40-TL-EP3.4 | 1 | Extended | 1.3097 | 1.3097 |  | Unit price from JLC list; you quoted GBP 1.00
12 | U9 | QSPI PSRAM 8 MB (hand-solder) | APS6404L-3SQR-SN | APS6404L-3SQR-SN | C5333729 | SOIC-8_L4.9-W3.9-P1.27-LS6.0-BL | 1 | Extended | 4.3423 |  | DNP | DNP. SOP-8 3.3 V part (the -ZR is USON-8). Buy separately for hand soldering
13 | U11 | Badge LS_A -> RUN open-drain buffer | SN74LVC1G07 | SN74LVC1G07DBVR | C7829 | SOT-23-5_L3.0-W1.7-P0.95-LS2.8-BR | 1 | Extended | 0.0915 | 0.0915 |  | Badge reset buffer, powered from the badge rail (no backfeed)
14 | Y1 | 12 MHz crystal | 12MHz | ABM8-272-T3 | C20625731 | CRYSTAL-SMD_4P-L3.2-W2.5-BL | 1 | Extended | 0.2938 | 0.2938 |  | Crystal named in the RP2350 hardware design guide
15 | C22,C24,C26 | Bulk caps | 22uF | CL21A226MAQNNNE | C45783 | C0805 | 3 | Basic | 0.1185 | 0.3555
16 | D1 | VBUS TVS | SMF5.0A | SMF5.0A | C19077497 | SOD-123FL_L2.7-W1.8-LS3.8-RD | 1 | Preferred | 0.0273 | 0.0273
17 | J2 | USB-C receptacle (sink) | USB-C | TYPE-C 16PIN 2MD(073) | C2765186 | USB-C-SMD_TYPE-C-16PIN-2MD-073 | 1 | Extended | 0.0742 | 0.0742 |  | Same part as the badge. Footprint drawn for 1.6 mm boards; check legs on 1.0 mm
18 | L2 | Buck inductor | 2.2uH | FTC252012S2R2MBCA | C5832372 | IND-SMD_L2.5-W2.0_MHCHL2520 | 1 | Extended | 0.0341 | 0.0341
19 | R8,R9 | Resistor | 5.1k | 0402WGF5101TCE | C25905 | R0402 | 2 | Basic | 0.0009 | 0.0018
20 | R10,R11 | Resistor | 27R | 0402WGF270JTCE | C25100 | R0402 | 2 | Extended | 0.001 | 0.002 |  | Low JLC stock (enough for small runs)
21 | R12,R16,R17,R18,R34,R35 | Resistor | 100k | 0402WGF1003TCE | C25741 | R0402 | 6 | Basic | 0.004 | 0.024
22 | R13,R15 | Resistor | 22k | 0402WGF2202TCE | C25768 | R0402 | 2 | Basic | 0.0013 | 0.0026
23 | U3 | Buck 5V -> 3V3 (2 A) | TLV62569DBVR | TLV62569DBVR | C141836 | SOT-23-5_L3.0-W1.7-P0.95-LS2.8-BR | 1 | Extended | 0.0733 | 0.0733
24 | U8 | USB ESD | USBLC6-2SC6 | USBLC6-2SC6 | C2687116 | SOT-23-6_L2.9-W1.6-P0.95-LS2.8-BL | 1 | Extended | 0.0476 | 0.0476
25 | R14 | Resistor | 33k | 0402WGF3302TCE | C25779 | R0402 | 1 | Basic | 0.0008 | 0.0008
26 | U2 | Power mux, USB priority, reverse blocking | TPS2116DRLR | TPS2116DRLR | C3235557 | SOT-583-8_L2.1-W1.6-P0.50-LS1.6-BL | 1 | Extended | 0.5491 | 0.5491
27 | F1 | HDMI +5V resettable fuse | 200mA PTC | JK-SMD0805-020-30V | C516070 | F0805 | 1 | Extended | 0.031 | 0.031 |  | KEEP POPULATED (group w/ L3,R19,R20,U4,TP2): some monitors need pin 18 5V present to assert HPD / light up - confirmed by testing on the Pico 2 + Adafruit DVI Sock rig. U4's EN pin is wired to BOOST_EN on a spare RP2350 GPIO, so firmware can switch it on/off per monitor rather than fitting/DNP'ing in hardware.
28 | L3 | Boost inductor | 1uH | FTC252010S1R0MBCA | C5832356 | IND-SMD_L2.5-W2.0_FTC252010S | 1 | Extended | 0.0396 | 0.0396 |  | Part of HDMI 5V boost group | see F1 note
29 | R19 | Resistor | 200k | 0402WGF2003TCE | C25764 | R0402 | 1 | Basic | 0.0009 | 0.0009 |  | Part of HDMI 5V boost group | see F1 note
30 | R20 | Resistor | 27k | 0402WGF2702TCE | C25771 | R0402 | 1 | Preferred | 0.0011 | 0.0011 |  | Part of HDMI 5V boost group | see F1 note
31 | U4 | Boost 3V3 -> 5V for HDMI pin 18 | TPS61023DRLR | TPS61023DRLR | C919459 | SOT-563_L1.6-W1.2-P0.50-LS1.6-BR | 1 | Extended | 0.268 | 0.268 |  | EN pin wired to BOOST_EN (spare RP2350 GPIO) - firmware-controlled, see F1 note
32 | J5 | HDMI Type A receptacle | HDMI-A | HDMI-001 19PCBTP | C138388 | HDMI-SMD_19P-P0.50-H-F | 1 | Extended | 0.2332 | 0.2332 |  | Full-size HDMI Type A. Check fit on the board edge
33 | U6,U7 | HDMI TMDS ESD (0.5 pF) | TPD4E05U06 | TPD4E05U06DQAR | C138714 | USON-10_L2.5-W1.0-P0.50-BL | 2 | Extended | 0.0819 | 0.1638 |  | OPTIONAL: Adafruit DVI Sock for Pico uses only bare 220R series resistors on the TMDS lines, no ESD IC. Recommend keeping these given the connector is exposed and used in the field (EMF Camp), but flagging as a simplification candidate if desired.
34 | C29 | EEPROM decoupling | 100nF | CL05B104KO5NNNC | C1525 | C0402 | 1 | Basic | 0.006 |  | DNP | DNP with U10
35 | J1 | Hexpansion edge connector (PCB edge) | Hexpansion-Connector |  |  | hexpansion-edge-connector | 1 |  |  |  |  | PCB edge fingers, no part
36 | U10 | Hexpansion ID EEPROM (fallback) | ZD24C64A (fallback) | ZD24C64A-SSGMT | C2896793 | SOP-8_L4.9-W3.9-P1.27-LS6.0-BL | 1 | Extended | 0.1419 |  | DNP | DNP. Fit only if EEPROM emulation fails
37 | H1,H2 | Mounting holes | MountingHole |  |  | MountingHole_2.2mm_M2_Pad_Via | 2 |  |  |  |  | Bare pads
38 | LED1,LED2 | Power + status LEDs | PWR/STATUS | KT-0603R | C2286 | LED-SMD_L1.6-W0.8-R-RD | 2 | Basic | 0.0073 | 0.0146
39 | LED3 | RGB status LED | SK6805 | SK6805MICRO-J | C2909056 | LED-SMD_4P-L2.7-W2.4_SK6805MICRO-J | 1 | Extended | 0.0899 | 0.0899
40 | R52 | Resistor | 330R | 0402WGF3300TCE | C25104 | R0402 | 1 | Basic | 0.0012 | 0.0012
41 | TP1 | Test pad | +3V3 |  |  | TestPoint_Pad_D1.0mm | 1 |  |  |  |  | Bare pads
42 | TP2 | Test pad | V5_HDMI |  |  | TestPoint_Pad_D1.0mm | 1 |  |  |  |  | Part of HDMI 5V boost group | see F1 note
43 | TP3 | Test pad | GND |  |  | TestPoint_Pad_D1.0mm | 1
44 | J4 | Qwiic | Qwiic | SM04B-SRSS-TB(LF)(SN) | C160404 | CONN-SMD_4P-P1.00_SM04B-SRSS-TB-LF-SN | 1 | Extended | 0.2262 | 0.2262
45 | JP1 | Qwiic pull-up solder jumper | Qwiic pull-ups |  |  | SolderJumper-2_P1.3mm_Bridged_RoundedPad1.0x1.5mm | 1 |  |  |  |  | Bare copper jumper, cut to remove Qwiic pull-ups
46 | R48,R49,R50 | Resistor | 4.7k | 0402WGF4701TCE | C25900 | R0402 | 3 | Basic | 0.0011 | 0.0033
 |  | Totals per board: fitted, JLC-assembled parts only |  |  |  |  | 80 |  |  | 5.11 |  | Unit prices at the 10-board quantity tier

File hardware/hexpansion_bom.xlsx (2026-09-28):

RP2350 HDMI Hexpansion - BOM tracker (1.0mm PCB, single-sided assembly)
Legend: yellow cells are yours to fill in. LCSC # format is C followed by digits (e.g. C12345 - placeholder format only). Check Basic/Extended and Stock in the JLCPCB parts library before committing to a footprint.
Section | Ref (KiCad) | Function | Suggested part / value | Package | Qty | Assemble? (Y/N) | LCSC # | Basic / Extended | Stock | Unit cost (USD) | Line total (USD) | Notes
Core | C1,C2,C3,C4,C5,C6,C7,C10,C11,C12,C20,C32,C33 | Decoupling | CL05B104KO5NNNC (100nF) | C0402 | 13 | Y | C1525 | Basic | 16407331 | $0.006
Core | C13,C14,C15 | Regulator caps | CL05A475MP5NRNC (4.7uF) | C0402 | 3 | Y | C23733 | Basic | 964426 | $0.019
Core | C16,C21,C23,C25 | Bulk / regulator caps | CL10A106KP8NNNC (10uF) | C0603 | 4 | Y | C19702 | Basic | 5302559 | $0.082
Core | C17,C18 | Crystal load caps | 0402CG150J500NT (15pF) | C0402 | 2 | Y | C1548 | Basic | 358497 | $0.002
Core | J3 | SWD debug (RPi 3-pin) | BM03B-SRSS-TB(LF)(SN) (SWD) | CONN-SMD-3P-P1.00_BM03B-SRSS-TB-LF-SN | 1 | Y | C160389 | Extended | 8526 | $0.269 |  | Vertical (top-entry) JST-SH
Core | L1 | RP2350 core regulator inductor | AOTA-B201610S3R3-101-T (3.3uH) | IND-SMD_L2.0-W1.6_AOTA-B201610S3R3-101-T | 1 | Y | C42411119 | Extended | 20758 | $0.282 |  | Part named in the RP2350 hardware design guide
Core | R1,R36,R37,R38,R39 | Resistor | 0402WGF330JTCE (33R) | R0402 | 5 | Y | C25105 | Basic | 968914 | $0.001
Core | R2,R6,R40,R51 | Resistor | 0402WGF1001TCE (1k) | R0402 | 4 | Y | C11702 | Basic | 2610919 | $0.001
Core | R3,R4,R7,R41 | Resistor | 0402WGF1002TCE (10k) | R0402 | 4 | Y | C25744 | Basic | 1256270 | $0.003
Core | SW1,SW2 | BOOTSEL + RESET buttons | TS-1088-AR02016 (BOOTSEL/RESET) | SW-SMD_L3.9-W3.0-P4.45 | 2 | Y | C720477 | Basic | 877449 | $0.056
Core | U1 | Microcontroller, 2 MB flash in package | RP2354A | QFN-60_L7.0-W7.0-P0.40-TL-EP3.4 | 1 | Y | C41378174 | Extended | 6193 | $1.310 |  | Unit price from JLC list; you quoted GBP 1.00
Core | U9 | QSPI PSRAM 8 MB (hand-solder) | APS6404L-3SQR-SN | SOIC-8_L4.9-W3.9-P1.27-LS6.0-BL | 1 | N | C5333729 | Extended | 41 | $4.342 |  | DNP. SOP-8 3.3 V part (the -ZR is USON-8). Buy separately for hand soldering
Core | U11 | Badge LS_A -> RUN open-drain buffer | SN74LVC1G07DBVR | SOT-23-5_L3.0-W1.7-P0.95-LS2.8-BR | 1 | Y | C7829 | Extended | 46270 | $0.091 |  | Badge reset buffer, powered from the badge rail (no backfeed)
Core | Y1 | 12 MHz crystal | ABM8-272-T3 (12MHz) | CRYSTAL-SMD_4P-L3.2-W2.5-BL | 1 | Y | C20625731 | Extended | 18110 | $0.294 |  | Crystal named in the RP2350 hardware design guide
USB-C input | C22,C24,C26 | Bulk caps | CL21A226MAQNNNE (22uF) | C0805 | 3 | Y | C45783 | Basic | 1734789 | $0.118
USB-C input | D1 | VBUS TVS | SMF5.0A | SOD-123FL_L2.7-W1.8-LS3.8-RD | 1 | Y | C19077497 | Preferred | 969692 | $0.027
USB-C input | J2 | USB-C receptacle (sink) | TYPE-C 16PIN 2MD(073) (USB-C) | USB-C-SMD_TYPE-C-16PIN-2MD-073 | 1 | Y | C2765186 | Extended | 1171811 | $0.074 |  | Same part as the badge. Footprint drawn for 1.6 mm boards; check legs on 1.0 mm
USB-C input | L2 | Buck inductor | FTC252012S2R2MBCA (2.2uH) | IND-SMD_L2.5-W2.0_MHCHL2520 | 1 | Y | C5832372 | Extended | 773097 | $0.034
USB-C input | R8,R9 | Resistor | 0402WGF5101TCE (5.1k) | R0402 | 2 | Y | C25905 | Basic | 2237664 | $0.001
USB-C input | R10,R11 | Resistor | 0402WGF270JTCE (27R) | R0402 | 2 | Y | C25100 | Extended | 1738 | $0.001 |  | Low JLC stock (enough for small runs)
USB-C input | R12,R16,R17,R18,R34,R35 | Resistor | 0402WGF1003TCE (100k) | R0402 | 6 | Y | C25741 | Basic | 1535859 | $0.004
USB-C input | R13,R15 | Resistor | 0402WGF2202TCE (22k) | R0402 | 2 | Y | C25768 | Basic | 667275 | $0.001
USB-C input | U3 | Buck 5V -> 3V3 (2 A) | TLV62569DBVR | SOT-23-5_L3.0-W1.7-P0.95-LS2.8-BR | 1 | Y | C141836 | Extended | 108275 | $0.073
USB-C input | U8 | USB ESD | USBLC6-2SC6 | SOT-23-6_L2.9-W1.6-P0.95-LS2.8-BL | 1 | Y | C2687116 | Extended | 150192 | $0.048
Power mux | R14 | Resistor | 0402WGF3302TCE (33k) | R0402 | 1 | Y | C25779 | Basic | 897525 | $0.001
Power mux | U2 | Power mux, USB priority, reverse blocking | TPS2116DRLR | SOT-583-8_L2.1-W1.6-P0.50-LS1.6-BL | 1 | Y | C3235557 | Extended | 12811 | $0.549
HDMI +5V boost | F1 | HDMI +5V resettable fuse | JK-SMD0805-020-30V (200mA PTC) | F0805 | 1 | Y | C516070 | Extended | 460152 | $0.031
HDMI +5V boost | L3 | Boost inductor | FTC252010S1R0MBCA (1uH) | IND-SMD_L2.5-W2.0_FTC252010S | 1 | Y | C5832356 | Extended | 259264 | $0.040
HDMI +5V boost | R19 | Resistor | 0402WGF2003TCE (200k) | R0402 | 1 | Y | C25764 | Basic | 268738 | $0.001
HDMI +5V boost | R20 | Resistor | 0402WGF2702TCE (27k) | R0402 | 1 | Y | C25771 | Preferred | 153614 | $0.001
HDMI +5V boost | U4 | Boost 3V3 -> 5V for HDMI pin 18 | TPS61023DRLR | SOT-563_L1.6-W1.2-P0.50-LS1.6-BR | 1 | Y | C919459 | Extended | 16691 | $0.268
HDMI Type A | J5 | HDMI Type A receptacle | HDMI-001 19PCBTP (HDMI-A) | HDMI-SMD_19P-P0.50-H-F | 1 | Y | C138388 | Extended | 50039 | $0.233 |  | Full-size HDMI Type A. Check fit on the board edge
HDMI Type A | U6,U7 | HDMI TMDS ESD (0.5 pF) | TPD4E05U06DQAR | USON-10_L2.5-W1.0-P0.50-BL | 2 | Y | C138714 | Extended | 94387 | $0.082
Hexpansion edge connector | C29 | EEPROM decoupling | CL05B104KO5NNNC (100nF) | C0402 | 1 | N | C1525 | Basic | 16407331 | $0.006 |  | DNP with U10
Hexpansion edge connector | J1 | Hexpansion edge connector (PCB edge) | Hexpansion-Connector | hexpansion-edge-connector | 1 | N |  |  |  |  |  | PCB edge fingers, no part
Hexpansion edge connector | U10 | Hexpansion ID EEPROM (fallback) | ZD24C64A-SSGMT (ZD24C64A (fallback)) | SOP-8_L4.9-W3.9-P1.27-LS6.0-BL | 1 | N | C2896793 | Extended | 6312 | $0.142 |  | DNP. Fit only if EEPROM emulation fails
LEDs, test pads, mounting | H1,H2 | Mounting holes | MountingHole | MountingHole_2.2mm_M2_Pad_Via | 2 | N |  |  |  |  |  | Bare pads
LEDs, test pads, mounting | LED1,LED2 | Power + status LEDs | KT-0603R (PWR/STATUS) | LED-SMD_L1.6-W0.8-R-RD | 2 | Y | C2286 | Basic | 8154450 | $0.007
LEDs, test pads, mounting | LED3 | RGB status LED | SK6805MICRO-J | LED-SMD_4P-L2.7-W2.4_SK6805MICRO-J | 1 | Y | C2909056 | Extended | 38882 | $0.090
LEDs, test pads, mounting | R52 | Resistor | 0402WGF3300TCE (330R) | R0402 | 1 | Y | C25104 | Basic | 732878 | $0.001
LEDs, test pads, mounting | TP1 | Test pad | +3V3 | TestPoint_Pad_D1.0mm | 1 | N |  |  |  |  |  | Bare pads
LEDs, test pads, mounting | TP2 | Test pad | V5_HDMI | TestPoint_Pad_D1.0mm | 1 | N
LEDs, test pads, mounting | TP3 | Test pad | GND | TestPoint_Pad_D1.0mm | 1 | N
Qwiic | J4 | Qwiic | SM04B-SRSS-TB(LF)(SN) (Qwiic) | CONN-SMD_4P-P1.00_SM04B-SRSS-TB-LF-SN | 1 | Y | C160404 | Extended | 7284 | $0.226
Qwiic | JP1 | Qwiic pull-up solder jumper | Qwiic pull-ups | SolderJumper-2_P1.3mm_Bridged_RoundedPad1.0x1.5mm | 1 | N |  |  |  |  |  | Bare copper jumper, cut to remove Qwiic pull-ups
Qwiic | R48,R49,R50 | Resistor | 0402WGF4701TCE (4.7k) | R0402 | 3 | Y | C25900 | Basic | 3285378 | $0.001
 |  |  |  |  |  |  |  |  |  | Assembled line items
 |  |  |  |  |  |  |  |  |  | Unique Extended parts (setup fee each)
 |  |  |  |  |  |  |  |  |  | Assembly setup fee (USD) | $8.00
 |  |  |  |  |  |  |  |  |  | Extended fee per part (USD) | $3.00
 |  |  |  |  |  |  |  |  |  | Extended parts fee (USD)
 |  |  |  |  |  |  |  |  |  | Parts cost per board (USD)
 |  |  |  |  |  |  |  |  |  | Boards in run | 5
 |  |  |  |  |  |  |  |  |  | Parts cost for run (USD)
 |  |  |  |  |  |  |  |  |  | Assumptions: setup fee and Extended fee are placeholders I entered (roughly typical JLCPCB figures, not verified) - update from the current JLCPCB pricing page. Board count is 5 as suggested; PCB fabrication and shipping/VAT are not included.

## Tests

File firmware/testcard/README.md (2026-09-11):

# Testcard — badge-generated mirror streaming

The first firmware to combine every Phase 0 piece into one image and prove them working
*together*, not just individually: badge inserts a hexpansion → discovers the emulated
identification EEPROM with this project's real assigned identity (**VID `0x1969`, PID
`0x4544`**) → mounts a real LittleFS filesystem living inside that EEPROM → auto-launches the
badge-side app packed into it → that app **builds a 240×240 frame in Python and streams it
continuously over the proven SPI0 link, one burst per row** → the RP2350 receives, buffers,
and displays it live over HDMI, "as if mirrored from the badge" (not a literal mirror of
this badge's own rendered `ctx` screen — that needed `display.get_fb()`, Phase 0 C2's patch;
**merged and proven working end-to-end as of 2026-09-08, see the bottom of this file**).

Every layer here was proven individually in Phase 0. This firmware was originally a
pattern-select demo (RP2350 held a handful of fixed test patterns, badge picked among them)
— rewritten 2026-08-31 so the badge generates and streams real, changing pixel content
instead, exercising the link the way the actual mirroring product will.

## Architecture

```
  badge (ESP32-S3)                          RP2350 (Metro bench board)
  ┌─────────────────────┐                   ┌──────────────────────────┐
  │ hexpansion insertion │  I2C0 (GPIO4/5)  │ eeprom_i2c.c              │
  │ -> detect EEPROM     │◄─────────────────►│  VID=0x1969 PID=0x4544   │
  │ -> mount LittleFS    │                   │  real fs_image.h inside │
  │ -> import app.py     │                   └──────────────────────────┘
  │ -> TestcardApp runs  │
  │                       │  SPI0 (GPIO20-23) ┌──────────────────────────┐
  │  builds one 480-byte │─────────────────►│ spi0_receive_row(): FIFO  │
  │  row (240 RGB565 px, │  mode 3, CS-      │  byte-stream, no CS-edge  │
  │  colours rotating),  │  framed bursts    │  detection (see "Bugs     │
  │  streams it 240x/    │                   │  found" below) — stages  │
  │  frame continuously  │                   │  into frame_staging[],   │
  └───────────────────────┘                   │  swaps into framebuf[]  │
                                               │  once per full frame    │
                                               └────────────┬─────────────┘
                                                            │
                                               HSTX (GPIO12-19, colour-
                                               correct per phase0-dvi-
                                               colorfix, Stage 2 pillar-
                                               boxed/circular-masked
                                               geometry) ──► monitor

  Metro NeoPixel (GPIO25): RED 1Hz heartbeat (wall-clock, alive even with
  nothing connected) — briefly GREEN whenever a full 240-row frame lands.
```

All three peripheral pin groups (I2C0 on GPIO4/5, SPI0 on GPIO20–23, HSTX on GPIO12–19) are
disjoint, so one physical Metro RP2350 runs the whole demo — same bench rig as A2/C3/C4
(badge devkit hexpansion wired to the Metro's headers) plus phase0-dvi-colorfix's HSTX port +
Adafruit adapter + monitor, all connected at once.

## Pieces

* **`src/eeprom_i2c.c`/`.h`** — I2C0 target EEPROM emulation, adapted from
  `firmware/phase0-a2-eeprom/` (I2C0-target mechanics already confirmed working on real
  hardware there). Real differences: the real VID/PID instead of placeholders, and a real,
  mountable LittleFS2 image copied into the filesystem region instead of leaving it empty.
* **`src/fs_image.h`** — **generated**, not hand-edited. A LittleFS2 filesystem image built
  from `badge_app/` by `tools/build_fs_image.py`, emitted as a C byte array. Re-run that
  script (and rebuild) after changing `badge_app/`.
* **`badge_app/app.py`** — the actual badge-side source. Not run from a loose checkout: it's
  packed *into* the LittleFS image above, so it ships and updates with the hexpansion
  firmware itself, matching the product's own design (main README §2, item 2: "the RP2350
  owns that image, so the driver updates itself with the hexpansion firmware — no separate
  EEPROM flashing step, ever").
* **`src/main.c`** — combines I2C0 target start (first thing in `main()`, per §5's
  race-condition mitigation), HSTX/DVI setup (colour-correct, from `phase0-dvi-colorfix/`,
  Stage 2's pillarboxed/circular-masked 240×240→480×480-in-640×480 geometry, matching the
  badge's own round 240×240 display rather than a generic test card), the SPI0 slave row
  receive loop, a NeoPixel heartbeat/link-activity indicator, and an RP2350-generated
  analog-TV-style static pattern shown at boot and whenever the link goes idle.

## The LittleFS block-count math (why this matters, why it isn't guessed)

The badge computes its own filesystem partition size independently — `block_size = 512`,
`block_count = (eeprom_total_size − fs_offset) / 512` — from
`badge-2024-software/modules/system/hexpansion/util.py`'s `get_hexpansion_block_devices()`
and `modules/eeprom_partition.py`'s `EEPROMPartition.ioctl(4)`, confirmed by reading that
code directly (a local clone from this project's earlier C2 work), not assumed. With this
project's header values (`fs_offset=64`, `eeprom_total_size=65536`): `(65536−64)/512 =
127.875`, which Python's integer division floors to **127 blocks = 65,024 bytes** — so the
image is built with exactly `block_count=127` to match precisely what the badge will
actually address, leaving the trailing 448 bytes as harmless, unreachable padding.

Also confirmed directly from `micropython/extmod/vfs.c`'s `mp_vfs_autodetect()` (the code
`vfs.mount()` calls when handed a raw block device): a LittleFS2 image is recognised by the
literal ASCII bytes `"littlefs"` at **byte offset 8** of block 0 (or block 1, as a fallback)
— checked against the actual generated image before trusting any of this on hardware.

## Protocol

**I2C0 / EEPROM**: unchanged from `firmware/phase0-a2-eeprom/`, header format per main
README §1.4. Real VID/PID here, not placeholders — `unique_id` (from the RP2350's own factory
chip ID) still keeps distinct boards from colliding even though the VID/PID is now shared.

**SPI0**: mode 3 (CPOL=1, CPHA=1), one CS-framed burst per row, 480 bytes/burst — 240 RGB565
pixels, little-endian per pixel (`badge_app/app.py`'s `_build_row()` packs low byte first,
matching `src/main.c`'s `uint16_t` cast). The badge sends 240 bursts back-to-back per frame,
continuously, for as long as the app runs — there is no command byte and no reply/ack; this
is a one-way stream, not a request/response protocol like the pattern-select demo this
firmware used to be. `spi0_receive_row()` on the RP2350 side reads it as one continuous byte
stream (see "Bugs found and fixed" below for why, and for the one gap that leaves).

**Known pre-existing quirk (Phase 0 C3):** the very first SPI transfer after the badge
constructs a fresh `machine.SPI` object is occasionally corrupted — a repeatable ESP32-S3
master-side peripheral-init artifact, not a link problem (see
`firmware/phase0-a2-spi/README.md`'s C3 section for the original finding). Not worked around
here, since hiding it would misrepresent how the link actually behaves; every transfer after
the first is reliable.

## Bugs found and fixed (2026-08-30/31, all confirmed on real hardware)

**1. `gpio_get()` doesn't reflect this pin's real level while it's configured
`GPIO_FUNC_SPI`.** The original receive loop tried to frame each row by polling
`gpio_get(PIN_CS)` for edges. On this board/SDK combination it read `0` on every single poll
— including multi-second idle stretches with nothing plugged in — so the "wait for CS low"
and "abort if CS goes high mid-burst" logic never actually did anything; the function was
really just "flush the FIFO, then drain up to 480 bytes," running unsynchronized against a
continuous stream. Result: ~5 successful rows out of ~6000 attempts, all by timing luck.
**Fix:** stopped relying on CS at the GPIO level entirely. The badge sends each row as one
unbroken 480-byte burst with no filler bytes between rows, so the RX FIFO is already
naturally row-aligned as long as the receive side never discards or fabricates a byte.
`spi0_receive_row()` now just drains the FIFO into a byte counter that **persists across
calls** (so a row arriving a few bytes at a time, between other main-loop work, still
accumulates correctly) and only resets once a full row completes. Went from ~5/6000 to
continuous, reliable reception.

**Remaining accepted gap from fix 1:** with no CS-level resync, an interrupted mid-row
transfer (e.g. the hexpansion physically removed mid-burst) leaves the byte counter partway
through a row with no way to tell; the next bytes received, from whatever comes next, are
mis-attributed to finishing that stale row — a persistent misalignment until the RP2350 is
reset. Acceptable for a bench demo where the link is a continuous stream once started; a
product firmware would want a frame-sync marker or per-row CRC to detect and recover from
this instead.

**2. Writing `framebuf` from the CPU while HSTX's DMA concurrently scans it out could
disrupt already-marginal per-line timing.** A full unconditional rewrite of the whole 230KB
buffer (the original boot-time "no signal" static fill, called from the idle path) held the
bus long enough to break the display outright — confirmed by direct A/B testing on real
hardware. **Fix:** `framebuf_row_write_is_safe()` checks the DMA's current scan position
(from the shared, now-`volatile` `v_scanline`) before writing any given row, and skips
writing only that one row if the scan position is about to reach it — every other row is
always safe regardless of what the CPU is doing. This let the idle static refresh speed up
from 8 rows/100ms to a full-buffer pass every idle tick, without reintroducing the bus
contention that made the slow throttle necessary in the first place.

**3. Single-buffered `framebuf` produced a visible top-down "sweep"** as each live row landed
mid-scanout. A real second framebuffer would fix this outright but doesn't fit — another
230,400 bytes against ~220KB of free SRAM (512KB total RAM region minus the existing
framebuf, the 64KB emulated-EEPROM RAM copy, and code/other statics). **Fix:**
`frame_staging[]` holds incoming rows at source resolution (240 px, not the pre-doubled 480)
— 115,200 bytes, half the cost — and `framebuf` only gets touched once a full frame has
landed in staging, as one row-safety-gated pass. The display now holds the previous complete
frame steady for the ~1s it takes the badge to stream the next one, then swaps cleanly,
instead of visibly filling in row by row.

## Frame rate: ~5fps, capped by the badge's own scheduler, not this link

Original per-row-burst/1MHz protocol managed ~0.77fps (one new frame roughly every 1.3s).
Moving to one CS-framed burst per frame (all 240 rows, 115,200 bytes) at 20MHz — both
choices matching Phase 0 C3's own proven, real-hardware-measured configuration
(`firmware/phase0-a2-spi/README.md`) — plus precomputing the 8 possible colour-rotated rows
once at startup instead of rebuilding one every frame, got this to **~5fps**, confirmed by
two independent measurements: the badge's own on-screen timing (`avg=203ms/frame`) and the
RP2350's own row-arrival serial timestamps, in close agreement.

**Investigated further (2026-08-31) for a 15fps target and found a hard architectural
ceiling, not a bug to fix here.** `badge-2024-software/modules/app.py`'s `run()` loop awaits
`mark_update_finished()` after every `update()`, which contains an **unconditional
`await asyncio.sleep(0.05)`** — a hardcoded 50ms-per-tick floor in the framework's own
foreground-app update cycle, not something a hexpansion app can bypass. Stacked with the real
SPI wire time (~47ms at 20MHz, already near that baudrate's theoretical minimum) and roughly
100ms of further overhead not yet isolated (asyncio scheduling, the render/draw cycle, other
background tasks sharing the same single-threaded cooperative event loop), 15fps is not
reachable through the framework's normal foreground update() loop as currently written,
independent of how fast the SPI transfer itself is made.

**Accepted as-is; revisit once a real PCB prototype exists**, not on this bench's devkit
connector + dupont-wire leg. Phase 0 C3 already found real bit errors at 30MHz+ on that exact
wiring, so pushing SPI baudrate further wasn't attempted here without first re-validating
reliability on better wiring — a real PCB (no dupont leg, direct short traces) is the most
promising remaining lever and the right place to re-run C3's speed sweep before assuming a
higher rate is safe.

## Multiple test screens

Beyond the rotating colour bars, `badge_app/app.py` now has 6 more selectable screens,
cycled with UP/DOWN (L/R still controls the bars' rotation direction): `checker`, `bunny`,
`spider7`, `spider8`, `bat`, `duck`.

* **`checker`** — 20×20px black/white squares, generated the same way the bars are (raw
  pixel math in Python), no font/ctx involved.
* **`bunny`/`spider7`/`spider8`/`bat`/`duck`** — five unusual codepoints (`U+41E9 U+71E9
  U+81E9 U+BA7A` and `U+21E9`) found in `EMFCampFont.h`'s own glyph-index comment that don't
  belong to any normal alphabet/symbol block — the font's license header credits bundled
  "Solder Party logo" and "Keebdeck icons" as custom additions, and most of these are the
  leftover oddities (`U+21E9`/duck is the one exception — see below). Rendered via an
  **off-screen `ctx.Context(buffer=..., format=ctx.RGB565, ...)` surface backed by a
  bytearray this app allocates and controls itself** — the same underlying
  `ctx_new_for_framebuffer()` the real display driver uses, just pointed at our own buffer
  instead of the badge's screen. This is what makes `ctx`'s real vector font rendering
  available to a hexpansion app *without* needing `display.get_fb()` (Phase 0 C2's still-
  unmerged patch) at all: rendering into a buffer we own and read back ourselves sidesteps
  that blocker entirely, for this one narrow case (rendering static content), even though it
  doesn't solve C2's original goal (reading back the badge's *own live* screen).

**Identified on real hardware, all confirmed 2026-08-31:**

* **`spider7`** (`U+71E9`) and **`spider8`** (`U+81E9`) both genuinely look spider-like (7-
  and 8-leg respectively) — two similar glyphs, not one glyph miscounted via an earlier
  centering bug (re-confirmed after fixing that bug).
* **`bat`** (`U+BA7A`) looks bat-like — not independently confirmed against any outside
  source the way spider/duck were, so this name is a best-guess label, not a certainty.
* **`bunny`** (`U+41E9`) is a genuine, intentionally multi-coloured Easter-egg — its own
  glyph data sets its own fill colours internally (e.g. an embedded `0xFF0000FF` = opaque
  red), overriding whatever colour this app sets beforehand.
* **`duck`** (`U+21E9`) — a separately-sourced claim that this codepoint is a repurposed
  "duck" icon looked implausible purely from the font source (it sits mid-sequence among
  ordinary directional arrows, not among the four genuine oddities above, with an x-advance
  matching its arrow neighbours), and a fetch of a badge docs page repeating the claim wasn't
  trusted either (the fetch tool summarizes through a model regardless of prompt — two
  fetches of the same page gave inconsistent detail). **Tested directly on real hardware
  instead: `U+21E9` genuinely renders as a rubber duck**, not a plain arrow. The positional
  inference was a reasonable hypothesis that turned out wrong — direct hardware testing
  settled it where source-reading and an unreliable web fetch both fell short. The EMF Camp
  logo's own codepoint is still unidentified.

Per-icon colours (requested 2026-08-31, `ICON_COLOURS` in `badge_app/app.py`): `spider7`
white-on-dark-red, `spider8` white-on-dark-green, `bat` pale-lavender-on-dark-purple, `duck`
yellow-on-blue. `bunny` is deliberately excluded — its foreground is set by its own glyph
data regardless of what this app requests.

**A real bug this surfaced**: the `'g'` byte at the start of the bunny glyph's definition was
initially misread here as "this glyph is empty" (its own font-tool-generated comment reads
`/* Nothing to see here */`, which reads as confirmation of that at a glance). It's actually
`CTX_SAVE` (a state push) — checked against `ctx.h`'s opcode table — and real path data
follows immediately after. Worth remembering: a font/asset generator's own comments can be
generic placeholders for a *class* of command, not a claim about the specific glyph.

Screen-switching itself made the known no-frame-sync gap (see fix 1's "Remaining accepted
gap" in "Bugs found and fixed", above) more visible than continuous single-content streaming
had — each switch is a content discontinuity, and confirmed on real hardware, the bars
screen can show transient tearing "mostly after switching" to it from another screen,
self-correcting shortly after. After the per-icon colours above were added, a second
confirming observation on real hardware: switching between differently-coloured icon screens
can briefly show colours mixed between the old and new screen. Same underlying,
already-deferred gap both times, not two separate bugs — the decision to fix it properly (a
real frame-sync marker in `spi0_receive_row()`) is deferred to the PCB-prototype stage
alongside the frame-rate work above.

## Build

RP2350 firmware:

```bash
export PICO_SDK_PATH="$HOME/.pico-sdk/sdk/2.3.0"
export PICO_TOOLCHAIN_PATH="$HOME/.pico-sdk/toolchain/14_2_Rel1"
export PATH="$HOME/.pico-sdk/toolchain/14_2_Rel1/bin:$HOME/.pico-sdk/cmake/v3.31.5/bin:$HOME/.pico-sdk/ninja/v1.12.1:$HOME/.pico-sdk/picotool/2.3.0/picotool:$PATH"

cmake -G Ninja -B build .
cmake --build build
```

Regenerating `src/fs_image.h` after changing `badge_app/` (needs `pip install
littlefs-python` once):

```bash
python tools/build_fs_image.py
```

## Flash

No USB CDC on this firmware, on purpose — I2C0 needs to be live within a few hundred
microseconds of power-good (§5's race-condition mitigation), and TinyUSB init competes with
that budget for no benefit here. Flash via BOOTSEL: hold BOOT, tap RESET (or plug in while
holding BOOT), then `picotool load build/bringup.uf2` (or copy the `.uf2` onto the `RPI-RP2`
drive by hand). `picotool load -f`'s "force reboot over a live USB connection" trick won't
work here or after any other stdio-less Phase 0 firmware — there's no USB serial connection
for it to grab.

## Results

**2026-08-30, first attempt:** I2C0/EEPROM/LittleFS discovery confirmed end to end against
the badge's own real mount code (`system.hexpansion.util`'s `detect_eeprom_addr`/
`read_hexpansion_header`/`get_hexpansion_block_devices`, the same functions the real
insertion-IRQ handler calls — not a simulation):

```
I2C scan: ['0x50']
HexpansionHeader[ manifest version: 2026, fs offset: 64, eeprom page size: 64,
  eeprom total size: 65536, vendor id: 0x1969, product id: 0x4544,
  unique id: 49111, friendly name: Hexi-GFX ]
VID/PID confirmed: 0x1969 / 0x4544
eeprom block count: 128
partition block count: 127
partition block size: 512
Mounted OK at /hexpansion_test_3
Contents: ['app.py']
app.py length: 5930
has __app_export__: True
```

Every number matches the design exactly — VID/PID, block count (127, precisely the floored
math above), the packed `app.py` mounts and reads back byte-for-byte correct. (That first
attempt's SPI0 half used the original fixed-pattern-select protocol, since replaced — see
above.)

**2026-08-31, after the badge-generated-streaming rewrite and the three bugs above:**
confirmed on real hardware, badge inserted and app running normally (not a bench script):

* A `bringup_debug` (USB CDC + instrumentation) capture showed **16,560+ successfully
  received rows over a 90-second window** of continuous streaming — up from ~5 out of ~6000
  attempts before fix 1 — with the sampled row content cycling through the same repeating
  colour sequence every 240 rows, confirming full frames were completing, not just
  individual bytes landing.
* On the real `bringup` (no-USB) target: monitor shows the badge's colour bars, confirmed
  **rotating colour** (not scrolling position) in real time.
* NeoPixel confirmed **red 1Hz** with nothing streaming, and **green flashing** once per
  completed 240-row frame while the badge app runs — both observed directly by eye.
* Idle/no-signal static confirmed visibly faster/more chaotic after fix 2 ("static is much
  better").
* The top-down sweep during live updates confirmed **gone** after fix 3 ("sweep is gone,
  clean update now") — frames now appear to swap in one clean update instead of filling in
  row by row.

**The link works, and now carries badge-generated content.** Badge discovery → real
filesystem → real app → badge-built frame data streamed continuously over SPI0 → clean,
tear-free, colour-rotating HDMI output — all confirmed on real hardware, in one firmware
image.

**2026-09-07, real double-buffered framebuf:** the tearing described just above ("top-down
sweep during live updates") turned out not to be fully gone -- still visible as a one-time
shear on every landed frame once badge_app streamed real, continuously-changing content
over an extended session. Root cause: `framebuf` was never actually double-buffered (see
this firmware's own earlier comment on that), only per-row write-gated, which stops
corruption but not a frame showing a mix of old/new rows during the ~240-row copy.
Fixed by shrinking `HEX_EEPROM_SIZE` 64 KiB -> 8 KiB (freeing ~57 KiB of SRAM) and giving
`framebuf` a real second copy, swapped by `dma_irq_handler` only at the start of vblank.
`badge_app/` is no longer packed into the emulated EEPROM's LittleFS (now built empty) --
side-loaded onto the badge directly instead:

```
mpremote fs mkdir :/sideload_test
mpremote fs cp badge_app/app.py :/sideload_test/app.py
mpremote reset   # clean module state -- see below
mpremote resume exec "
import sideload_test.app as sideload_app
from system.hexpansion.config import HexpansionConfig
from system.scheduler.events import RequestStartAppEvent
from system.eventbus import eventbus
from system.scheduler import scheduler
config = HexpansionConfig(2)  # whichever port the hexpansion is in
a = sideload_app.__app_export__(config=config)
eventbus.emit(RequestStartAppEvent(a))
scheduler.run_forever()
"
```

Two real gotchas hit while working this out, worth recording:
* A plain `import app` after `sys.path.insert(0, '/sideload_test')` shadows the framework's
  own fundamental `app.py` (the base `App` class nearly everything imports) with the
  side-loaded file of the same name, breaking unrelated modules elsewhere with confusing
  `ImportError`s. Use a qualified import (`import sideload_test.app`) instead, matching how
  the real launcher does it (`__import__(f"{mount}.app")`) -- never touches the bare `app`
  name.
* `mpremote exec`/`resume exec`'s Ctrl-C doesn't just pause `main.py`'s top-level
  `scheduler.run_forever()`, it unwinds out of it entirely (a real `KeyboardInterrupt`
  through that call). Registering an app with `RequestStartAppEvent` alone does nothing
  further until something calls `scheduler.run_forever()` again -- do that as the last line
  of the exec'd script (run in the background; it never returns) rather than expecting the
  badge to keep ticking on its own afterward.

Confirmed on real hardware, side-loaded via the above: bars streaming continuously, monitor
showing **clean, tear-free** frame swaps -- no visible shear at all, unlike the same test
before this fix.
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

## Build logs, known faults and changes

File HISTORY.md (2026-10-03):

# RP2350 HDMI Hexpansion — Design History

> **This is the project's design journal, not the current-status doc.** It's the
> full chronological record of the design rationale, bench measurements, bugs
> found/fixed, and the phase-by-phase delivery plan that got the project from a
> blank page to working hardware. For what the project actually is and does
> *today*, see [`README.md`](README.md) — come back here for the "why" behind
> any given decision, or for BOM/costing/risk-register detail the README
> doesn't repeat.

Working name: **Hexi-GFX**. A Tildagon hexpansion that turns the EMF badge into a
machine with a real display output: an RP2350 driving DVI/HDMI over HSTX, with its
own flash and PSRAM, presenting itself to the badge as a normal hexpansion by
emulating the identification EEPROM in firmware.

Status when most of this document was written: **design plan / pre-schematic**,
every figure marked *(est.)* a modelled estimate, not a quote. Much of it is now
built and working on bench hardware — see the README for current status. Left
otherwise unedited as the historical record.

---

## 1. What the badge actually gives us

All of this is taken from the official hardware sources
(`emfcamp/badge-2024-hardware`) rather than from memory, because the whole design
hangs off it.

### 1.1 Hexpansion edge connector (20 pads, SFP-style)

Pads 1–10 are on the bottom copper, 11–20 on the top copper.

| Pad | Signal | Pad | Signal |
|----:|---|----:|---|
| 1 | GND | 11 | GND |
| 2 | LS_A | 12 | HS_F |
| 3 | LS_B | 13 | HS_G |
| 4 | SDA | 14 | GND |
| 5 | SCL | 15 | +3V3 |
| 6 | HEXP_DET | 16 | +3V3 |
| 7 | LS_C | 17 | GND |
| 8 | LS_D | 18 | HS_H |
| 9 | LS_E | 19 | HS_I |
| 10 | GND | 20 | GND |

Source: `hexpansion/hexpansion.kicad_sch` (`emfcamp/badge-2024-hardware`), the
`hexpansion-edge-connector_1_1` symbol's own pin definitions — re-verified
30/08/26 directly against that file after the table previously here had pads
4–10 shifted by 3 positions from the real schematic (an error introduced at
some earlier point in this document, not caught until cross-checked against
source while preparing to physically wire a protoboard hexpansion). If wiring
anything to this connector, trust this table and the cited source file over
any other copy of this pinout that may exist in older notes.

### 1.2 What each signal is worth to us

* **+3V3 only — there is no 5 V rail on the connector.** Each port is fed through
  an MT9700 current-limited load switch with an 11k3 set resistor, i.e. **~600 mA**.
  The badge enables the port in software, so we are dead until the badge decides
  to power us. Anything needing 5 V (the HDMI +5 V pin) has to be boosted on-board.
* **HS_F..HS_I go straight to dedicated ESP32-S3 GPIOs.** No mux, no expander.
  From the badge firmware's port table:

  | Port | hs_1 | hs_2 | hs_3 | hs_4 |
  |------|-----:|-----:|-----:|-----:|
  | 1 (A) | 39 | 40 | 41 | 42 |
  | 2 (B) | 35 | 36 | 37 | 38 |
  | 3 (C) | 34 | 33 | 47 | 48 |
  | 4 (D) | 11 | 14 | 13 | 12 |
  | 5 (E) | 18 | 16 | 15 | 17 |
  | 6 (F) | 3 | 4 | 5 | 6 |

  `hs_1..hs_4` correspond to `HS_F..HS_I` on the connector. These are matrix-routed
  (not IOMUX) on the ESP32-S3, so a hardware SPI master on them tops out around
  **40 MHz** — call it **2.5–5 MB/s** in practice. This is the single most important
  number in the whole design (see §3).
* **LS_A..LS_E hang off AW9523B I/O expanders** behind the I2C bus. They are slow —
  hundreds of microseconds per toggle. Useless for data, perfect for reset and
  attention lines.
* **SDA/SCL are per-port**, isolated behind a TCA9548A mux on the badge, with the
  badge providing the 2k2 pull-ups. So we get a private I2C bus and can own
  address 0x50 without colliding with anything else.
* **HEXP_DET** has a weak pull-up on the badge; we tie it to GND. That is what makes
  the badge power the port at all.

### 1.3 Mechanical — the hexagon, and how much of it we get

**The hexpansion is a regular hexagon, 32 mm across flats, with the insertion tab on one
flat.** From `hexpansion.kicad_pcb`: vertices at (0, 9.66), (16, 0), (32, 9.66),
(32, 26.98), (16, 36.64), (0, 26.98), tab tip at x = 0 spanning y = 12.07–24.57.

That means **each flat is only ~18.5 mm long** (side = W/√3 for a hexagon of width W).
This is the number that governs the whole physical design, and it is much smaller than
the 32 mm bounding-box width suggests.

* **Board thickness 1.0 mm** (template stackup is 0.91 mm core + 2×35 µm Cu ≈ 0.98 mm).
  Not negotiable — the badge's SFP-style receptacle expects a 1.0 mm card edge.
* **ENIG only. HASL is explicitly forbidden** — the pads must be flat to make contact.
* Two M2 mounting-hole pads, which is what will take the strain of a hanging cable.

#### How big can a hexpansion be?

From `tildagon-base.kicad_pcb`, the six SFP connectors sit at **radius 26.075 mm** from
the badge centre, 60° apart. For a hexpansion of width `W` across flats, the tile centre
is at `R = 26.075 + W/2`, and two adjacent tile centres are `D = 2·R·sin(30°) = R` apart.
Two hexagons of width `W` touch when `D = W`, so:

> **gap between neighbouring hexpansions = 26.075 − W/2 mm**

| W across flats | Flat length | Area | Gap to neighbours |
|---:|---:|-----:|---:|
| 32 (template) | 18.5 mm | 8.9 cm² | 10.1 mm |
| 40 | 23.1 mm | 13.9 cm² | 6.1 mm |
| **44 (chosen)** | **25.4 mm** | **16.8 cm²** | **4.1 mm** |
| 48 | 27.7 mm | 20.0 cm² | 2.1 mm |
| 52.2 | 30.1 mm | 23.6 cm² | 0 — touching |

This assumes the tab tip sits at the connector footprint origin. Insertion depth puts the
tab-side flat a millimetre or two further out, which makes `R` larger and the real gaps
slightly **bigger** than the table says — so these figures are conservative.

Five of the six flats are free. The two flanking the tab are effectively unusable (they
face the badge), leaving **the outer flat and the two adjoining it** — see §4.4.

### 1.4 The EEPROM contract

The badge scans the port's I2C bus and decides addressing mode by what answers:

* `0x50`–`0x57` all answer → 1-byte addressing (24C16-style, ≤ 2 KiB)
* only `0x50` answers → **2-byte addressing**, up to 64 KiB
* only `0x57` answers → 2-byte addressing

It then reads 32 bytes from offset 0 and parses a header packed as
`<4s4sHHIHHH9s` + 1 checksum byte:

| Offset | Size | Field |
|---:|-----:|---|
| 0 | 4 | magic, ASCII `THEX` |
| 4 | 4 | manifest version, ASCII `2024` or `2026` |
| 8 | 2 | `fs_offset` |
| 10 | 2 | `eeprom_page_size` |
| 12 | 4 | `eeprom_total_size` |
| 16 | 2 | `vid` |
| 18 | 2 | `pid` |
| 20 | 2 | `unique_id` |
| 22 | 9 | `friendly_name`, NUL-padded ASCII |
| 31 | 1 | checksum: seed `0x55`, XOR of bytes 1–30 |

If the header validates, the badge mounts a **LittleFS** starting at `fs_offset` and
runs the app it finds there. Block size is 512 bytes for EEPROMs ≥ 8 KiB.

VID/PID have to be requested from the badge team ("UHB-IF") — **do this early**, it is
the one item with an external dependency and zero cost.

**Assigned (30/08/26): VID `0x1969`, PID `0x4544`.** In use since — see `firmware/testcard/`
for the first firmware built around the real identity, confirmed enumerating correctly on
real hardware.

---

### 1.5 The badge's graphics stack

Checked against the firmware rather than the documentation, because what the headers
advertise and what this build implements are two different things.

**The badge uses exactly one graphics library: `ctx`**, by Øyvind Kolås — an immediate-mode
2D vector library with an HTML5-canvas-shaped API. Single header, 83,760 lines,
LGPL-3.0-or-later, vendored at commit `26287002`. Apps reach it through **uctx**, the
MicroPython binding in `drivers/gc9a01/mp_uctx.c` (1,196 lines), which is what
`display.get_ctx()` returns.

From `components/ctx/ctx_config.h`:

| Setting | Value |
|---|---|
| Pixel formats | **RGB565 and RGB565_BYTESWAPPED**, plus RGBA8, RGB332, RGB8, GRAY1/2/4/8, GRAYA8, YUV420 |
| Antialiasing | `CTX_RASTERIZER_AA 5`, dithering on, `CTX_STROKE_1PX` |
| Fonts | **One** — `EMFCampFont`. Three slots exist; a comment notes the partition is full |
| Images | stb_image, **PNG/GIF/JPEG only**; `CTX_MAX_TEXTURES 32` |
| Build | baremetal, `-Oz`, one font engine, no threads, no tiling |

#### `st3m` is a shim, and its header is misleading

`components/st3m/` is inherited from the flow3r badge. `st3m_gfx.h` advertises a rich
pipeline — `st3m_gfx_2x`/`3x`/`4x` pixel-doubling, an OSD overlay layer, 1/2/4/8-bit
palette modes, `st3m_gfx_smart_redraw`, `st3m_gfx_fbconfig` for virtual viewports, and a
`st3m_gfx_fb()` framebuffer accessor.

**Almost none of it is implemented here.** `st3m_gfx.c` is 283 lines defining five
functions: `init`, `fps`, `fps_update`, `splash`, `show_textview`. The Tildagon port
replaced the pipeline with the simple `tildagon_fb` + direct blit in
`drivers/gc9a01/display.c` (§3.1). Read that header as flow3r's ambitions, not this
badge's capabilities.

Two consequences:

* **No shortcut for the `get_fb()` patch.** `st3m_gfx_fb()` is a declaration with no body,
  so the upstream change still has to expose the `tildagon_fb` static. Scope unchanged.
* **§3.1's dirty-region claim is verified, not assumed.** `st3m_gfx_smart_redraw` exists
  only as an enum value; nothing implements it. The badge genuinely does not track what
  changed, and ctx redraws the whole frame.

## 2. Product definition

**Primary mode: the badge's own screen, on a monitor.** The hexpansion mirrors the
240×240 round display, pixel-doubled to 480×480 and circular-masked to match what people
actually see on the badge. **Every existing Tildagon app gets HDMI output with no code
changes** — no API to learn, no per-app work. That property is the product.

Everything else supports it:

1. **DVI/HDMI** from the RP2350's HSTX peripheral, on a **mini-HDMI (Type C)** receptacle.
2. **Emulates the identification EEPROM** at `0x50` in RP2350 firmware, serving a 64 KiB
   LittleFS image that contains the badge-side MicroPython driver app. The RP2350 owns
   that image, so the driver updates itself with the hexpansion firmware — no separate
   EEPROM flashing step, ever.
3. A **SPI link on the four HS pins** carrying framebuffer updates, or drawing commands.
4. **16 MB QSPI flash**, **8 MB QSPI PSRAM** and a **microSD socket** for the advanced
   mode's assets. The mirroring path needs none of it (§3.1).
5. **Display-list mode** for apps that want more than 240×240 — the RP2350 holds the
   assets and renders (§3.2).
6. **USB-C power** so it does not flatten the badge battery — powering this board only,
   never the badge, under any condition (§4.5) — plus UF2, a USB CDC console, and a
   **3-pin SWD connector** for a Raspberry Pi Debug Probe.
7. **Two Qwiic / STEMMA QT sockets**, which the badge can reach through the card as an
   I2C bridge.
8. A **44 mm across-flats hexagon** rather than the 32 mm template — the smallest size at
   which the connectors fit (§4.4).

The badge stays the computer. This is a display, and secondarily a graphics card.

## 3. Two modes, and the bandwidth that shapes them

### 3.1 Primary — mirroring the badge screen

The data path already exists in the badge firmware. From
`badge-2024-software/drivers/gc9a01/display.c`:

```c
EXT_RAM_BSS_ATTR
static uint8_t tildagon_fb[240 * 240 * 2];          // :34
...
tildagon_ctx = ctx_new_for_framebuffer(tildagon_fb, 240, 240, 480,
                                       CTX_FORMAT_RGB565_BYTESWAPPED);   // :41
...
void tildagon_blit_fb(void) { flow3r_bsp_display_send_fb(tildagon_fb, 16); }  // :64
```

One static **115,200-byte framebuffer**, RGB565 **byteswapped**, living in the ESP32's
PSRAM. ctx renders into it; `tildagon_end_frame()` blits it to the panel. **Every app
funnels through `display.end_frame(ctx)`** — a single choke point, always populated, in a
fixed format. Nothing better could be asked for.

The byteswap costs us nothing: the RP2350 can swap during DMA or in the HSTX command
stream.

#### The one blocker

**The framebuffer is not exposed to MicroPython.** The `display` module publishes
`gfx_init`, `bsp_init`, `splash`, `get_fps`, `get_ctx`, `end_frame` and `hexagon` — and no
framebuffer accessor. A hexpansion app cannot read those bytes today.

This needs a small upstream change to `badge-2024-software`: a `display.get_fb()` returning
a `memoryview` of `tildagon_fb`, which is on the order of ten lines of C. **Raise it in
week 1 alongside the VID/PID request** — it is short work, but it is on someone else's
schedule, and mirroring does not exist without it. See risk 4.

#### Link arithmetic

| | Bytes/frame | @5 MB/s | @2.5 MB/s |
|---|---:|---:|---:|
| Full 240×240 frame, RGB565 | 115,200 | **43 fps** | **22 fps** |
| Half the screen changed | 57,600 | 87 fps | 43 fps |
| Typical static UI, ~10% dirty | 11,520 | 434 fps | 217 fps |

**The link is not the ceiling — measured.** Mirroring cannot show more frames than the
badge draws, and a ctx-rendered MicroPython app on an ESP32-S3 is unlikely to be doing
forty. **Phase 0 C1: `display.get_fps()` sampled across three real installed apps on a
real badge**, watched passively over USB serial rather than guessed:

| App | fps range | What it's doing |
|-----|---|---|
| GPS clock (Corteil) | ~9.1–13.0 | varies by face — analog/setup/tide/sun/digital |
| Sponsor logos (emfcamp) | ~10.2–14.3 | image slideshow with crossfade transitions |
| EMF badge map (futureshape) | ~2.2–4.8 | PNG tile decode + network fetch — the heaviest of the three |

**Every app measured came in under the ~15 fps threshold** this section originally used as
the dividing line for "the link has enormous headroom and the mirror design gets
simpler" — nowhere near the ~40 fps threshold where dirty-rect tracking would need to
move into v1. Confirms the prediction: **the badge's own render rate is the bottleneck,
not the link**, comfortably. Even the worst case here (map app, ~2.5 fps, 115,200
bytes/frame) needs under 300 KB/s — a small fraction of what §1.2 says the HS pins can
carry (2.5–5 MB/s).

Dirty-rectangle updates still help, but note the badge does not track dirty regions — ctx
redraws the whole frame. Finding them means a block-`memcmp` against a second copy of the
buffer, which is cheap in MicroPython (comparing `memoryview` slices drops into C) but
needs another 115 KB on the badge. **Confirmed not worth having in v1** — C1's numbers
close the door on this being needed for the primary mode; revisit only if a much
heavier-drawing app turns up later.

**Getting this measurement required working around a real gotcha**: any `mpremote`
serial command (even with `resume`) sends an unconditional Ctrl-C before running
anything, which kills whatever app is in the foreground — `resume` only skips the
*following* soft-reset, not the interrupt itself. Interactively querying
`display.get_fps()` this way freezes the badge until it's manually reset. The
non-invasive method that worked: temporarily patch a periodic `print("C1_FPS", ...)`
into each app's own `draw()` (removed afterward), launch the app normally from the
badge's own UI, then watch passively with `mpremote connect COMx repl` — a pure
terminal pass-through that never sends the interrupt.

#### Scaling

**The output is always a standard 640×480 @60 Hz signal** — CEA-861 VIC 1, 25.2 MHz pixel
clock, 800×525 total, which every HDMI sink is required to accept. The doubling happens in
how the framebuffer is filled, not in the signal:

| | |
|---|---|
| Source | 240×240 RGB565 |
| Scale | ×2 nearest-neighbour → **480×480** |
| Vertical | 480 into 480 — **exact fit**, no letterbox |
| Horizontal | 640 − 480 = 160 → **80 px pillarbox bars** either side |
| Mask | circular, applied inside the 480×480 square |

**2× is the only integer scale available, and that is a hard limit** — see §3.3. No in-spec
HSTX mode is 720 pixels tall, so there is no 3× option to reach for.

#### Two consequences that de-risk the design

* **Memory leaves the critical path.** Source 115 KB, double-buffered 230 KB — comfortably
  inside the RP2350's 520 KB of SRAM. **The mirroring mode never touches PSRAM**, so the
  one video mode rated "needs measurement" (§3.3) no longer gates the primary product.
* **The badge-side driver becomes trivial** — read the buffer, push it, repeat. The
  display-list API becomes an opt-in extra rather than something every app author must
  learn.

#### The round display

The panel is circular, so the corners of that square buffer hold whatever ctx drew but are
never visible on the badge. On HDMI they would be. **The circular mask is on by default**,
so the monitor shows what the wearer sees; a runtime toggle reveals the full square for
debugging.

### 3.2 Advanced — forwarding ctx drawlists

For apps that want more than 240×240, the naive approach is unaffordable: 40 MHz SPI is
~5 MB/s at best, a 640×480 16 bpp frame is 614 KB, so pushing full frames gives **8 fps**
before any MicroPython overhead. At full resolution the badge has to send *what to draw*,
not pixels.

**The badge already produces exactly that, in a portable format.** ctx is a display-list
library — it records a drawlist and rasterises it — and both directions of its
serialisation are compiled in: `CTX_FORMATTER` and `CTX_PARSER` default to 1 and are not
overridden in `ctx_config.h`. **`ctx.parse()` is already exposed to MicroPython**
(`mp_uctx.c:950`).

So the preferred shape for this mode is **forwarding ctx's own drawlists** and running the
same rasteriser on the RP2350, rather than inventing a bespoke command set. What that buys:

* **Resolution independence.** The RP2350 rasterises at native 640×480 instead of doubling
  240×240 pixels — vector output, properly sharp, not scaled.
* **Unmodified apps benefit**, exactly as with mirroring. No API for app authors to learn,
  which is the same property that makes the primary mode worth building.
* **Compact on the wire.** A drawlist is a few hundred bytes to a few KB per frame against
  614 KB of pixels.
* **No protocol to design, document or version.** ctx already did it.

What it needs before it can be committed to:

| Requirement | Status |
|---|---|
| A firmware hook to capture the drawlist | A **second** upstream ask, beyond `display.get_fb()` |
| ctx built for RP2350 | Portable single-header C, but 84k lines — a real dependency |
| **Rasterisation performance at 640×480 on an RP2350** | **Measured, negative for animation.** See below. |
| LGPL-3.0-or-later review | Fine for firmware, but a deliberate decision rather than an assumption |

None of that gates v1 — mirroring does not depend on any of it.

**Measured on the Metro RP2350 bench (Phase 0 B1, see
`firmware/phase0-metro/`):** a hand-built "typical app screen" scene
(cards, icons, a header gradient) rasterises at **343 ms/frame (2.9
fps)**; a deliberately shape-heavy "worst case" scene (~160 overlapping
translucent shapes plus a full-screen radial gradient) at **1426 ms/frame
(0.7 fps)**. Both into a 640×480 RGB565_BYTESWAPPED framebuffer in PSRAM,
`CTX_RASTERIZER_AA` matched to the badge's own config (5, not ctx's
default of 15 — dropping AA only bought ~7%, so AA isn't what's slow
here).

Decomposed to find out what *is* slow: a raw sequential scalar write of
614 KB straight to the PSRAM framebuffer (no ctx involved) takes **70.6
ms** on its own — already a ~14 fps ceiling for *any* full-frame update
into PSRAM by CPU store instructions, before ctx does anything. ctx's
cheapest possible draw call (one opaque full-canvas rect, no gradient)
takes **169 ms** — about 2.4× the raw-write floor, i.e. roughly 40% of
even the *cheapest* frame's cost is PSRAM write bandwidth itself, not
ctx's rasteriser. The gradient- and shape-heavy scenes scale up from
there (typical ≈ 2× the solid-fill cost, worst case ≈ 8.4×).

**What this means:** full-frame ctx drawlist forwarding is not viable for
anything that redraws continuously or animates — 2.9 fps best case is
well below usable. It may still be viable for **occasional full redraws
of largely-static screens** (e.g. a settings menu redrawn once on
navigation, tolerating a few hundred ms of latency), which is a real and
still-useful mode, just not "every app gets a live 640×480 canvas for
free" the way mirroring is. This wasn't tested with DMA-driven writes,
but that wouldn't help ctx specifically — ctx's rasteriser fills spans
with ordinary C stores, not DMA, regardless of where the target buffer
lives; DMA only helps the *scanout* (HSTX) side, which is unrelated to
this cost. Treat "drawlist forwarding for static/occasional content, not
animation" as the finding rather than "drawlist forwarding" unqualified.

#### The command set that remains either way

Drawlists cover drawing. They do not cover mirror control, bulk asset transfer, audio, the
I2C bridge or housekeeping, so a thin command layer sits alongside whichever rendering path
is in use:

| Class | Commands |
|---|---|
| **Mirror** | `mirror_config` (scale, mask, background) · `mirror_frame` · `mirror_rect` · `resync` |
| **Drawlist** | `ctx_drawlist` (forwarded ctx protocol) · `ctx_reset` |
| Mode | `set_mode`, `get_edid`, `blank`, `set_palette` |
| Assets | `upload_asset` (to flash or PSRAM), `free_asset`, `list_assets` |
| Draw | `clear`, `rect`, `line`, `blit`, `blit_rect`, `blit_scaled`, `text`, `tilemap`, `sprite_batch` — the bespoke fallback, if drawlist forwarding does not work out |
| Frame | `present` (flip), `vsync_wait`, `set_layer` |
| Audio | `queue_pcm` (HDMI audio data islands — no extra pins needed) |
| Bridge | `i2c_scan`, `i2c_txn` — badge reaches the Qwiic bus through the card |
| System | `ping`, `status`, `reset`, `enter_bootloader`, `fw_update` |

`resync` is a full-frame refresh on demand, kept for robustness rather than bandwidth: a
dropped or corrupted update must not be able to leave a permanent artifact on screen.

### 3.3 Achievable video modes — and the HSTX ceiling

**HSTX is specified at 300 Mbps per pin.** Each of the four pairs on GPIO12–19 carries one
TMDS lane, and a DVI lane runs at ten bits per pixel clock, so the ceiling is a **30 MHz
pixel clock**. That single number decides the whole mode list:

| Mode | Pixel clock | Per lane | vs 300 Mbps |
|---|---:|---:|---|
| **640×480 @60** | 25.2 MHz | 252 Mbps | **84% — in spec** |
| 720×400 @70 | 28.3 MHz | 283 Mbps | 94% — in spec |
| 800×600 @60 | 40 MHz | 400 Mbps | 133% — ~33% overclock |
| 1280×720 @30 or @60 | 74.25 MHz | 742.5 Mbps | 248% — **not achievable** |

720p is not a stretch goal, it is out of reach: standard CEA timing needs two and a half
times what the peripheral is rated for, which is not a margin you tune into. Anything
above 640×480 means running out of spec.

So the practical mode list is short:

| Mode | Source | Colour | Buffering | Confidence |
|---|---|---|---|---|
| 240×240 ×2 → 480×480 pillarboxed in 640×480 @60 | mirror | 16 bpp | 2×115 KB in SRAM | **High — v1 primary** |
| 320×240 doubled to 640×480 @60 | display list | 16 bpp | 2×150 KB in SRAM | High |
| 640×480 @60 | display list | 8 bpp palette | 307 KB SRAM + PSRAM back buffer | High |
| 640×480 @60 | display list | 16 bpp | PSRAM-backed, line-buffer DMA ~37 MB/s | **Measured short: ~27 MB/s achieved, see below** |
| 800×600 @60 | display list | 8 bpp palette | PSRAM-backed | Low — 33% HSTX overclock, out of spec |

640×480 is not merely the safe choice; it is very nearly the only standard mode the
peripheral can reach. That is fine for the primary product — 480×480 fits its vertical
resolution exactly.

**Measured on the Metro bench (Phase 0 B2, `firmware/phase0-metro/`):** DMA-driven reads
out of PSRAM (what real HSTX scanout would do) reach **~27.1 MB/s**, both as one big
bulk transfer and as 480 separate per-line transfers back to back — the two being nearly
identical rules out DMA setup overhead as the cause. That's ~76% of a measured **35.8 MB/s
theoretical ceiling** (`clk_sys` 150 MHz, QMI CLKDIV 2 → 75 MHz PSRAM clock, quad SPI), the
missing 24% being ordinary QSPI protocol overhead (command/address/dummy cycles, periodic
chip-select toggling for PSRAM page refresh) — not a bug.

**The more important number is the 35.8 MB/s ceiling itself, not the 76% efficiency.**
75 MHz is the *fastest* PSRAM clock reachable at `clk_sys` 150 MHz — `hardware_psram`'s
driver won't use divisor 1 above 100 MHz (safety margin below the PSRAM's 133 MHz rating),
and 150 MHz/2 is the only other integer divisor available. So even a hypothetical
zero-overhead read at this clock (35.8 MB/s) would still fall short of the ~35-37 MB/s
that continuous 640×480@60 16bpp scanout actually requires (640×480×2 bytes × 60 fps ≈
35.2 MB/s) — there is no configuration tweak at `clk_sys` 150 MHz that closes this gap.
Reaching it needs a higher `clk_sys` (RP2350 overclock — e.g. ~266 MHz would allow a
divisor-2 133 MHz PSRAM clock, the chip's full rating, well clear of the requirement even
at 76% efficiency), which is a real hardware/reliability decision for a later phase, not
a Phase 0 config change.

**This affects the PSRAM-backed 16bpp display-list mode only — not v1.** Mirroring's
framebuffer lives entirely in SRAM (§3.4: 2×115 KB, never touches PSRAM), so this finding
doesn't touch the primary product. It does mean the PSRAM-backed 640×480 16bpp advanced
mode, as measured at stock clocks, cannot sustain continuous full-frame scanout — on top of
B1's finding that ctx rasterisation into that same buffer is also too slow for animation.
Both point the same direction: at stock clocks, this mode suits occasional/static content,
not continuous animated full-frame use. The 8bpp palette mode one row up (307 KB, fits in
SRAM + a PSRAM back buffer) doesn't have this ceiling and is worth preferring if the
advanced mode is pursued further.

### 3.4 What is left over

**Almost everything.** Mirroring is close to a pure DMA workload on the RP2350 — the CPU
barely participates — and that is what makes the display-list path an addition rather than
an alternative.

The reason is that nothing is materialised. There is no 640×480 framebuffer; there is a
240×240 source scaled **during scanout**. HSTX's shift register emits each 16-bit pixel
twice for horizontal doubling, and the DMA chain re-reads each source line for vertical.
Same mechanism the pico HSTX examples use for 320×240 → 640×480: no extra memory, no
cycles.

| Task | Mechanism | CPU |
|---|---|-----|
| TMDS encoding | HSTX hardware encoder | none |
| Scanout, 31,500 lines/s | chained DMA, per-line descriptors | ~2–5% of one core |
| RGB565 byteswap | DMA `BSWAP` bit | none |
| Horizontal ×2 | HSTX shift register | none |
| Vertical ×2 | DMA re-reads each source line | none |
| Circular mask + pillarbox | precomputed per-line descriptor table, built once at mode-set | none per frame |
| SPI frame receive | DMA, one interrupt per frame | <1% |
| Buffer swap | pointer flip on vsync | negligible |

The 2–5% is the only real number, and it depends on whether scanout is fully DMA-chained
or takes a per-line IRQ. Treat it as single-digit percent of one core and the rest as free.

**Measured (Phase 0 A1 Stage 2, `firmware/phase0-dvi2/`): ~6.9% of one core**, with a
per-line (in fact per-line-*phase*, 4 IRQs/row) mechanism deliberately less efficient than
the one-IRQ-per-frame ring-buffer approach assumed above, plus USB CDC overhead present in
the measurement. Single-digit percent, as estimated — a genuinely more efficient scanout
mechanism should land inside the original 2–5% range.

| Resource | Used by mirroring | Free |
|---|---|---|
| Core 0 | ~5% | ~95% |
| Core 1 | 0 | **all of it** |
| SRAM (520 KB) | 230 KB double-buffered + ~80 KB code | **~210 KB** |
| PSRAM (8 MB) | none | **all of it** |
| Flash (16 MB) | ~1 MB firmware | ~15 MB |
| DMA channels (16) | 4–5 | ~11 |
| PIO state machines (12) | 2 — SPI slave, DDC | ~10 |
| Scanout memory bandwidth | 13.8 MB/s | hundreds available |

`clk_hstx` is a separate clock generator on the RP2350, so HSTX can run at the 126 MHz that
640×480 DVI needs while `clk_sys` runs independently. **The video timing does not constrain
what the cores are clocked at.**

So core 1 can render a display-list surface while core 0 handles the mirror and scanout,
with the compositor merging them at scanout time. The two modes coexist.

#### The bezel — a v1.1 feature the headroom pays for

**The 80 px pillarbox bars either side are dead screen space**, and compositing into them
costs a few more DMA descriptors and some of a core that is otherwise idle.

Badge battery, WiFi state, app name, a clock, an FPS readout — a proper bezel around the
mirrored circle. It is close to free, and it is the difference between output that looks
designed and output that looks letterboxed. Not v1: get the mirror working first, then this
is the obvious next thing.

The same headroom also affords screenshots and capture to microSD (115 KB/frame, so
full-rate video is marginal over SPI but stills and low-rate capture are comfortable), and
HDMI audio data islands.

#### What would consume it

Materialising a full-resolution framebuffer. 614 KB does not fit in SRAM, so it moves to
PSRAM and pulls ~37 MB/s of scanout bandwidth — the mode rated "needs measurement" in §3.3.
That is precisely why scale-during-scanout is the right approach for the primary path, and
why the primary path leaves the second core untouched.

## 4. Hardware architecture

```
      ┌─────────── hexpansion edge connector (1.0 mm, ENIG) ───────────┐
      │  +3V3 (600 mA)   SDA/SCL   HS_F..HS_I   LS_A..LS_E   DET→GND   │
      └───┬──────────────┬───────────┬────────────┬────────────────────┘
          │              │           │            │
     ┌────▼────┐   ┌─────▼─────┐ ┌───▼────┐  ┌────▼─────┐
     │ bulk +  │   │ I2C0      │ │ SPI0   │  │ RUN /    │
     │ ferrite │   │ target    │ │ slave  │  │ IRQ /    │
     └────┬────┘   │ @0x50     │ │ 20–23  │  │ BOOTSEL  │
          │        │ GPIO24/25 │ └───┬────┘  └────┬─────┘
          │        └─────┬─────┘     │            │
          │              └───────────┴────────────┘
          │                          │
  ┌───────▼───────┐          ┌───────▼────────┐        ┌──────────────┐
  │ TPS2116 mux   │          │   RP2350A      │◄──QSPI─┤ W25Q128 16MB │
  │ prio USB, rev-│          │   QFN-60       │  CS0   └──────────────┘
  │ blocking BOTH │          │  L1 3.3 µH     │        ┌──────────────┐
  └───────┬───────┘          │  Y1 12 MHz     │◄──QSPI─┤ APS6404 8 MB │
          │                  └─┬──┬──┬──┬──┬──┘  CS1   └──────────────┘
          │      HSTX 12–19    │  │  │  │  │ SWD
          │             ┌──────▼┐ │  │  │  └──────► J3  3-pin JST-SH debug
          │             │2× ESD │ │  │  │           SWCLK · GND · SWDIO
          │             │arrays │ │  │  └─SPI1 8–11─► microSD  (J6)
          │             └──────┬┘ │  └────I2C1 6/7──► J4,J5 Qwiic ×2
          │                    │  │                   4k7 pull-ups on jumper
          │                    │  └─PIO I2C 3/4────► PCA9306 ──► DDC / EDID
          └──────── +5V ───────┴─────────────────────────────► J1 mini-HDMI (C)

  J2 USB-C ─► TVS + 5k1 CC ─► buck 5V→3V3 ─► mux input A (priority)
              USB D± ─────────────────────────► RP2350
  3V3_LOCAL ─► TPS61023 boost ─► V5_HDMI  (only 5 V source; never muxed to VBUS)
  SW1 BOOT   SW2 RESET   badge-rail sense ─► GPIO
  LED1 power (always on)   LED2 status (GPIO1)   LED3 SK6805 RGB

  Flats:  outer = J1 + J2   ·   side A = J4 + J5   ·   side B = J6
```

### 4.1 RP2350A pin budget (30 GPIO, QFN-60)

Every peripheral group below was checked against the RP2350's pin-mux tables — SPI0/SPI1
and I2C0/I2C1 can only appear on fixed pin groups, and that, not pin count, is what
constrains this map.

**Correction (30/08/26):** the SPI0/GPIO20–23 row below originally listed a role
assignment (SCK/MOSI/MISO/CS in GPIO order) that turned out not to match RP2350 silicon.
Found while preparing to physically wire a hexpansion devkit for Phase 0 A2, and verified
against the authoritative source — the `FUNCSEL` enum values in `RP2350.svd` (Raspberry
Pi's own machine-generated register definitions, ships with pico-sdk) — not the datasheet
PDF's Table 3, which is easy to misread by eye across its multi-line row continuations (a
mistake made once already while checking this). GPIO20–23 is still a valid, complete SPI0
group (every pin there does have *some* SPI0 role), but the specific role each pin plays
is fixed by silicon and doesn't match what was assumed:

| GPIO | Previously assumed | Actual silicon role (`RP2350.svd` FUNCSEL=1) |
|-----:|---|---|
| 20 | SCK | `spi0_rx` (= MOSI, since the RP2350 is the SPI *slave* here — RX is whichever direction receives, and the slave receives from the master on MOSI) |
| 21 | MOSI | `spi0_ss_n` (= CS) |
| 22 | MISO | `spi0_sclk` (= SCK) |
| 23 | CS | `spi0_tx` (= MISO, slave transmits to master on TX) |

**Resolved (30/08/26):** initially thought this needed discovering a fixed badge-side
SCK/MOSI/MISO/CS assignment for `HS_F`/`HS_G`/`HS_H`/`HS_I`, but it doesn't — per §1.2, the
badge's HS lines are **matrix-routed (not IOMUX) on the ESP32-S3**, meaning the badge's own
firmware can assign any SPI role to any HS pin, in software, per hexpansion. Confirmed by
checking a real shipped example —
[`DanNixon/ethernet-hexpansion`](https://github.com/DanNixon/ethernet-hexpansion/blob/main/docs/pins.md)
uses `HS_G=SCK, HS_H=MOSI, HS_I=MISO, HS_F=interrupt (not SPI at all), CS=LS_2` — a
genuinely different choice than this project's own original assumption, which only makes
sense if the mapping is each hexpansion's free choice, not a badge-side constraint. So this
project makes its own choice too, matched by badge-side driver code written for it (Phase
3/4), matching physical badge pad order straight to GPIO order for simplicity:

| Badge signal | RP2350 GPIO | Silicon role |
|---|---:|---|
| `HS_F` | 20 | MOSI (`spi0_rx`) |
| `HS_G` | 21 | CS (`spi0_ss_n`) |
| `HS_H` | 22 | SCK (`spi0_sclk`) |
| `HS_I` | 23 | MISO (`spi0_tx`) |

**IMPORTANT correction (19/09/26), found the hard way while wiring for a real mirror
test:** the table above is this project's own free choice for the RP2350 side, but it does
**not** automatically agree with hazanjon's actual badge-side driver
(`flow3r_bsp_display_mirror.c`'s `PORT_PINS`), which real mirroring on this project ended up
depending on. For hexpansion **port 4** specifically, that badge-side code puts SCK on
`HS_G` and CS on `HS_H` — the opposite of this project's own `HS_G`=CS, `HS_H`=SCK
convention above. Since neither side's role assignment can be changed in software (RP2350
GPIO21/22's SPI0 roles are silicon-fixed, per the correction above; the badge's `PORT_PINS`
defaults are what the currently-deployed driver relies on), the only way to reconcile them
is a **physical wire crossing at the RP2350 end**:

| Badge signal | GPIO per the table above | Actually wire it here for port 4 |
|---|---:|---:|
| `HS_F` | 20 | 20 (unchanged) |
| `HS_G` | 21 | **22** |
| `HS_H` | 22 | **21** |
| `HS_I` | 23 | 23 (unchanged) |

Confirmed empirically via `mirror_debug`'s live per-pin GPIO edge counters: with the
straight (uncrossed) wiring, CS and MOSI toggled together at ~160kHz (CS was receiving the
badge's real SCK output by mistake) while the pin labelled SCK saw under 10Hz; after
crossing `HS_G`↔`HS_H`, SCK showed ~14.47 million real toggles closely matching MOSI's own
count, and CS showed a clean, correctly-scaled edge count. **Wire `HS_F`→20, `HS_G`→22,
`HS_H`→21, `HS_I`→23 for any real mirror test on port 4** — the straight table above
documents this project's own original intent, not what actually needs to be wired for
compatibility with the badge's current mirror driver.

**Update (29/09/26):** the same crossing has now been tested on **all six ports**, not
just port 4, so the PCB wires `HS_G`→GPIO22 and `HS_H`→GPIO21 unconditionally.

| Pin | Function |
|---|---|
| — | **Update (28/09/26, schematic v0.1):** GPIO27 = SK6805 data, GPIO28 = badge-rail sense, GPIO29 = HDMI boost enable. `LS_C`/`LS_D`/`LS_E` are left unconnected. `HS_G`/`HS_H` are crossed on the PCB (see above). DDC and microSD are dropped, so **GPIO3, 4, 5 and 8–11 are spare**. The table below is otherwise unchanged. |
| 0 | PSRAM chip select (QMI CS1 — GPIO0/8/19 are the only options on RP2350A, and 19 is taken by HSTX) |
| 1 | Status LED (LED2) |
| 2 | HDMI hot-plug detect, via 100k/100k divider from +5 V |
| 3, 4 | DDC/EDID via **PIO I2C** through the PCA9306 level shifter |
| 5 | microSD card-detect |
| 6, 7 | **I2C1 (hardware) → Qwiic sockets J4/J5** |
| 8–11 | **SPI1 → microSD** (8 MISO, 9 CS, 10 SCK, 11 MOSI) |
| **12–19** | **HSTX → 4 TMDS pairs (clock + 3 data)** — fixed by silicon |
| 20–23 | SPI0 slave ↔ `HS_F`(MOSI)/`HS_G`(CS)/`HS_H`(SCK)/`HS_I`(MISO) — see §4.1's tables above; **note the mandatory `HS_G`/`HS_H` wire-crossing correction for port 4** |
| 24, 25 | I2C0 target ↔ badge SDA / SCL (the emulated EEPROM) |
| 26 | → LS_B, attention/IRQ to the badge (proposed use of a spare line — see note) |
| 27 | ← LS_C, proposed as a bootloader-entry request from the badge (see note) |
| 28, 29 | ← LS_D / LS_E, spare |
| RUN pin | ← LS_A (badge-controlled reset) **and** SW2 reset button |
| SWCLK / SWDIO | → J3, Raspberry Pi 3-pin debug connector |
| USB D± | → J2 USB-C |
| BOOTSEL | → SW1 |

Note the mapping trades JTAG on port 1 (GPIO39–42 are the ESP32's JTAG pins) — use
port 2 or 6 during badge-side debugging.

**On `LS_B`/`LS_C`'s roles (30/08/26):** unlike `LS_A`, which the badge's own hardware
fixes as a reset line (confirmed on both this project's connector schematic and
`DanNixon/ethernet-hexpansion`'s independent design), `LS_B`–`LS_E` are just generic,
badge-provided slow I/O-expander lines with **no fixed protocol meaning** — checked against
two real hexpansions (`DanNixon/ethernet-hexpansion`, `sammachin/rp2040-hexpansion`), and
neither uses an LS line for anything resembling "attention" or "bootloader entry." The
attention/IRQ use for `LS_B` and the bootloader-entry idea for `LS_C` above are **this
project's own proposed uses of two otherwise-spare lines**, not a badge requirement — free
to keep, drop, or repurpose without any badge-compatibility consequence, same as the
`HS_x` SPI role question above.

**Why the RP2350A and not the B.** The B (QFN-80, 10×10 mm, 48 GPIO) would relax this map —
PSRAM CS moves to GPIO47, the canonical pin every reference example uses, and UART0 comes
back on GPIO0/1. But it doubles the package footprint from 49 mm² to 100 mm² on a board
where §4.4 already says the outer flat closes with no slack, and escaping ~30 signals from
an 80-pad ring is harder than from a 60-pad one, not easier. It also buys **no extra
peripherals** — both variants have exactly 2× SPI and 2× I2C, so DDC stays on PIO either
way. **The A is the baseline and the map below is complete and conflict-free; the B is the
documented fallback** if Phase 0 A2 shows the A cannot bring it up.

**Why the SD card forced a reshuffle.** SPI0 is already the badge slave on GPIO20–23, so
the card needs SPI1 — whose only groups are {8,9,10,11}, {12–15} and {24–27}. HSTX owns
12–19 and the badge I2C target owns 24/25, so **{8,9,10,11} is the only possibility**.
That displaced the Qwiic bus to I2C1 on GPIO6/7 and DDC to a PIO I2C on GPIO3/4. The one
casualty is the UART0 test points, which were already redundant with the USB CDC console.

**Why Qwiic gets the hardware I2C and DDC gets PIO:** user-attached Qwiic devices are the
unpredictable ones — arbitrary addresses, arbitrary clock stretching, arbitrary bus
speeds — so they get the real peripheral. EDID is a one-shot low-rate read at mode-set
time whose timing we fully control, and PIO I2C on RP2350 handles it comfortably. Keeping
them on separate buses also avoids the address collision that would otherwise be
guaranteed: monitor EDID EEPROMs live at 0x50, and so do plenty of Qwiic boards.

### 4.2 Debug and control surface

| Item | Detail |
|---|---|
| J2 USB-C | Power input, UF2 mass-storage firmware update, USB CDC serial console |
| J3 SWD | 3-pin JST-SH 1.0 mm, **Raspberry Pi debug connector standard** (SWCLK · GND · SWDIO) — a Debug Probe plugs straight in |
| SW1 BOOT | Hold at power-up for UF2 bootloader |
| SW2 RESET | Pulls RUN low; shares the pin with the badge's LS_A reset line |
| LED1 | Power — always on when the rail is up. High-efficiency part on 4k7, ~0.4 mA |
| LED2 | Status/user, GPIO1 |
| LED3 | SK6805 RGB, optional |
| GPIO3 test pads | Spare, brought out for bring-up probing |

Three independent ways in — USB, SWD, and the badge's own RUN control — means there is no
plausible state this board gets into that you cannot recover from.

### 4.3 Qwiic bus

Two JST-SH 4-pin sockets wired in **parallel on one bus**, which is the standard Qwiic
chaining idiom: the hexpansion can sit mid-chain rather than only at the end. 4k7
pull-ups to 3V3 with a solder jumper so they can be removed when the card joins a chain
that already has them.

Budget roughly **100 mA** of the port's headroom for attached devices (§4.5 leaves about
that). A Qwiic device that pulls more than that will trip the badge's port switch, not
ours — worth a line in the user documentation.

### 4.4 Flat allocation — the real mechanical problem

At the template's 32 mm the outer flat is 18.5 mm and **mini-HDMI + USB-C do not fit on
it** (19.5 mm of connector body before margins). Growing the board to **44 mm across
flats** gives a 25.4 mm flat and makes the layout work:

| Flat | Contents | Used |
|---|---|-----:|
| **Outer** (opposite the tab) | J1 mini-HDMI 10.5 + J2 USB-C 9.0, ~2 mm margins | 25.5 of 25.4 mm |
| **Side A** | J4 + J5 Qwiic, 6.2 each | 18.4 of 25.4 mm |
| **Side B** | microSD socket, ~15 mm | 19.0 of 25.4 mm |
| Two tab-side flats | Face the badge — unusable | — |

Fat-cable connectors have to be on the outer flat: with a 4.1 mm gap to the neighbouring
hexpansion, a USB-C or HDMI plug body simply will not fit beside a side flat. JST-SH
Qwiic cables (~4–5 mm wide, thin and flexible) are borderline in that gap and fine when
the adjacent bay is empty, which is the common case. Same for the SD slot: card insertion
needs finger room that a populated neighbouring bay does not leave.

Two things to be honest about:

* **The outer flat closes with no slack** — 25.5 mm of connector-plus-margin on a 25.4 mm
  flat. It works with ~1.9 mm end margins and 2 mm between connectors, and the corner
  radii give a little back, but this is a placement study, not an assumption.
* **microSD is the first thing to cut** if the layout fights back. With 16 MB of flash and
  a USB-C port for loading assets, it is a convenience, not a requirement.

#### If you want real slack: a radial wedge instead of a hexagon

The 60° sectors diverge, so available width grows with radius: at radius `r` from the badge
centre a shape can be about `r` wide (half-width `r·sin 30° = r/2` each side) before it
fouls its neighbours. Keeping the tab-end profile of the template hexagon and flaring out
to `r ≈ 70 mm` gives roughly a **60 mm outer edge** — everything on one face with room
to spare, for about the same radial extent as the 44 mm hexagon.

The costs are that it stops looking like a Tildagon hexagon, and more mass hangs off a
1.0 mm card edge and two M2 screws. **Recommendation: build the 44 mm hexagon; hold the
wedge in reserve for if the outer-flat placement study fails.**

### 4.5 Power domains and badge isolation

> **Design rule: the hexpansion never powers the badge.** Not in normal operation, not
> during insertion or removal, not under a single-component failure. USB-C powers this
> board only. The badge's BQ25895 stays the sole authority over the badge's own rails.

Everything below exists to enforce that rule.

| Rail | Source | Notes |
|---|---|---|
| `VBUS` | USB-C J2 | 5 V. TVS + USBLC6 ESD, 5k1 CC1/CC2 pulldowns |
| `3V3_USB` | Buck from `VBUS` | The local rail when USB is present |
| `3V3_BADGE` | Edge pads 15/16 | 600 mA through the badge's MT9700 load switch |
| `3V3_LOCAL` | TPS2116 mux, priority to `3V3_USB` | Powers everything on the board |
| `V5_HDMI` | Boost from `3V3_LOCAL` | The only 5 V source on the board — never muxed with `VBUS` |

#### The four backfeed paths

| # | Path | If unhandled | Mitigation |
|--:|---|---|---|
| 1 | 5 V `VBUS` reaches the badge's 3V3 rail | Destroys the ESP32-S3, both AW9523s, the TCA9548A, the display and the IMU | `VBUS` never leaves the USB domain: it feeds only the buck. The TPS2116 blocks reverse current on its badge input, so even a shorted buck cannot push 5 V outward |
| 2 | USB-derived 3V3 backfeeds pads 15/16 | Flows through the badge's load-switch body diode into `3V3_SYS`. The badge loses the ability to power the port off, and its whole rail is back-powered from your USB supply | TPS2116 priority mux with true reverse-current blocking and break-before-make. When USB is present the badge input is hard-isolated |
| 3 | Our GPIOs drive badge pins while the badge is unpowered | Phantom-powers the badge through ESP32/AW9523 ESD diodes — latch-up, pin damage | Only two pins can source: MISO (HS_H) and the LS_B interrupt. Firmware holds both tri-stated until the badge-rail sense reads live. 33 Ω series on the HS lines caps fault current |
| 4 | The boost drives `VBUS` backwards | 5 V on the USB-C connector: spec violation, hazard to whatever is plugged in | Deleted by construction — the HDMI 5 V rail is never muxed with `VBUS` |

#### Why a mux and not a pair of FETs

The earlier revision said "supply OR-ing (Q1/Q2)" without a topology, and two P-FETs
described that loosely do not do the job: **a single P-FET always has a body diode**, and
whichever way you orient it one direction conducts. Blocking both ways needs back-to-back
FETs plus their gate drive — four parts and a switchover behaviour you have to get right
yourself.

A **TPS2116** does it in one part: two inputs, automatic priority, genuine reverse-current
blocking on both, break-before-make. `3V3_USB` is input A with priority; `3V3_BADGE` is
input B. Q1/Q2 come out of the BOM.

Path 2 deserves emphasis. A high-side P-FET load switch conducts OUT→IN through its body
diode when the output is pulled above the input, unless the part explicitly blocks reverse
current — and the MT9700/AAT4610 class does not advertise that. So without the mux, running
on USB back-feeds the badge's `3V3_SYS` **even with the port switched off in software**.
The datasheet in `badge-2024-hardware/datasheets/` is a scanned image and cannot be
searched, so this is assumed until confirmed — which is the correct posture regardless.

#### Path 3 is mostly free

Of our badge-facing signals, SDA and SCL are open-drain — they only ever pull low, so they
cannot inject current into an unpowered bus. SCK, MOSI and CS are inputs to us. That leaves
**exactly two sourcing outputs**: MISO on HS_H, and the attention line on LS_B. So:

* Divide `3V3_BADGE` through 100k/100k to a GPIO as a **badge-presence sense**.
* Firmware tri-states MISO and LS_B until that sense reads live, and re-tri-states them if
  it drops. This doubles as the RP2350 knowing whether it is in a badge or standalone.
* **33 Ω series on each HS line.** It caps fault current and doubles as source-series
  termination, which 40 MHz edges want anyway.

**Addendum (28/09/26): pull resistors are a fifth backfeed path.** The E9 pull-ups in
§4.6 must not go to `3V3_LOCAL` on any badge-facing line. An unpowered badge would be fed
through them, just as through a driven GPIO. In schematic v0.1, badge-side pull-ups go to
`3V3_BADGE` only; `BADGE_SDA`/`SCL` get none (the badge has its own); and firmware must
not enable internal pull-ups on GPIO24/25. The RUN pull-up reaching `LS_A` was closed the
same day: `LS_A` now drives RUN through an SN74LVC1G07 open-drain buffer (U11) powered from
`3V3_BADGE`, with `LS_A` pulled up to `3V3_BADGE`. The buffer's I_off spec (≤10 µA) blocks
the path when the badge is off. A diode can't, because reset and leak flow the same way.

#### USB-C sink requirements

* **5k1 CC1/CC2 pulldowns.** Without them a Type-C source delivers nothing at all.
* Nothing on the board may present as a source.
* **TVS on `VBUS`** so a misbehaving PD supply cannot exceed the buck's input rating.

### 4.6 Points that need care

* **Mini-HDMI Type C does not share Type A's pin assignment.** The 19 pins are reordered.
  Wire the schematic from the chosen connector's datasheet — do not adapt a Type A
  footprint's netlist, this is a classic and expensive mistake.
* **RP2350-E9 erratum.** Internal pull-downs latch on floating inputs. Use external
  pulls on anything that can float — the LS lines, CS, and both I2C pairs — and do not
  rely on internal pull-downs anywhere.
* **TMDS drive.** The Pico DVI Sock / Adafruit HSTX-DVI approach — GPIOs driven directly
  into the sink's 50 Ω terminations with drive strength set to 12 mA, no buffers — is
  proven and is what we use. Series-resistor footprints stay on the board as 0 Ω, as
  insurance. *(28/09/26: dropped. The bench has always driven TMDS directly, and the
  eight footprints cost space next to the socket.)*
* **HDMI +5 V** must be supplied to the sink, 55 mA minimum, or many monitors
  will not present EDID. Boost it, and gate the boost's EN pin from a GPIO so it comes
  up *after* firmware, not during inrush.
* **ESD on TMDS** needs sub-pF capacitance. `TPD4E05U06` (0.4 pF) is the right family;
  a generic USBLC6 at 3 pF is not.
* **Inrush.** The MT9700 will trip at 600 mA. Keep total bulk capacitance modest
  (≈ 40 µF) and stagger the boost enable, or the hexpansion will fail to power on.

### 4.7 Power budget

| Rail / block | Est. current @3V3 |
|---|---:|
| RP2350 @150 MHz, both cores + HSTX + DMA | 60 mA |
| TMDS drive, 4 pairs | 50 mA |
| PSRAM active | 30 mA |
| Flash (bursty) | 15 mA |
| HDMI +5 V @55 mA through boost (85% eff.) | 98 mA |
| microSD during transfers (bursty, idle ≈ 0.2 mA) | 50 mA |
| Level shifter, LEDs, misc | 11 mA |
| **Total typical, SD idle, no Qwiic devices** | **~264 mA** |
| **Peak, SD streaming** | **~400 mA** |
| Headroom left for attached Qwiic devices | ~100 mA (shared with SD bursts) |

Comfortably inside 600 mA — but ~0.9 W is a real load on a badge battery. Expect
**2–3 hours** of badge runtime with the GFX card live on badge power alone.

On USB the same 264 mA at 3.3 V is ~0.87 W, so `VBUS` draws about **195 mA at 5 V** through
a 90 %-efficient buck — well inside a USB 2.0 port's 500 mA, no PD negotiation needed. With
USB-C plugged in the hexpansion powers itself and **draws nothing at all from the badge**;
the TPS2116 hard-isolates the badge input rather than merely sharing the load (§4.5).

---

## 5. Faking the EEPROM

The RP2350 brings up I2C0 as a target at `0x50` with 16-bit addressing and answers as a
64 KiB EEPROM:

* `fs_offset` = 64, `eeprom_page_size` = 64, `eeprom_total_size` = 65536
* Header as §1.4, manifest `2026`, assigned VID/PID, `unique_id` per board from the
  RP2350's unique chip ID
* Reads served from a flash-backed image with a RAM shadow; writes accepted with
  page-write semantics and ACK polling, then committed to flash

**The one genuine risk is a start-up race.** The badge enables port power and scans I2C
shortly after. If the RP2350 has not brought up its I2C target yet, the hexpansion
enumerates as "no EEPROM" and the app never runs. Three mitigations, all cheap:

1. Bring the I2C target up in the first few hundred microseconds of `main()`, before
   PSRAM init, HSTX, or anything else. Target **< 20 ms** from power-good.
2. **Clock-stretch** while flash is being read. The badge is a normal I2C master and will
   wait.
3. **Keep a real 24C64 footprint on the board (DNP) with a solder jumper.** If emulation
   turns out to be flaky in the field, populate a Zetta ZD24C64A, move the jumper, and
   the hexpansion enumerates from silicon while the RP2350 moves to a secondary address.
   Twelve cents of insurance against a bug that would otherwise brick the product.

A nice second-order benefit: because writes are accepted, the badge can push a firmware
image *into* the fake EEPROM and the RP2350 can flash itself from it. Field updates with
no cable.

---

## 6. Bill of materials

**Update (28/09/26):** U1 is now the **RP2354A** (the RP2350A die with 2 MB of
flash in the package), so U2, the external W25Q128, is removed. U3, the PSRAM, is
now **DNP**: footprint only, for optional hand soldering. See §10.

**Update (28/09/26, schematic v0.1):** the schematic is drawn, and `bom.csv` is now
generated from it with LCSC numbers for every part, so the table below is the original
plan only. Connector references in the schematic: J1 = hexpansion edge connector,
J2 = USB-C, J3 = SWD, J4 = Qwiic, J5 = HDMI. Differences: full-size **HDMI Type A** (J5);
**one** Qwiic socket; **TLV62569**
buck (the TPS62203 is 300 mA); the PSRAM part is the **APS6404L-3SQR-SN** (SOP-8), because
the `-ZR` below is actually USON-8; the ferrite beads are gone; and the design guide's
crystal series resistor, USB series resistors, HDMI +5V PTC and test pads are added.
A later trim the same day removed **U5 (PCA9306) and all of DDC/EDID**, because the
output is fixed at 640×480; removed the **0 Ω TMDS resistors** (see §4.6); and cut the
decoupling to Raspberry Pi's minimal design. **microSD (J6) was then dropped too**
(see §10). The badge reset gained a backfeed-proof buffer (U11, §4.5). Result: 80
JLC-placed parts, about $5.11 a board at the 10-board tier.
The README's Next step section has the details, including the §4.1 pin-map changes.

Per board, 92 fitted placements (U8 is DNP and excluded from the totals). Prices are
LCSC/JLCPCB indicative in USD *(est.)* — **verify at order time**,
they move constantly and the RP2350A in particular has swung between $1.03 and $1.71.

| # | Ref | Part | Package | Qty | @10 | @50 |
|--:|-----|---|---|----:|----:|----:|
| 1 | U1 | RP2350A (C42411118) | QFN-60 7×7 | 1 | 1.45 | 1.20 |
| 2 | U2 | W25Q128JVSIQ 16 MB QSPI flash | SOIC-8 | 1 | 1.10 | 0.90 |
| 3 | U3 | APS6404L-3SQR-ZR 8 MB QSPI PSRAM (C3040877) | SOP-8 | 1 | 1.15 | 1.00 |
| 4 | U4 | TPS61023 boost, 3V3→5V | SOT-563 | 1 | 0.55 | 0.45 |
| 5 | U5 | PCA9306 DDC level shifter | VSSOP-8 | 1 | 0.32 | 0.26 |
| 6 | U6,U7 | TPD4E05U06 ESD array, 0.4 pF | USON-10 | 2 | 0.76 | 0.60 |
| 7 | U8 | ZD24C64A fallback EEPROM — **DNP** | SOP-8 | 1 | 0.11 | 0.09 |
| 8 | J1 | **Mini-HDMI Type C receptacle**, right-angle | SMD | 1 | 0.65 | 0.52 |
| 9 | J2 | USB-C 16P receptacle (power + UF2 + CDC) | SMD | 1 | 0.30 | 0.24 |
| 10 | J3 | **JST-SH 3-pin, RPi debug standard** (SM03B-SRSS-TB) | SMD | 1 | 0.12 | 0.10 |
| 14 | J4,J5 | **JST-SH 4-pin Qwiic** (SM04B-SRSS-TB) | SMD | 2 | 0.26 | 0.22 |
| 11b | J6 | **microSD socket, push-push** | SMD | 1 | 0.35 | 0.30 |
| 12 | D1 | USBLC6-2SC6 USB ESD | SOT-23-6 | 1 | 0.10 | 0.08 |
| 13 | U9 | **TPS2116 power mux** — priority + reverse blocking | SOT-23-6 | 1 | 0.55 | 0.45 |
| 13b | U10 | **Buck 5V→3V3**, ≥500 mA (AP3417 / TPS62203) | SOT-23-5 | 1 | 0.35 | 0.28 |
| 13c | L3 | 2.2 µH shielded (USB buck) | 0805 | 1 | 0.09 | 0.07 |
| 13d | D2 | TVS on VBUS (SMF5.0A) | SOD-123 | 1 | 0.05 | 0.04 |
| 14 | Y1 | 12 MHz crystal, ±30 ppm | 3225 | 1 | 0.16 | 0.13 |
| 15 | L1 | 3.3 µH shielded (RP2350 VREG_LX) | 0805 | 1 | 0.10 | 0.08 |
| 16 | L2 | 2.2 µH shielded (boost) | 0805 | 1 | 0.09 | 0.07 |
| 17 | FB1,FB2 | Ferrite bead 600 Ω @100 MHz | 0402 | 2 | 0.04 | 0.03 |
| 18 | C | 22 µF bulk / 10 µF / 1 µF / 100 nF / 15 pF | 0805–0402 | 34 | 0.34 | 0.26 |
| 19 | R | Pulls, dividers, Qwiic 4k7, SD pulls, **5k1 CC**, **badge sense**, **33 Ω HS series**, LED | 0402 | 30 | 0.10 | 0.06 |
| 20 | SW1,SW2 | **Tactile switches — BOOT and RESET** | 3×2 mm | 2 | 0.12 | 0.10 |
| 21 | LED1,LED2 | **Power (always on) + status** | 0603 | 2 | 0.04 | 0.04 |
| 22 | LED3 | SK6805 RGB status | 2427 | 1 | 0.08 | 0.06 |
| | | **Total parts / board** | | **92 fitted** | **$9.20** | **$7.53** |

Machine-readable version: [`bom.csv`](bom.csv).

Component-level notes:

* GD25Q128 substitutes for the W25Q128 at ~$0.85 if flash pricing bites.
* The `-ZR` PSRAM part is the one to buy — the `-SN` variant is 2.5× the price for the
  same die.
* U8 stays unpopulated in normal builds; it exists so the EEPROM-emulation risk in §5
  has a hardware answer.
* J3/J4/J5 are all JST SH 1.0 mm — one connector family, two part numbers, which keeps
  the feeder count down.

---

## 7. Costing: 10 / 20 / 50 boards

Turnkey PCBA at JLCPCB, delivered to the UK. Fee structure from JLCPCB's published
rates (setup ≈ $8/side, feeder ≈ $1.50 per extended part type, stencil ≈ $1.50,
SMT labour ≈ $0.0017/joint with a $0.48/board floor). Board is a **44 mm across-flats
hexagon** (44 × 50.8 mm bounding box, 16.8 cm²), 4-layer, 1.0 mm, ENIG,
impedance-controlled, ~360 solder joints, ~19 extended part types,
**double-sided assembly**.

| Line | 10 boards | 20 boards | 50 boards |
|---|---:|---:|---:|
| PCB fab (4L, 1.0 mm, ENIG, imp. ctrl) | $42 | $64 | $135 |
| Stencils (2 sides) | $3 | $3 | $3 |
| SMT setup (2 sides) | $16 | $16 | $16 |
| Feeder fees (~19 extended parts) | $29 | $29 | $29 |
| SMT labour | $6 | $12 | $31 |
| X-ray (QFN-60) contingency | $10 | $10 | $10 |
| Components (incl. MOQ overshoot) | $120 | $201 | $395 |
| **Subtotal, ex-works** | **$226** | **$335** | **$619** |
| Air freight to UK | $24 | $28 | $38 |
| UK import VAT @20% | $50 | $73 | $131 |
| Courier disbursement fee | $15 | $15 | $15 |
| **Delivered total** | **$315** | **$451** | **$803** |
| **Per board** | **$31.50** | **$22.55** | **$16.06** |
| *Per board, £ @1.27* | *£24.80* | *£17.76* | *£12.65* |

### How the price has moved

| Revision | What changed | 50-board, per board |
|---|---|---:|
| Mini-HDMI, USB-C, SWD, buttons, Qwiic — 32 mm hexagon | — | $13.28 |
| Grown to 44 mm across flats, microSD restored | +89% board area, SD socket | $15.20 (+$1.92) |
| **Power-domain isolation** | **TPS2116 mux, USB buck, TVS, CC and sense resistors** | **$16.06 (+$0.86)** |

Two of those are worth reading as value, not cost. **$1.92 nearly doubled the board area**
and is what makes the connectors fit at all — PCB fabrication is only 14–17% of the run, so
area is among the cheapest things you can buy here, and far cheaper than a respin. And
**$0.86 is what stands between a USB cable and a dead badge**; the alternative is not a
cheaper board, it is an unprotected one.

The fixed-cost shape is unchanged: **$58 of the cost is fixed** (setup, feeders, stencils,
X-ray) regardless of quantity. At 10 boards you pay $5.80/board just to turn the machine
on; at 50 it is $1.16. If there is any chance of wanting 50, order 50.

### One-off NRE, not included above

| Item | Est. |
|---|-----:|
| 5-board prototype spin (same process) | $220 |
| Second spin, assume one is needed | $220 |
| Raspberry Pi Debug Probe, mini-HDMI cable, test monitor, M2 hardware | $55 |
| **Total NRE** | **~$495** |

Fully loaded, a 50-board run lands at roughly **$26/board**; a 20-board run at
**$47/board**.

### Should you hand-assemble instead?

| | 10 boards | 50 boards |
|---|---:|---:|
| Turnkey PCBA, delivered | $315 | $803 |
| PCB + parts + own reflow, delivered | ~$250 | ~$709 |
| Saving | $65 | $94 |
| Your time | ~10 h | ~36 h |

**No.** You would be buying your own labour at under $3/hour to hand-place a 0.4 mm-pitch
QFN-60, an HDMI shell, a microSD cage and three JST-SH connectors, with yield risk on top.
Use turnkey.

### Other vendors

* **PCBWay** — comparable, usually 10–20% more, better on odd outlines and small runs.
* **Aisler** (EU) — no import VAT surprise, much friendlier for a UK/EU maker, but
  roughly 2× on assembly and a thinner parts library.
* **Eurocircuits** — excellent quality, ~3× the cost. Not for this.

Order **10% spare bare PCBs** with every run; they cost almost nothing and save a whole
lead time when you kill a board on the bench.

---

## 8. Delivery plan

### Phase 0 — De-risk on the bench (2–3 weekends)

Before drawing a single schematic symbol.

#### The rig

| Board | Variant | PSRAM | Flash | Also has |
|---|---|---|---|---|
| **Adafruit Feather RP2350 + HSTX** | **RP2350A — matches the design** | none | 8 MB | STEMMA QT, 3-pin SWD, NeoPixel, **unpopulated PSRAM footprint** |
| **Adafruit Metro RP2350** | RP2350B | **8 MB** | 16 MB — matches the BOM | microSD, STEMMA QT |

Plus the Adafruit 22-pin FPC HSTX → DVI adapter (fits both), a monitor, a bench current
meter, a Tildagon badge, and a protoboard hexpansion (`codemyriad/protogon` or DanNixon's
devkit) for the badge-link tests.

**Neither board is the design's configuration**, which is RP2350A *with* PSRAM. The Feather
has the right silicon and no PSRAM; the Metro has PSRAM on the wrong variant, where CS sits
on GPIO47 rather than the GPIO0 our RP2350A map is forced onto. So **QMI CS1 on GPIO0 on an
RP2350A is unvalidated by either board** — low risk, since it is a documented pinmux option,
but named rather than assumed (risk 18).

**The fix is cheap: populate the Feather's PSRAM footprint** with an APS6404L — BOM line 3,
about $1.15 — and it becomes an almost exact stand-in. Check Adafruit's schematic for which
pin that pad's CS routes to. If GPIO0, the map is validated as written. If GPIO8, that
collides with SD on SPI1 `{8,9,10,11}`, which is exactly why §4.1 puts PSRAM CS on GPIO0 —
confirming the choice is deliberate.

#### Part A — Feather, the design-representative bench

Runs today, unmodified. **Mirroring never touches PSRAM** (§3.4: 230 KB double-buffered in
SRAM), so the Feather covers the entire primary mode on the right silicon.

**A1. Scale-during-scanout — done, measured on real hardware.** 240×240 source in SRAM,
HSTX doing horizontal doubling, DMA re-reading each source line vertically, per-line
descriptor table for the circular mask and pillarbox. **Measured core load: ~6.9% of one
core**, close to this section's own 2–5% estimate despite Stage 2's deliberately
less-efficient IRQ mechanism (see below) — **this validates the whole mirroring
architecture**, the thing A1 exists to check.

**Stage 1 (`firmware/phase0-dvi/`) — basic 640×480@60 output, confirmed on real hardware.**
A deliberately simplified first step — 320×240 doubled to fill 640×480 exactly (no
pillarbox/mask needed, since 320×2=640 and 240×2=480 land exactly), horizontal doubling
done by pre-expanding in SRAM rather than the HSTX pixel-duplication trick, and the
simpler two-channel per-scanline-IRQ DMA mechanism from the official `pico-examples`
rather than the CPU-efficient one-IRQ-per-frame ring-buffer approach Adafruit's own
PicoDVI driver uses. Confirmed on a real monitor: 8 sharp, evenly-spaced, stable, correctly
coloured bars filling the screen — three real bugs found and fixed along the way (flipped
ribbon cable, wrong pixel clock — `clk_hstx` follows `clk_sys` undivided by default, needed
`set_sys_clock_khz(126000, true)`, not a `CSR.CLKDIV` change — and a rotated colour channel
mapping, compensated in the test pattern rather than root-caused). Full writeup in
`firmware/phase0-dvi/README.md`.

**Stage 2 (`firmware/phase0-dvi2/`) — the real A1 target, confirmed on real hardware.**
240×240 source, pillarboxed, circular-masked (`row_half_width[]`, a per-output-row
half-width table computed once at init from the circle equation — "the per-line descriptor
table for the circular mask" this section describes). **First attempt got "no signal"**:
used three separate HSTX TMDS commands per active row (left fill / pixel-priming / right
fill), which — per RP2350 datasheet §12.11.5 ("the command expander cannot output data on
the cycle where it pops a command... the expansion shift register is empty for at least one
cycle") — added command-boundary stalls Stage 1's proven single-command active line doesn't
have, breaking the constant per-line duration a monitor needs to lock horizontal sync to.
**Fixed by restructuring to exactly match Stage 1's single-command shape** — one
`HSTX_CMD_TMDS|640` per row, with the black pillarbox/mask fill sourced as plain DMA *data*
(not separate commands) under that same command's word budget. Confirmed on the monitor: a
correctly pillarboxed, circular-masked, coloured circle (some pixel-level edge stepping,
expected from 2px horizontal quantisation for word-aligned DMA reads — not a bug), stable.
Full writeup in `firmware/phase0-dvi2/README.md`.

**Colour channel rotation — root-caused and fixed at the source (30/08/26).** Not a simple
lane swap: the `expand_tmds` values both stages copied from Adafruit's PicoDVI driver assumed
the wrong TMDS lane order (L0=Red — the real DVI/HDMI convention is L0=Blue, L1=Green,
L2=Red, not alphabetical) *and* didn't decode to a clean bit-field under RP2350's own
documented `ROT`/`NBITS` register semantics for this project's actual RGB565 packing.
Recomputed from scratch (`ROT = (channel_MSB_bit_index − 7) mod 32`, derived from pico-sdk's
own register header docs) and validated against `raspberrypi/pico-examples`' own RGB332
sample before trusting it — confirmed correct on real hardware in
`firmware/phase0-dvi-colorfix/` (built for a Metro RP2350; the fix is pure register-level
TMDS math, board-independent) and backported unchanged into both `phase0-dvi/` and
`phase0-dvi2/`, replacing their empirical compensation tables with the true RGB565 values.
Both rebuild cleanly; Stage 2 not yet re-flashed on the physical Feather to visually
re-confirm (only the Metro was connected this session) — expected to be a formality given no
board-specific mechanism remains in the fix, but genuinely outstanding.

**A2. Pin-map validation.** Bring up §4.1's allocation on real RP2350A silicon: SPI0 as
slave, SPI1 on `{8,9,10,11}`, I2C0 as target, I2C1 for Qwiic, DDC on PIO. §4.1's GPIO0–29
peripheral assignments are identical between RP2350A and RP2350B (only GPIO30–47 differ),
so this test doesn't require RP2350A-specific silicon — the **Metro is used for A2**, not
the Feather; the Feather's own GPIO21 (needed for SPI0 CS) isn't broken out on that board at
all (internal-only, dedicated to its onboard NeoPixel), while the Metro exposes all four
SPI0 pins (GPIO20/21/22/23) on labelled headers. The Feather was the board originally used
for A1/A3 (HSTX DVI) — **the Metro can do HSTX DVI too, corrected 30/08/26**: it has its
own dedicated 22-pin HSTX connector breaking out GPIO12–19 (D0P/D0N/D1P/D1N/D2P/D2N/CKP/CKN,
confirmed from Adafruit's own Metro RP2350 pinout page), the identical silicon-fixed mapping
the Feather uses (HSTX bit index `n` is always GPIO `12+n`, regardless of RP2350A/B package)
— used in practice for the A1 colour-rotation root-cause fix (`firmware/phase0-dvi-colorfix/`)
when only the Metro was connected. The Feather remains the board A1/A3's own firmware
(`phase0-dvi`, `phase0-dvi2`) targets by default, not because the Metro is incapable.

**In progress (30/08/26).** Wiring the official `emfcamp/badge-2024-hardware/hexpansion`
devkit board for this test surfaced and settled risk 19 (§9) — §4.1's SPI0/GPIO20–23 role
table didn't match RP2350 silicon; corrected, and the `HS_F/G/H/I` role assignment (which
turned out to be this project's own free choice, not a badge-side constraint) is now
decided. Also confirmed and fixed a real error in §1.1's edge connector pad table (pads
4–10 were shifted by 3 positions) while cross-checking the devkit against the badge's own
KiCad source, and found the board-choice issue above (Feather → Metro) while checking pin
accessibility. On the Metro, I2C0's exact pins (GPIO24/25) also aren't cleanly accessible
(GPIO24 isn't broken out; GPIO25 is the onboard NeoPixel) — for this bench test only,
I2C0 uses GPIO4/5 instead (both freely available, no onboard conflicts); §4.1's GPIO24/25
assignment is unchanged for the real product, which has no such constraint. LS_E
(GPIO29) is left unwired on the Metro — that pin doubles as the board's USB-A host power
enable, an unwanted side effect for a "spare" signal with no bearing on the actual test.
Physically wired and **I2C0-target half confirmed working** — see C4 below, same firmware
and wiring session. **SPI0-slave half also confirmed working (30/08/26)**, mode 3
(CPOL=1, CPHA=1), CS held low for the whole burst: badge and RP2350 exchange known test
patterns cleanly in both directions. The first attempts failed regardless of SPI mode —
root-caused to a single bad physical connection on the CS wire (bench dupont wiring), found
by comparing GPIO edge counts across all four SPI0 pins during a live badge-driven transfer;
CS showed zero edges while SCK/MOSI showed clean, correctly-counted activity over the same
wiring pass. Fixed by rewiring that one connection. Full diagnostic writeup and the C3 speed
sweep below in `firmware/phase0-a2-spi/README.md`.

**A3. 640×480 @60 DVI output — done.** Confirmed on a real monitor (Stage 1 and Stage 2
both, `firmware/phase0-dvi/` and `firmware/phase0-dvi2/`) — §3.3's 84%-of-HSTX-rating
estimate holds in practice, once `clk_sys` is correctly set to 126 MHz (see A1 above).

**A4. Current draw under load — cannot happen on this bench rig at all, same reason as C4
(30/08/26).** Not just "not yet measured": this rig's boards run off USB with their own
onboard regulators, not the product's own power architecture (buck/boost/TPS2116 mux,
§4.5), and — like C4 — there is no badge-supplied `3V3_BADGE` in the loop at all (badge
`+3V3` deliberately left disconnected, no isolation circuit to safely tie two live rails).
So there's no representative rail to put a meter on for §4.7's badge-port-budget rows, and a
USB-side reading on the dev board would be measuring the dev board's own support circuitry
overhead as much as the RP2350/HSTX load the budget actually cares about — not a number
that transfers to the product. Moves to Phase 2 alongside C4 and the backfeed check, same
underlying cause: this bench rig's power topology isn't the product's.

**A5. Optional: the pillarbox bezel** (§3.4), and Qwiic + SWD bring-up.

#### Part B — Metro, the PSRAM and SD bench

**B1. ctx rasterisation at 640×480 — the highest-value single measurement. Done**, on real
Metro RP2350 hardware (`firmware/phase0-metro/`, hand-built scenes rather than a drawlist
captured from a real app — Part C, capturing one, hasn't happened yet). **Result: 2.9 fps
typical scene, 0.7 fps worst case — too slow for animation.** Decomposed against a raw
PSRAM-write floor and ctx's own cheapest-possible draw call to find out why (§3.2 has the
full numbers and what they mean for the advanced path). Settles risk 17. A 614 KB 16 bpp
target does not fit in 520 KB of SRAM, which is why this needed the Metro's PSRAM.

*Alternative on the Feather:* rasterise at **8 bpp palette** — 307 KB, fits in SRAM, and is
already a listed mode in §3.3, so the number is directly useful rather than a proxy.

**B2. microSD** on SPI — **done**, on the Metro (`firmware/phase0-metro/`): mount,
capacity report, and a write/read-back correctness test all pass on real hardware
(FAT32, via `carlk3/no-OS-FatFS-SD-SDIO-SPI-RPi-Pico` + FatFs, not a hand-rolled SD-SPI
driver). **PSRAM-backed 640×480 16 bpp scanout — done, measured short.** DMA-driven reads
out of PSRAM (simulating HSTX scanout) reach ~27.1 MB/s against a 35.8 MB/s theoretical
ceiling at the stock `clk_sys` 150 MHz (75 MHz PSRAM clock, the fastest divisor available
at that `clk_sys`) — short of the ~35-37 MB/s continuous 640×480@60 16bpp scanout actually
needs, and no config change at that clock closes the gap. Full writeup in §3.3.

**B3. The RP2350B experiment — accepted as inconclusive, closed (30/08/26).** This Feather
doesn't have PSRAM populated (ships DNP), so B1/B2 couldn't run a comparison against the
Metro's numbers on this specific board; both skip cleanly, confirming toolchain/board
bring-up on RP2350A silicon but nothing about RP2350A vs. RP2350B PSRAM/ctx performance.
**Decision: not populating the DNP footprint** — the ~$1.15 APS6404L and the soldering
aren't worth it for a comparison this project doesn't need: the A map (§4.1) is already the
plan, the B is only ever the documented fallback, and A2/A1/A3/A4 have all separately
confirmed the A map brings up cleanly on real RP2350A silicon (Metro/Feather bench tests).
Risk 18 (§9) stays open rather than closing via this path — its own mitigation (documented
pinmux option, not exotic) already covers it without needing this measurement.

A1 and B1 are the two highest-value tests and use different boards, so they run in parallel.

#### Part C — badge required

**C1. `display.get_fps()` across a handful of real apps — done.** Badge only, no hexpansion
needed. **Measured ~2.2-14.3 fps across 3 real installed apps** (GPS clock, sponsor logos,
map) — comfortably under the ~15 fps "link has enormous headroom" threshold, nowhere near
the ~40 fps dirty-rect threshold. Bounds the whole primary mode: confirmed the badge's own
render rate is the bottleneck, not the link. Full numbers and the `mpremote`
interrupt-vs-`resume` gotcha worked around to get them non-invasively are in §3.1.

**C2. Prototype `display.get_fb()` — patch written and reviewed, not yet compiled/flashed
(30/08/26).** The actual patch (`drivers/gc9a01/display.c` in a local
`emfcamp/badge-2024-software` clone): a `get_fb()` MicroPython function returning
`mp_obj_new_memoryview(BYTEARRAY_TYPECODE, sizeof(tildagon_fb), tildagon_fb)` — a zero-copy
view onto the same `tildagon_fb` §3.1 already describes, registered alongside `get_ctx()` in
the `display` module table. This is not a new pattern: `mp_uctx.c`'s own
`mp_ctx_set_pixels()` already does the identical `mp_obj_new_memoryview(BYTEARRAY_TYPECODE,
...)` call for the same purpose (handing pixel-buffer bytes to MicroPython), just from a C
callback instead of a direct binding — confirmed against the vendored `micropython` submodule
headers (`py/obj.h`, `py/binary.h`) that the signature and `BYTEARRAY_TYPECODE` constant are
exactly what's used.

**Blocked on compiling/flashing it, by a pre-existing build-toolchain issue, not the patch
itself.** Following the repo's own documented Docker build path
(`ghcr.io/emfcamp/esp_idf:v5.5.1`, their own CI's exact image) fails during MicroPython's
qstr-scan step with `ctx_config.h: No such file or directory` compiling `display.c` and
`mp_uctx.c` — a transitive-include-propagation gap (the failing preprocessor invocation's
assembled `-I` list includes `st3m`'s own include dir but not `ctx`'s, a dependency *of*
st3m, even though `st3m`'s `CMakeLists.txt` correctly declares `REQUIRES ... ctx ...`).
**Confirmed unrelated to this patch**: reproduces identically (a) with the patch fully
reverted against unmodified upstream `display.c`, and (b) on both the tip of `main` and the
latest tagged release `v2.2.0`. A direct workaround (adding `ctx`'s include dir straight to
the `usermod_display` CMake target) had no effect on the assembled command line at all,
showing the qstr-scan include list isn't sourced from that target's own properties —
diagnosing the real mechanism would mean reading MicroPython's ESP32-port build scripts in
depth, a separate task from this patch. Also noted in passing: the repo's own committed
component lockfile (`micropython/ports/esp32/lockfiles/dependencies.lock.esp32s3`) is
missing an `espressif/nghttp` entry that `components/tildagon/idf_component.yml` itself
declares as a dependency — real drift, but a red herring for this specific failure (CMake
only warns about it, doesn't fail the build on it).

**Net effect: the code change is ready and matches an already-proven pattern in the same
file; it just hasn't been proven to compile in this environment.** Treat it as reviewed, not
verified — flashing and testing `get_fb()` live on the badge needs either a working local
ESP-IDF/component-manager combination for this repo, or raising the upstream ask (§3.1) and
letting EMF's own CI build it.

**C3. SPI link speed — done for the bench-wiring case (30/08/26).** Rig: the official
`emfcamp/badge-2024-hardware/hexpansion` devkit board plugged into the real badge port (so
the actual edge connector **is** in circuit), with dupont jumpers only for the last leg from
that devkit board's headers to the Metro. Swept 100 kHz–40 MHz: **100 kHz–20 MHz fully
reliable**; 30/40 MHz show genuine bit errors, consistent with §1.2's ~40 MHz ceiling on the
badge's matrix-routed HS pins. Pushed a real 115,200-byte frame (the badge's actual
mirrored-framebuffer size) at both 10 and 20 MHz: **0 mismatches both directions at both
rates**, wire time within 2–4% of the clock-rate theoretical minimum (98.4% efficiency at
10 MHz, 96.7% at 20 MHz) — **10.7 fps and 21.0 fps full-frame-equivalent**, both well inside
C1's budget (worst real app measured: 14.3 fps, ~70 ms/frame). Full numbers, including a
debugged false-failure (a fixed, repeatable corrupted-first-transaction artifact on the
badge's own ESP32-S3 SPI master, not a link problem) and a bogus RP2350-side timing number
explained, in `firmware/phase0-a2-spi/README.md`. **Still open: re-run once the dupont leg
is gone** (product PCB, no devkit-to-Metro wire at all) and confirm 30/40 MHz clean up on a
real trace before relying on them.

**C4. EEPROM emulation enumerates reliably.** Cold-plug 50 times. Measure worst-case time
from port power-on to the badge's first I2C read against the RP2350's time-to-I2C-ready. If
there is no clear daylight, §5's fallback becomes the primary plan and the schematic changes.

**First success confirmed (30/08/26, `firmware/phase0-a2-eeprom/`).** On real hardware:
badge found the emulated EEPROM, read the header, and continued reading past byte 32 into
the (currently empty) filesystem region — meaning the header's magic/version/checksum all
validated, since a failed check would have stopped the badge there. No race observed with
the I2C target started as literally the first line of `main()`. Settles risk 1 (§9) as
proven in principle.

**The formal 50×-cold-plug run moves to Phase 2, not "outstanding in Phase 0."** This bench
rig's Metro is USB-powered with badge `+3V3` deliberately left unconnected (no isolation
circuit exists to safely tie two live 3.3V rails together), so unplugging/replugging the
hexpansion never actually power-cycles the RP2350 — it stays running throughout, which
defeats the point of a *cold*-plug timing measurement. Needs either the real product
(RP2350 powered from the hexpansion's own badge-supplied +3V3) or a bench modification that
genuinely power-cycles the RP2350 with isolation from USB — neither fits a Phase 0 bench
check. Full note in `firmware/phase0-a2-eeprom/README.md`.

#### What the bench cannot tell you

* **PSRAM on an RP2350A** — see above; populating the Feather's footprint closes this.
* **Signal integrity.** Adafruit's adapter has its own buffering; our board direct-drives
  from GPIO. Functional results transfer, SI results do not.
* **The backfeed test (§4.5)** needs the real power topology and moves to Phase 2.
* **C4's cold-plug timing.** The bench Metro is USB-powered, not badge-powered, so
  unplugging/replugging never power-cycles the RP2350 — moves to Phase 2 alongside the
  backfeed check, same reason (needs the real power topology).
* **A4's current draw under load.** Same reason again: the bench boards run off USB through
  their own onboard regulators, not the product's buck/boost/mux chain, and have no
  badge-supplied rail in the loop either — no representative rail exists here to measure.
  Moves to Phase 2 with the other two.
* **The layout.** No bench board answers whether the outer flat closes (§4.4).

Everything downstream is cheap to change now and expensive to change later. Do not skip
this phase.

#### Beyond Phase 0: the first end-to-end link demonstration

**Done (30/08/26), `firmware/testcard/`.** With VID/PID assigned, built the first firmware
combining every proven Phase 0 piece into one image and one demonstration: badge inserts a
hexpansion → discovers the emulated EEPROM with the real identity (I2C0, A2/C4's proven
mechanics) → mounts a real LittleFS filesystem living inside it → auto-launches the packed
badge-side app → that app sends commands over the proven SPI0 link (A2/C3) → the RP2350
applies them and the monitor changes over HDMI (A1/A3, colour-correct). **Confirmed working
end to end on real hardware, first attempt** — exact VID/PID, exact computed LittleFS block
count, a real mounted filesystem with a real app, and all 4 test patterns visibly cycling on
the monitor in step with badge-side commands.

This isn't a Phase 0 deliverable — it's the first proof that the individually-validated
pieces actually compose into the product's real contract, done early because the last
blocking dependency (VID/PID) cleared.

**Upgraded (31/08/26).** The badge now generates the displayed content itself — a
240×240 frame built in Python, streamed continuously over SPI0 one row at a time — instead
of just selecting among a handful of RP2350-fixed patterns, exercising the link the way the
actual mirroring product will, not just its command plumbing. Also added: a NeoPixel
heartbeat (red 1Hz when idle, green flash per completed frame) and RP2350-generated
analog-TV-style static shown at boot/no-signal. Getting reliable continuous streaming
surfaced a real bug worth knowing about for the eventual product SPI0 driver too: on this
board/SDK, `gpio_get()` does not reflect a pin's real level while it's configured
`GPIO_FUNC_SPI` — CS-edge detection has to happen some other way (here, by treating the RX
FIFO as an already-row-aligned continuous stream instead). Two more real-hardware findings —
CPU writes to the scanout buffer needing to be gated against the DMA's current read position,
and a smaller staged-frame buffer standing in for a full second framebuffer that didn't fit
in SRAM — are also now proven, reusable techniques for the real product's own scanout path.
Full writeup, including all three fixes in detail, in `firmware/testcard/README.md`.

### Phase 1 — Schematic + layout (3–4 weeks part-time)

Start from `emfcamp/badge-2024-hardware/hexpansion` so the outline, tab, and mounting
holes are right by construction. 4-layer stackup: L1 signal/TMDS, L2 solid GND, L3
power, L4 signal. Length-match TMDS pairs, keep them on L1 over the L2 ground plane, and
keep the runs under ~30 mm (which the board size makes easy).

**Do the flat-allocation placement study first** (§4.4) — the outer flat carries
mini-HDMI plus USB-C at 25.5 mm on a 25.4 mm flat, so connector placement, not routing,
is what decides whether this board closes. If it does not, either drop microSD and move
USB-C to a side flat, or switch to the radial wedge outline. Request VID/PID **and open the `display.get_fb()` conversation upstream** in week 1 —
both are short work on someone else's schedule.

### Phase 2 — Prototype run (5 boards, ~2 weeks lead time)

First thing on arrival, the **backfeed check** that Phase 0 could not do: with the badge
powered off and USB-C live, measure the current into pads 15/16 and the voltage on the
badge's `3V3_SYS` — both must read zero. Repeat with the badge on and the port disabled in
software. This is the test that proves §4.5, and it is worth building a jig for.

Also **C4's 50×-cold-plug enumeration timing** (§8 Part C) — the bench Metro's USB power
meant unplugging the hexpansion never actually power-cycled the RP2350, so this measurement
was impossible in Phase 0. The real board is badge-powered, so this becomes straightforward
once boards exist: cold-plug 50 times, time port power-on to the badge's first I2C read.

And **A4's current-draw-under-load measurement** (§8 Part A) — same cause, the bench boards'
USB power and onboard regulators aren't the product's power architecture. Once boards exist,
measure against §4.7's actual budget rows: badge-port draw with the port switched on in
software, boost/`V5_HDMI` draw with an HDMI sink attached, and Qwiic-device draw — the rows
Phase 0 flagged as uncheckable from the start, now joined by the RP2350/HSTX/TMDS rows too.

### Phase 3 — Firmware (4–6 weeks part-time)

Pico SDK in C. Order of work: badge-presence sense and tri-state-by-default on MISO/LS_B
(this comes first — it is a safety interlock, not a feature) → boot + flash/PSRAM bring-up → I2C target and EEPROM
emulation → HSTX DVI output → SPI slave with DMA (PIO-based, so clock-stretch and
back-pressure are under our control) → the mirror path (receive frame, pixel-double,
mask, present) → the drawing engine → PIO-I2C DDC/EDID and mode negotiation → Qwiic bus and the I2C bridge commands → microSD → HDMI audio if time allows.

### Phase 4 — Badge-side driver and the upstream patch (1–2 weeks)

Two deliverables. **A PR to `badge-2024-software`** exposing `tildagon_fb` as
`display.get_fb()` — prototyped back in Phase 0, so this is submitting tested work rather
than asking for a feature. And the **mirror app**: read the buffer after each
`end_frame`, push it over SPI, done. Baked into the LittleFS image the fake EEPROM serves,
plus a companion app in this repo's index so people can install it without owning the
hardware yet.

The display-list driver is a later, separate piece of work — nothing depends on it for the
primary mode.

### Phase 5 — Production run (10/20/50 per §7)

---

## 9. Risk register

| # | Risk | Severity | Mitigation |
|--:|---|---|---|
| 1 | EEPROM emulation loses the enumeration race at power-on | Low (was High) | **Proven in Phase 0 C4, on real hardware.** Badge found and successfully read the header (validated — it kept reading past byte 32, which a failed checksum/magic would have stopped) with no race observed. Fast-boot I2C target (started before `stdio`/USB/anything else) worked as intended. DNP 24C64 fallback footprint remains as insurance but is no longer load-bearing for this specific risk. |
| 2 | Outer flat does not close — 25.5 mm of connectors on a 25.4 mm flat | **High** | Placement study is the first task in Phase 1. Fallbacks in order: drop microSD and move USB-C to a side flat; then the radial wedge outline (§4.4). |
| 3 | USB backfeed reaches the badge's 3V3 rail | **High** | TPS2116 priority mux with reverse blocking on both inputs; `VBUS` confined to the USB domain; HDMI 5 V never muxed with `VBUS`. Proven on the first prototype boards in Phase 2 — the Metro cannot exercise the real power topology. |
| 4 | **`display.get_fb()` never lands upstream**, so nothing can read the badge framebuffer | **High** | Ask in week 1 with a tested patch from Phase 0; it is ~10 lines of C at a single choke point. If it is refused, the product falls back to display-list mode only — still a working graphics card, but it loses the "every app for free" property that makes mirroring the headline. Do not discover this late. |
| 5 | Phantom-powering the badge through signal pins | Medium | Only MISO and LS_B can source; both firmware tri-stated until the badge-presence sense reads live; 33 Ω series on the HS lines. |
| 6 | Buck fails short, putting 5 V on `3V3_LOCAL` | Medium | The mux's reverse blocking keeps it off the badge. On-board damage is accepted; add a 3.6 V clamp on `3V3_LOCAL` if the layout leaves room. |
| 7 | 600 mA budget or inrush trips the port switch | Medium | Modest bulk capacitance, staged boost enable. Steady-state draw is measured on the Metro in Phase 0 A4; inrush against the badge's port switch waits for Phase 2. Qwiic devices documented as sharing ~100 mA of headroom. |
| 8 | Mini-HDMI wired as if it were Type A | Medium | Different pin assignment; netlist from the connector datasheet, and check it at review. |
| 9 | Neighbouring hexpansion sits 4.1 mm away, blocking side-flat cables | Medium | Fat-cable connectors are all on the outer flat by design; Qwiic and SD documented as needing the adjacent bay free. |
| 10 | Cable strain on the edge connector — worse on an 89% larger board | Medium | Both M2 mounting holes populated; strain-relief loop documented for users. Mini-HDMI reduces leverage but has lower retention force than Type A. |
| 11 | Badge battery life halves when the card runs on badge power | Medium | USB-C input with the TPS2116 mux — on USB the badge supplies nothing at all. |
| 12 | Badge renders too slowly for mirroring to look good | Low | Inherent: you see what the badge draws, and no link speed changes that. **Measured (Phase 0 C1): ~2.2-14.3 fps across 3 real apps** — inherently modest, not a link/hexpansion problem to solve. Document the expectation rather than engineering against it. |
| 13 | SPI link slower than 40 MHz in practice | Low | Mirroring needs 115 KB/frame and is bounded by the badge anyway; the display-list path already assumes 2.5 MB/s. |
| 14 | TMDS signal integrity on a 1.0 mm 4-layer board | Low | Short runs, controlled impedance, proven direct-drive topology. |
| 15 | VID/PID not assigned in time | Low | **Settled (30/08/26): assigned, `0x1969`/`0x4544`.** In use in `firmware/testcard/`, confirmed on real hardware. |
| 16 | RP2350-E9 pull-down erratum bites on LS/CS/I2C lines | Low | External pull resistors everywhere it matters. |
| 17 | ctx drawlist forwarding proves impractical — second firmware hook refused, or 640×480 rasterisation too slow on RP2350 | Medium (raised from Low) | **Settled by Phase 0 B1, on the Metro: rasterisation is too slow for animation** (2.9 fps typical scene, 0.7 fps worst case; ~40% of even the cheapest frame is PSRAM write bandwidth, not ctx itself — see §3.2). Affects the advanced path only; v1 mirroring depends on none of it. Occasional full-redraws of static content may still be viable; continuous/animated drawlist forwarding is not. Fallback is the bespoke command set in §3.2, which is already specified. |
| 18 | PSRAM CS on GPIO0 (QMI CS1, RP2350A) is unvalidated — the Feather has no PSRAM, the Metro is a B with CS on GPIO47 | Low | Documented pinmux option, not exotic. **Stays open through Phase 0** — Phase 0 B3 (§8) decided against populating the Feather's DNP PSRAM footprint to close this measurement (not worth the cost for a documented, non-exotic pinmux option); closes properly once Phase 1/2 schematic+prototype boards exist with the real RP2350A+PSRAM configuration. |
| 19 | §4.1's SPI0/GPIO20–23 role table (SCK/MOSI/MISO/CS in GPIO order) didn't match RP2350 silicon — found and corrected 30/08/26 while preparing to wire A2 | Low (settled) | **Settled.** GPIO↔SPI0-role verified against `RP2350.svd`; which badge `HS_x` carries which role turned out to be this project's own free choice (the badge's HS lines are matrix-routed on the ESP32-S3, confirmed by `DanNixon/ethernet-hexpansion` using a different mapping than originally assumed here) — §4.1 now states the chosen mapping (`HS_F`=MOSI, `HS_G`=CS, `HS_H`=SCK, `HS_I`=MISO), to be matched by badge-side driver code in Phase 3/4. |

---

## 10. Decisions taken

| Decision | Outcome |
|---|---|
| **Primary mode** | **Mirroring the badge's 240×240 screen**, pixel-doubled to 480×480 in 640×480. Display-list rendering becomes the advanced, opt-in path. |
| **Circular mask** | **On by default** — the monitor shows what the wearer sees. Runtime toggle reveals the full square for debugging. |
| Video connector | **Mini-HDMI Type C.** Cables are common (Pi Zero, most cameras), and on an 18.5–25.4 mm flat the 5 mm it saves over Type A is decisive. |
| USB-C | **In** — power, UF2, and a CDC console. |
| Debug | **3-pin JST-SH SWD** to the Raspberry Pi debug connector standard, so a Debug Probe plugs straight in. |
| Buttons | **BOOT and RESET**, both on the top face. |
| LEDs | **Power (always on) + status on GPIO1**, plus an optional SK6805 RGB. |
| Qwiic | **Two JST-SH 4-pin sockets in parallel** on hardware I2C1 (GPIO6/7), with jumper-removable 4k7 pull-ups. Both on side flat A. |
| Badge power | **The hexpansion never powers the badge** — not in normal use, not during hot-plug, not under a single-component failure. Enforced by the TPS2116 mux and firmware tri-stating, not by convention. |
| MCU variant | **RP2350A (QFN-60).** The B halves the pin pressure but doubles package area on a board with no slack, and adds no peripherals. Recorded as the fallback, not pursued further — Phase 0 B3 deliberately skipped populating the Feather's PSRAM footprint to run a direct A-vs-B comparison (§8), a decision made rather than an oversight, since A2/A1/A3/A4 already confirm the A map works on real silicon and the B was only ever the fallback. |
| Flash / MCU package (28/09/26) | **RP2354A** in place of RP2350A + W25Q128. It's the same die and QFN-60 pinout, so the §4.1 pin map is unchanged; the in-package 2 MB flash sits on QSPI CS0. That removes a SOIC-8 and its routing from a board with no slack. 2 MB is ample, since the largest firmware build is about 260 KB. The QSPI pins still come out of the package, so the PSRAM on CS1/GPIO0 works as planned, but an external flash on CS0 can't be added alongside the internal one. |
| PSRAM (28/09/26) | **APS6404L footprint kept, not assembled (DNP)**: hand-solder if wanted. Phase 0 B1/B2 (§3.2, §8) showed a PSRAM-backed framebuffer isn't needed for the mirror path. The 10k pull-up on CS1 stays fitted regardless, and firmware detects PSRAM at boot. |
| Board size | **44 mm across flats** (was the 32 mm template). Smallest size where mini-HDMI and USB-C fit on the outer flat. Costs ~$2/board. |
| microSD | **Back in**, on SPI1 GPIO8–11, on the second side flat. First thing to cut if the placement study fails. *(28/09/26: **dropped** from schematic v0.1. It frees the second side flat and GPIO5 and 8–11, and eases the space taken by the full-size HDMI socket.)* |

### Still open

* **Run size.** The fixed-cost curve in §7 says 50 if there is any chance of 50.
* **Whether the outer flat closes at 44 mm**, or the board wants the wedge outline. Decided by the placement study, not now.
* **Whether ctx drawlist forwarding is viable** — **measured (Phase 0 B1, §3.2): not for animation** (2.9 fps typical / 0.7 fps worst case). Occasional static-content redraws still plausible; not settled. LGPL-3.0+ review still outstanding. Not on the v1 path.
* **Whether microSD earns its place.** 16 MB of flash plus USB-C asset loading may make it redundant. *(28/09/26: flash is now 2 MB with the RP2354A, which strengthens the case for keeping microSD if assets are ever needed.)* **Resolved 28/09/26: dropped.** Mirroring needs no storage.

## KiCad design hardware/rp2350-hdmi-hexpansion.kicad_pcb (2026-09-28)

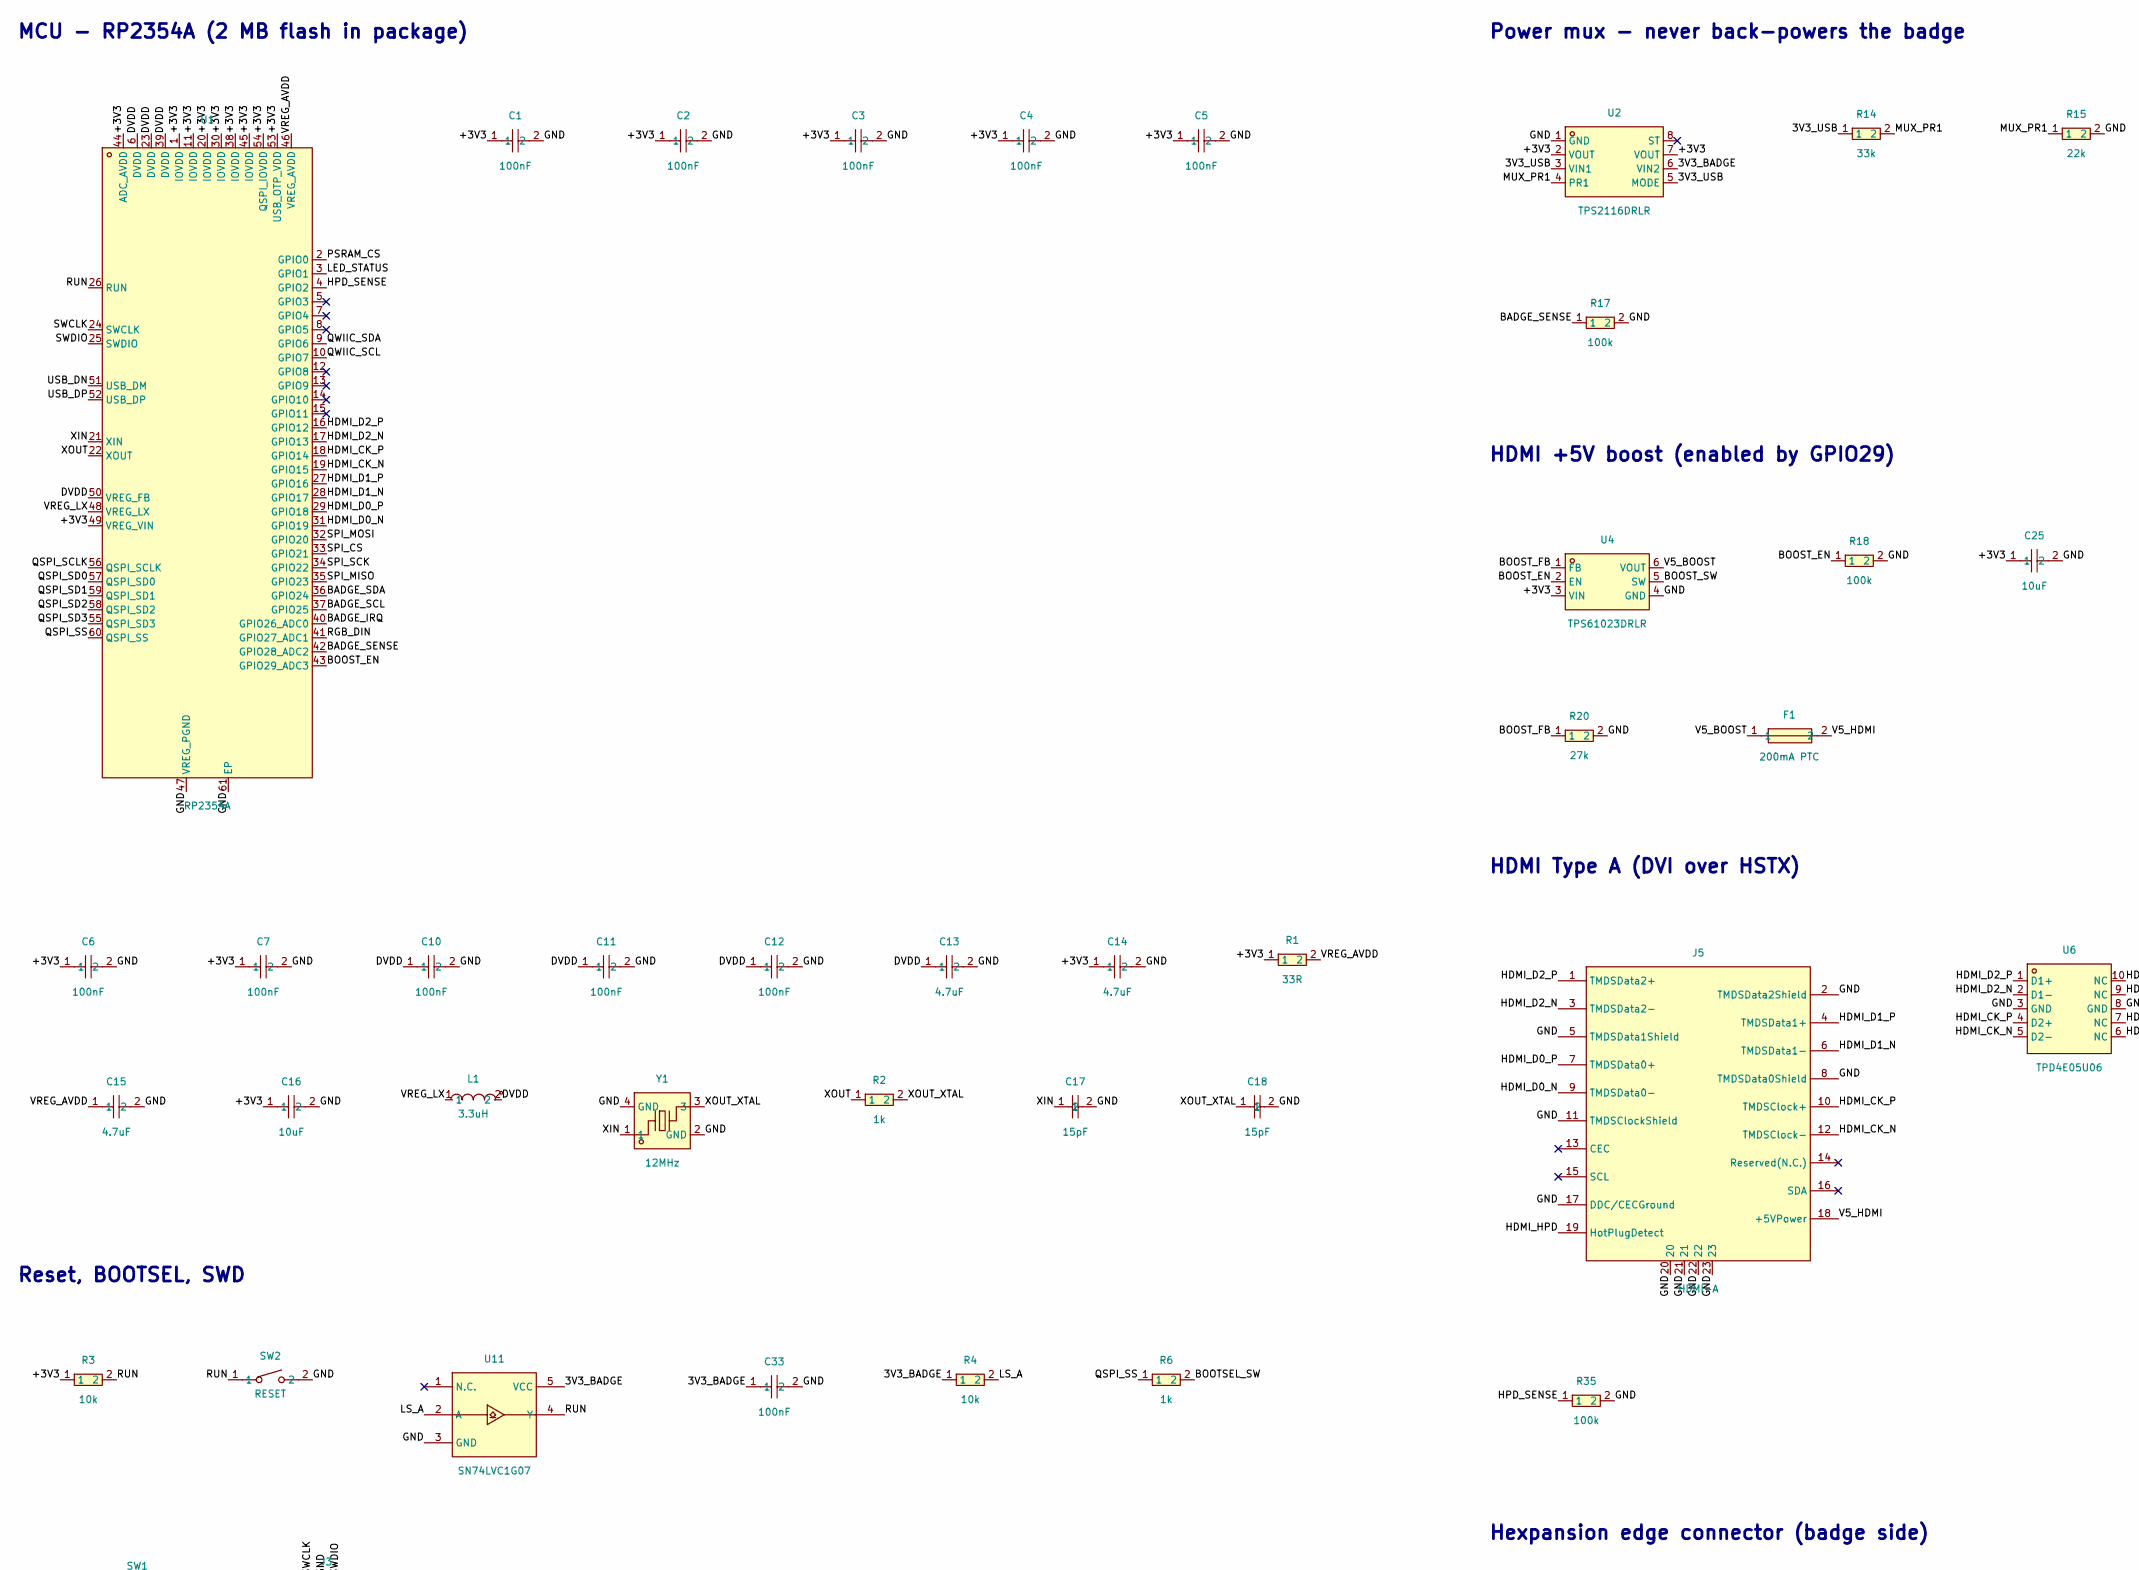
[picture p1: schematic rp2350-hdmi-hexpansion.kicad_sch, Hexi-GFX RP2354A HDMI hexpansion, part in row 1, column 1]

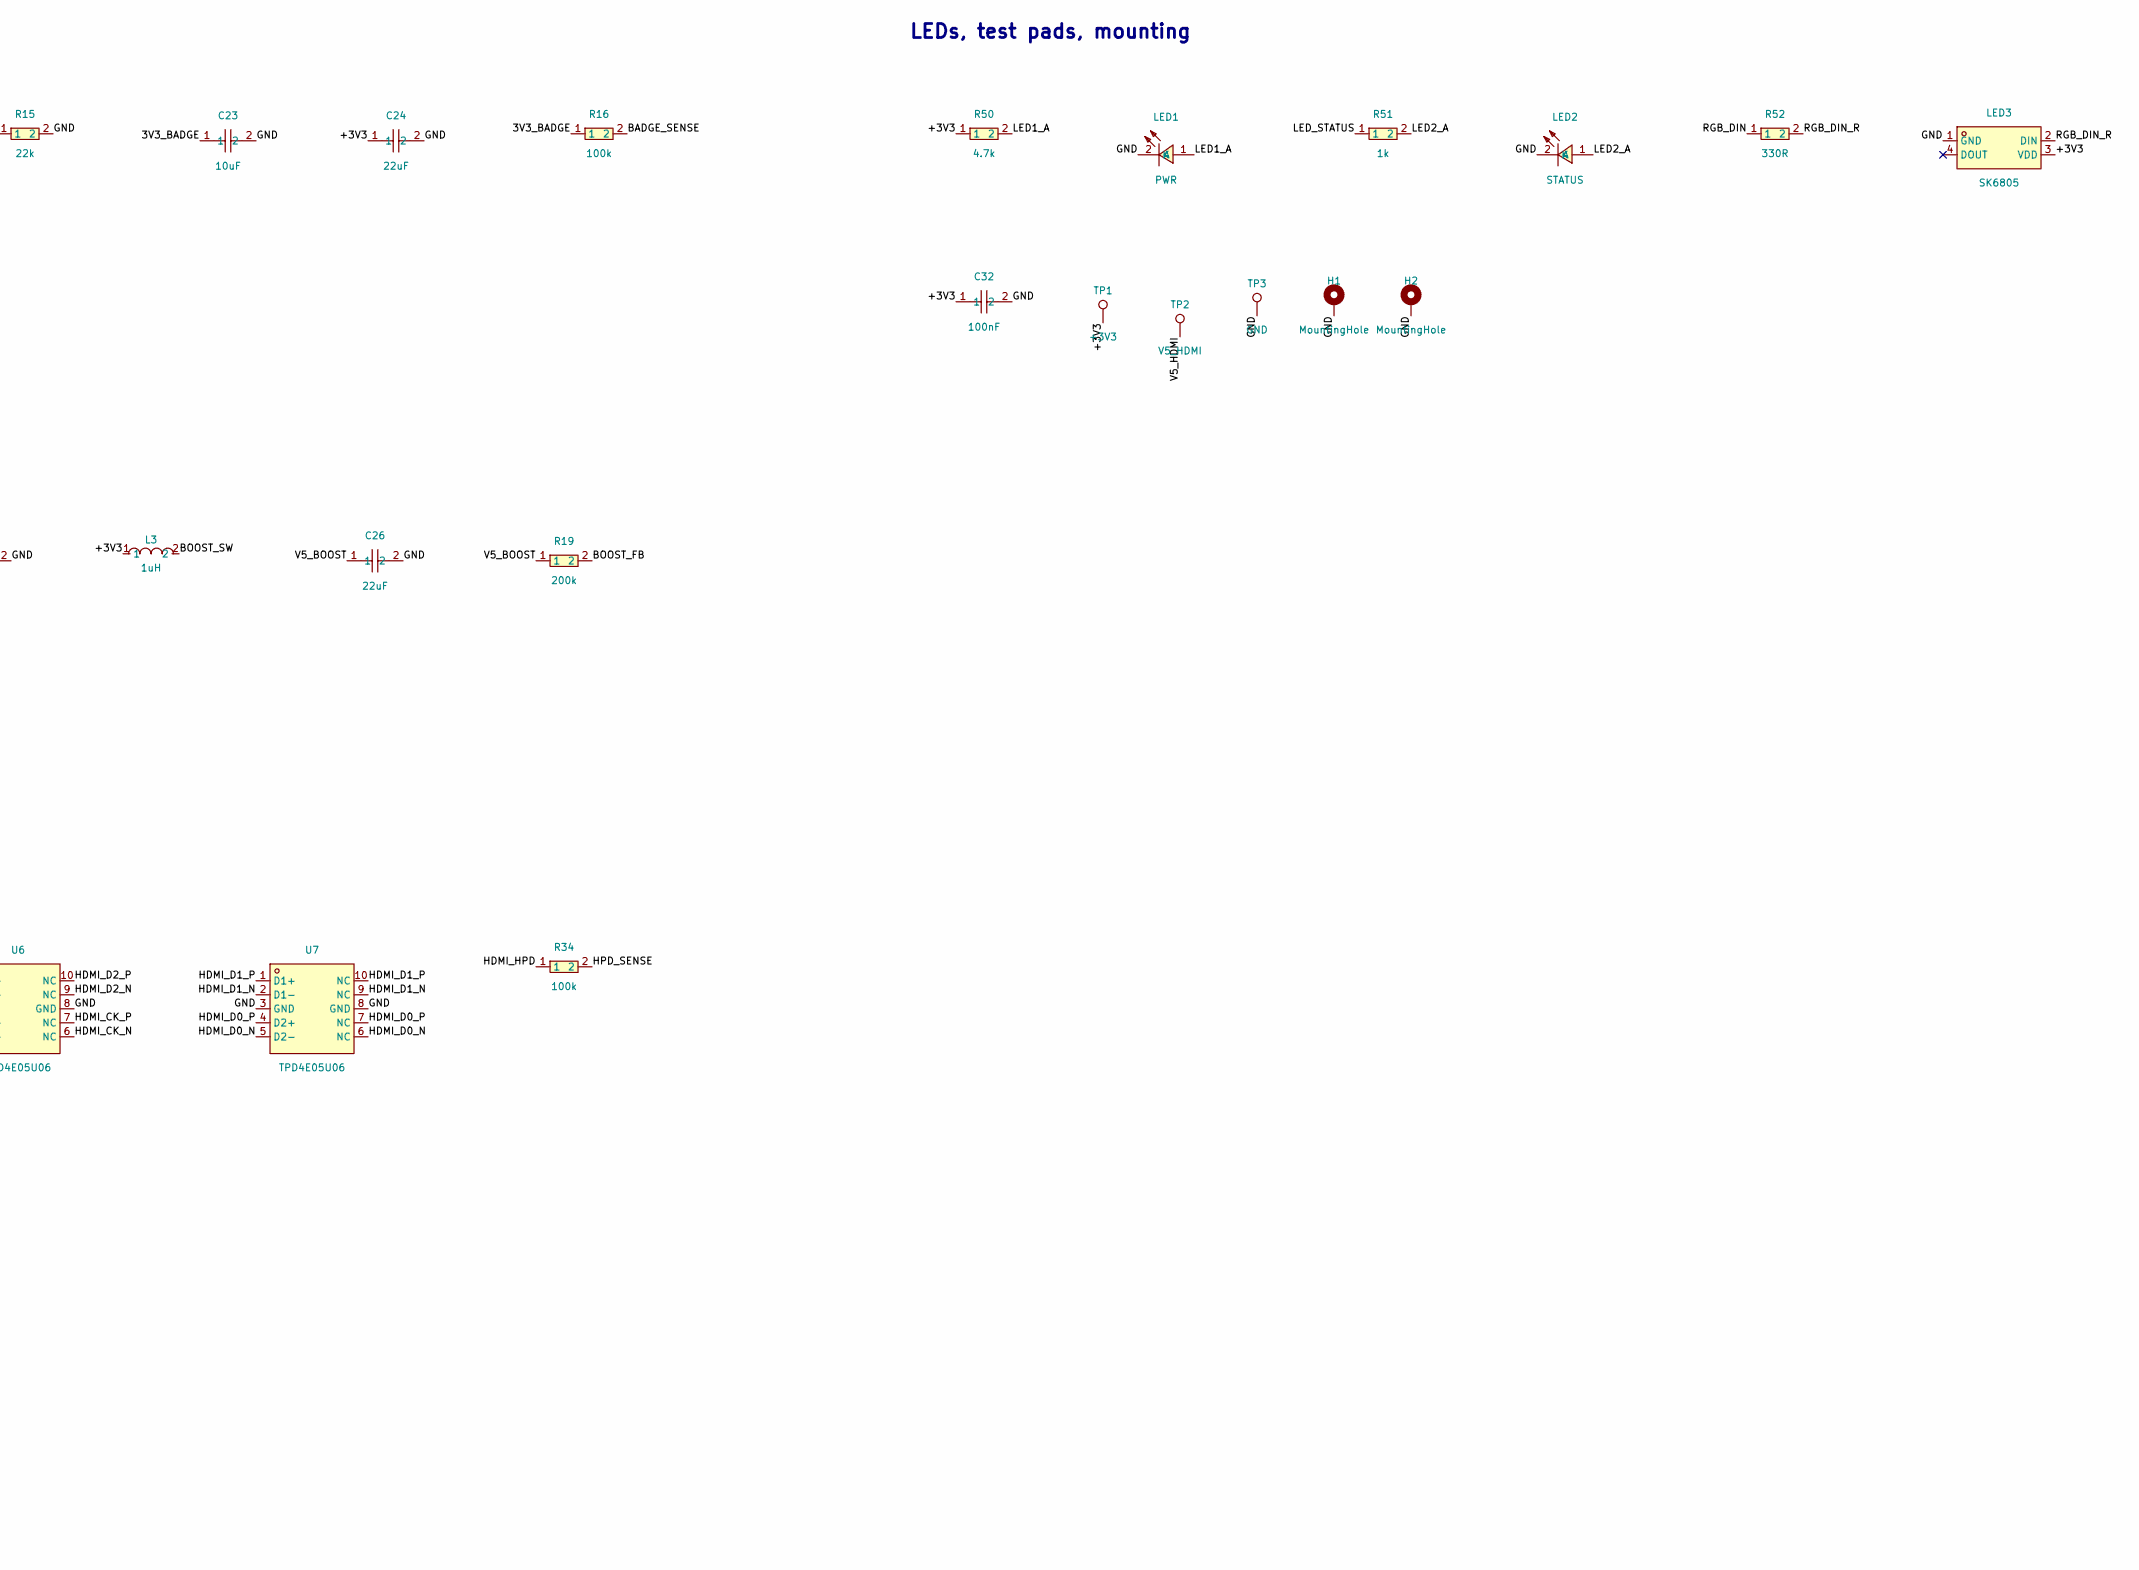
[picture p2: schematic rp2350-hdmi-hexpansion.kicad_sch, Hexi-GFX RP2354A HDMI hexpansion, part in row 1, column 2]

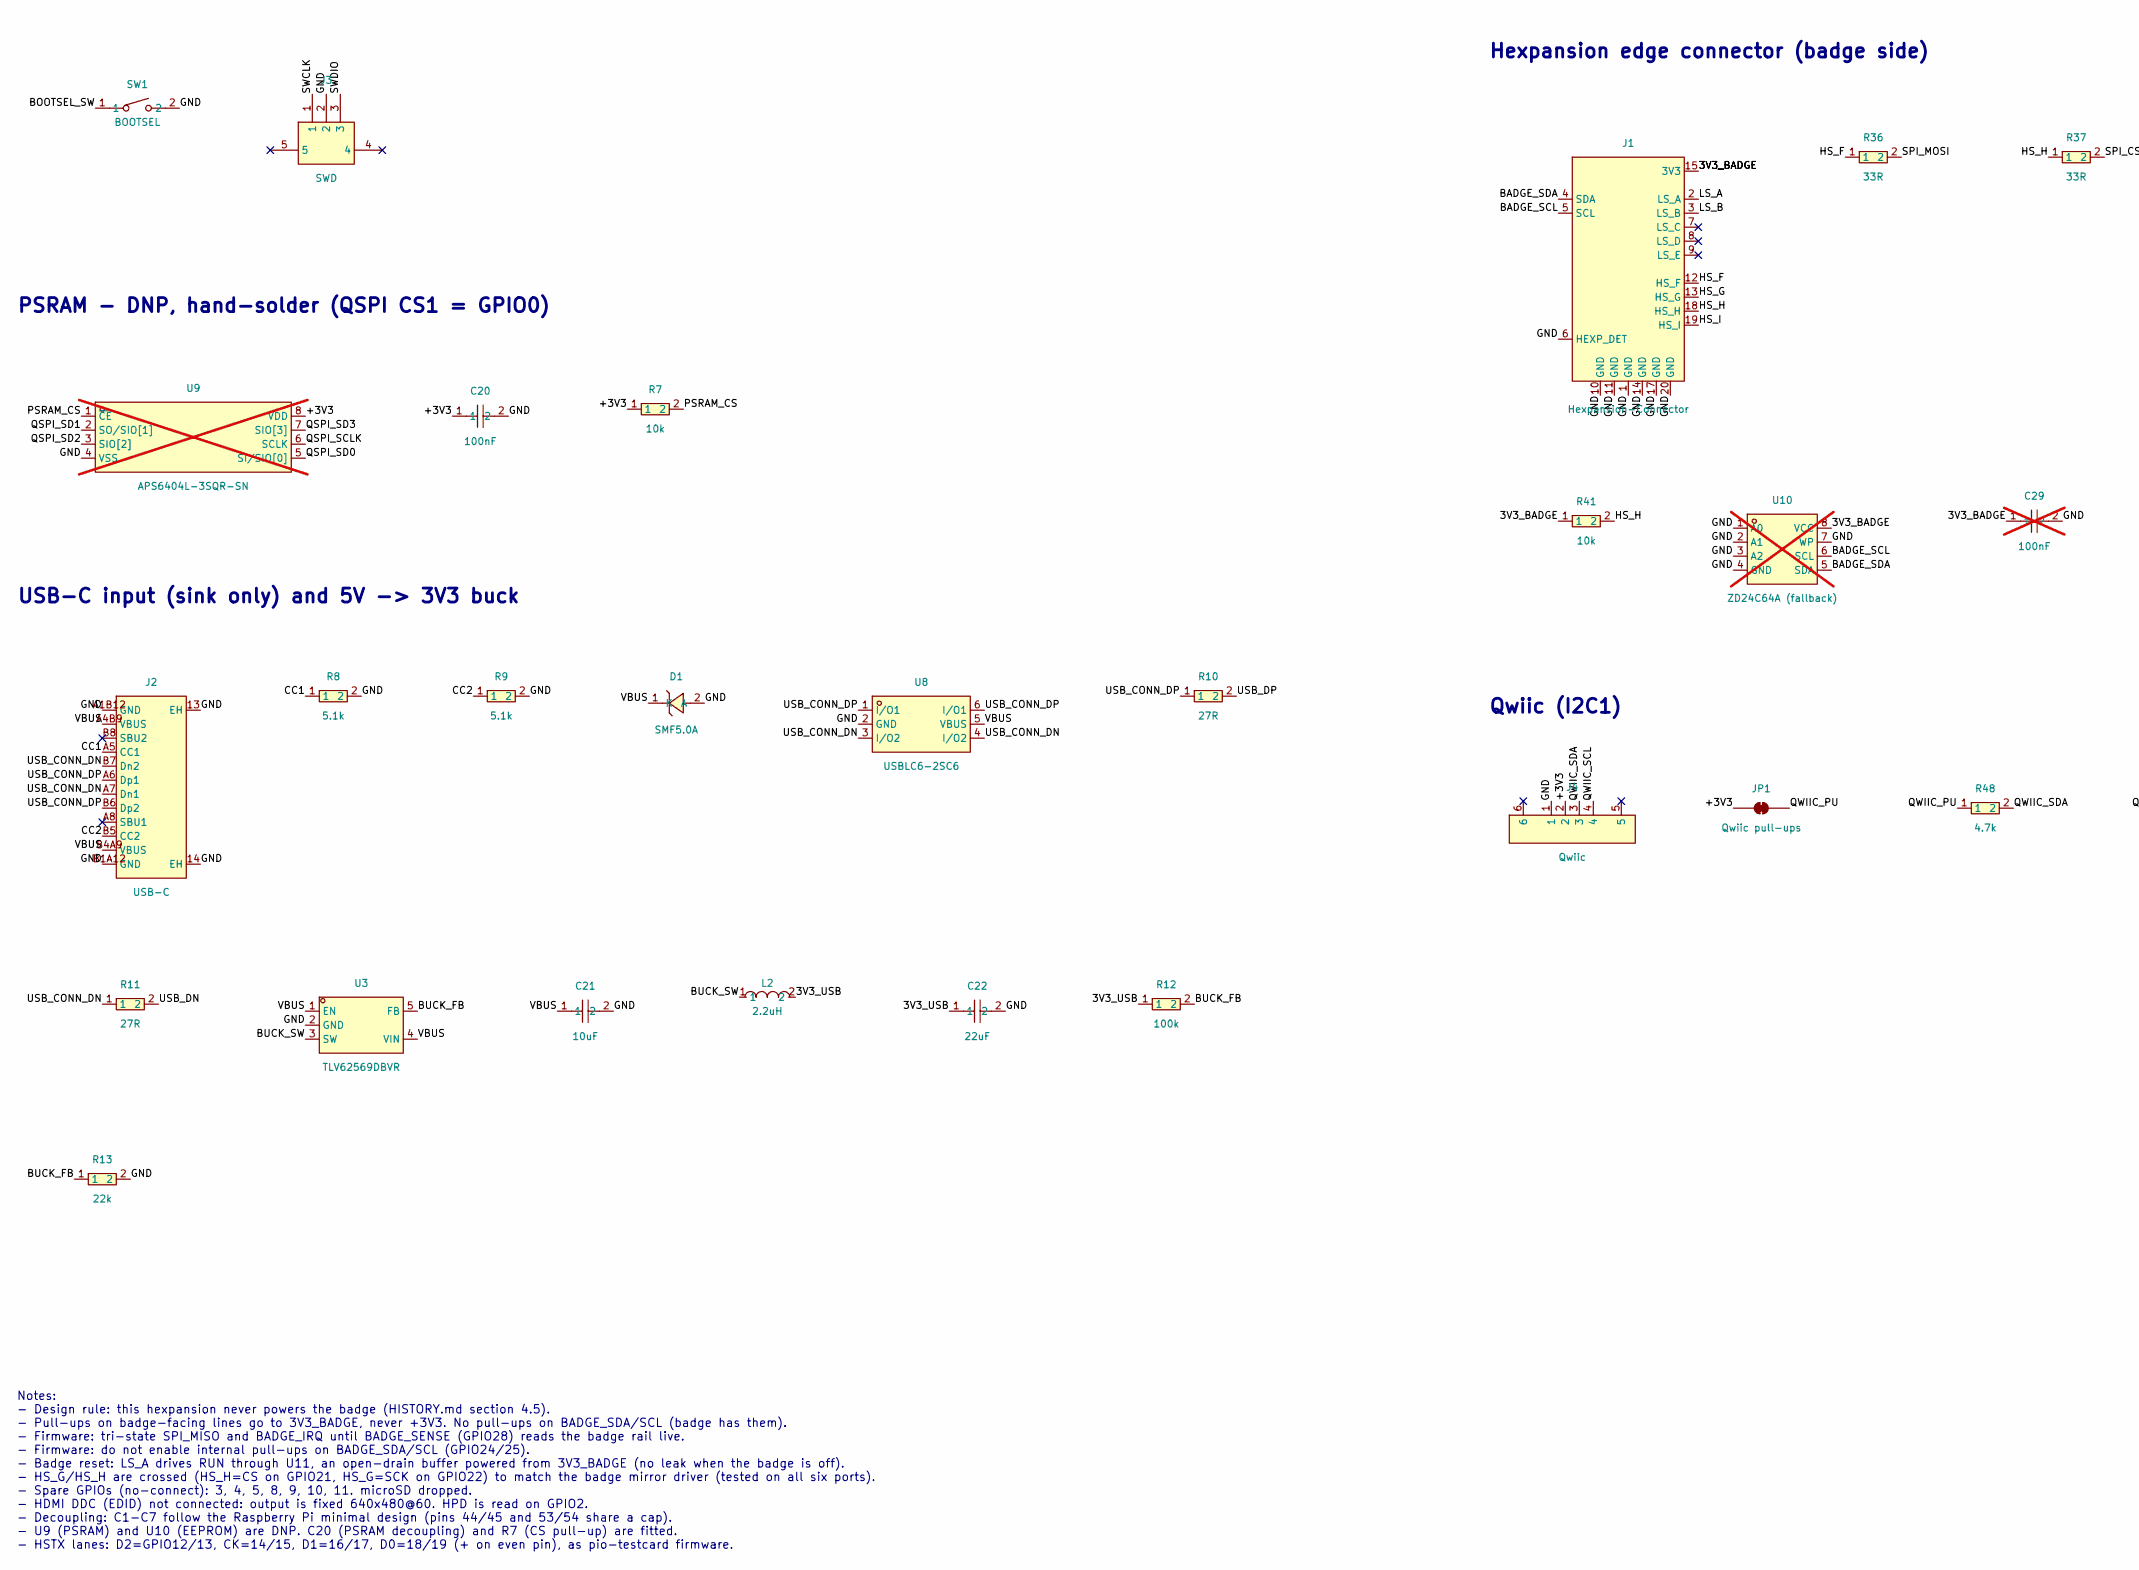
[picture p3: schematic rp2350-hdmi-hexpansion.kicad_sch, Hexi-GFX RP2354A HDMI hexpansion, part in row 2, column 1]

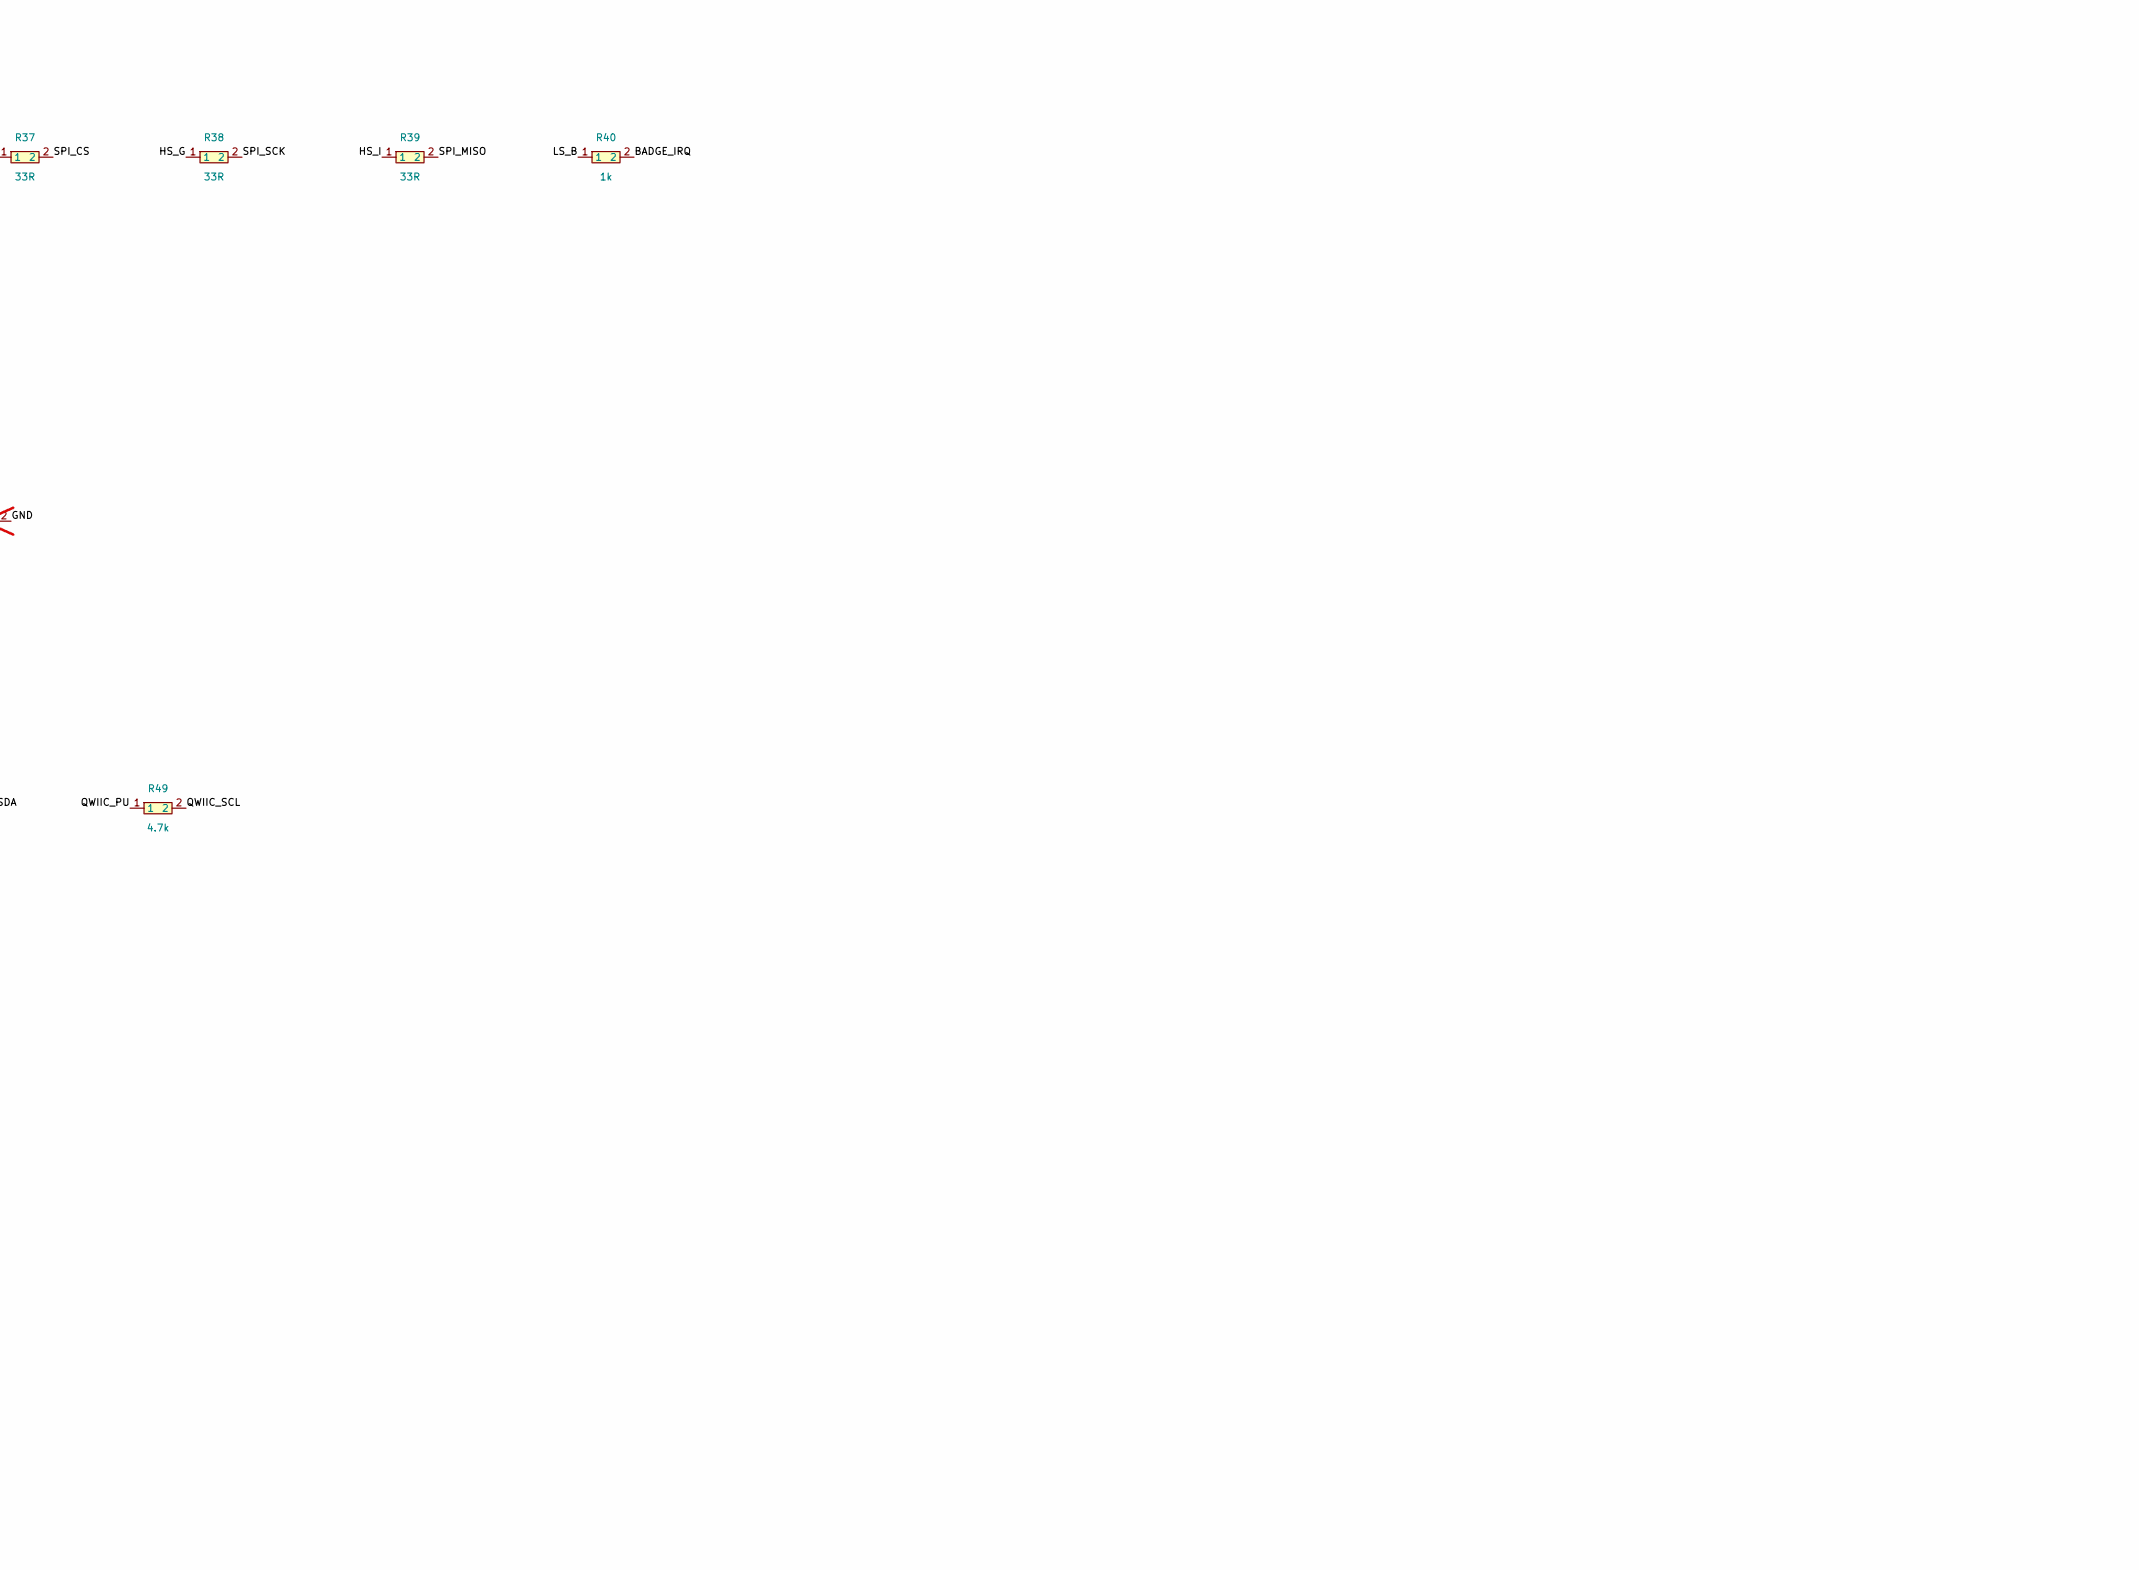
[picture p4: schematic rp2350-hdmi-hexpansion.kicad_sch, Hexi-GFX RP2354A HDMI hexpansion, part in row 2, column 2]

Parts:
C1, C2, C3, C4, C5, C6, C7, C10, C11, C12, C20, C32, C33: 100nF; C0402; MPN CL05B104KO5NNNC; LCSC Part C1525
C13, C14, C15: 4.7uF; C0402; MPN CL05A475MP5NRNC; LCSC Part C23733
C16, C21, C23, C25: 10uF; C0603; MPN CL10A106KP8NNNC; LCSC Part C19702
C17, C18: 15pF; C0402; MPN 0402CG150J500NT; LCSC Part C1548
C22, C24, C26: 22uF; C0805; MPN CL21A226MAQNNNE; LCSC Part C45783
C29: 100nF; C0402; MPN CL05B104KO5NNNC; LCSC Part C1525; not fitted
D1: SMF5.0A; SOD-123FL_L2.7-W1.8-LS3.8-RD; MPN SMF5.0A; LCSC Part C19077497
F1: 200mA PTC; F0805; MPN JK-SMD0805-020-30V; LCSC Part C516070
H1, H2: MountingHole; MountingHole_2.2mm_M2_Pad_Via
J1: Hexpansion-Connector; hexpansion-edge-connector
J2: USB-C; USB-C-SMD_TYPE-C-16PIN-2MD-073; MPN TYPE-C 16PIN 2MD(073); LCSC Part C2765186
J3: SWD; CONN-SMD-3P-P1.00_BM03B-SRSS-TB-LF-SN; MPN BM03B-SRSS-TB(LF)(SN); LCSC Part C160389
J4: Qwiic; CONN-SMD_4P-P1.00_SM04B-SRSS-TB-LF-SN; MPN SM04B-SRSS-TB(LF)(SN); LCSC Part C160404
J5: HDMI-A; HDMI-SMD_19P-P0.50-H-F; MPN HDMI-001 19PCBTP; LCSC Part C138388
JP1: Qwiic pull-ups; SolderJumper-2_P1.3mm_Bridged_RoundedPad1.0x1.5mm
L1: 3.3uH; IND-SMD_L2.0-W1.6_AOTA-B201610S3R3-101-T; MPN AOTA-B201610S3R3-101-T; LCSC Part C42411119
L2: 2.2uH; IND-SMD_L2.5-W2.0_MHCHL2520; MPN FTC252012S2R2MBCA; LCSC Part C5832372
L3: 1uH; IND-SMD_L2.5-W2.0_FTC252010S; MPN FTC252010S1R0MBCA; LCSC Part C5832356
LED1: PWR; LED-SMD_L1.6-W0.8-R-RD; MPN KT-0603R; LCSC Part C2286
LED2: STATUS; LED-SMD_L1.6-W0.8-R-RD; MPN KT-0603R; LCSC Part C2286
LED3: SK6805; LED-SMD_4P-L2.7-W2.4_SK6805MICRO-J; MPN SK6805MICRO-J; LCSC Part C2909056
R1, R36, R37, R38, R39: 33R; R0402; MPN 0402WGF330JTCE; LCSC Part C25105
R2, R6, R40, R51: 1k; R0402; MPN 0402WGF1001TCE; LCSC Part C11702
R3, R4, R7, R41: 10k; R0402; MPN 0402WGF1002TCE; LCSC Part C25744
R8, R9: 5.1k; R0402; MPN 0402WGF5101TCE; LCSC Part C25905
R10, R11: 27R; R0402; MPN 0402WGF270JTCE; LCSC Part C25100
R12, R16, R17, R18, R34, R35: 100k; R0402; MPN 0402WGF1003TCE; LCSC Part C25741
R13, R15: 22k; R0402; MPN 0402WGF2202TCE; LCSC Part C25768
R14: 33k; R0402; MPN 0402WGF3302TCE; LCSC Part C25779
R19: 200k; R0402; MPN 0402WGF2003TCE; LCSC Part C25764
R20: 27k; R0402; MPN 0402WGF2702TCE; LCSC Part C25771
R48, R49, R50: 4.7k; R0402; MPN 0402WGF4701TCE; LCSC Part C25900
R52: 330R; R0402; MPN 0402WGF3300TCE; LCSC Part C25104
SW1: BOOTSEL; SW-SMD_L3.9-W3.0-P4.45; MPN TS-1088-AR02016; LCSC Part C720477
SW2: RESET; SW-SMD_L3.9-W3.0-P4.45; MPN TS-1088-AR02016; LCSC Part C720477
TP1: +3V3; TestPoint_Pad_D1.0mm
TP2: V5_HDMI; TestPoint_Pad_D1.0mm
TP3: GND; TestPoint_Pad_D1.0mm
U1: RP2354A; QFN-60_L7.0-W7.0-P0.40-TL-EP3.4; MPN RP2354A; LCSC Part C41378174
U2: TPS2116DRLR; SOT-583-8_L2.1-W1.6-P0.50-LS1.6-BL; MPN TPS2116DRLR; LCSC Part C3235557
U3: TLV62569DBVR; SOT-23-5_L3.0-W1.7-P0.95-LS2.8-BR; MPN TLV62569DBVR; LCSC Part C141836
U4: TPS61023DRLR; SOT-563_L1.6-W1.2-P0.50-LS1.6-BR; MPN TPS61023DRLR; LCSC Part C919459
U6, U7: TPD4E05U06; USON-10_L2.5-W1.0-P0.50-BL; MPN TPD4E05U06DQAR; LCSC Part C138714
U8: USBLC6-2SC6; SOT-23-6_L2.9-W1.6-P0.95-LS2.8-BL; MPN USBLC6-2SC6; LCSC Part C2687116
U9: APS6404L-3SQR-SN; SOIC-8_L4.9-W3.9-P1.27-LS6.0-BL; MPN APS6404L-3SQR-SN; LCSC Part C5333729; not fitted
U10: ZD24C64A (fallback); SOP-8_L4.9-W3.9-P1.27-LS6.0-BL; MPN ZD24C64A-SSGMT; LCSC Part C2896793; not fitted
U11: SN74LVC1G07; SOT-23-5_L3.0-W1.7-P0.95-LS2.8-BR; MPN SN74LVC1G07DBVR; LCSC Part C7829
Y1: 12MHz; CRYSTAL-SMD_4P-L3.2-W2.5-BL; MPN ABM8-272-T3; LCSC Part C20625731

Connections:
/3V3_BADGE: C23.1, C29.1, C33.1, J1.15 (3V3), J1.16 (3V3), R4.1, R16.1, R41.1, U2.6 (VIN2), U10.8 (VCC), U11.5 (VCC)
/3V3_USB: C22.1, L2.2, R12.1, R14.1, U2.3 (VIN1), U2.5 (MODE)
/+3V3: C1.1, C2.1, C3.1, C4.1, C5.1, C6.1, C7.1, C14.1, C16.1, C20.1, C24.1, C25.1, C32.1, J4.2, JP1.1 (A), L3.1, LED3.3 (VDD), R1.1, R3.1, R7.1, R50.1, TP1.1 (1_1), U1.1 (IOVDD), U1.11 (IOVDD), U1.20 (IOVDD), U1.30 (IOVDD), U1.38 (IOVDD), U1.44 (ADC_AVDD), U1.45 (IOVDD), U1.49 (VREG_VIN), U1.53 (USB_OTP_VDD), U1.54 (QSPI_IOVDD), U2.2 (VOUT), U2.7 (VOUT), U4.3 (VIN), U9.8 (VDD)
/BADGE_IRQ: R40.2, U1.40 (GPIO26_ADC0)
/BADGE_SCL: J1.5 (SCL), U1.37 (GPIO25), U10.6 (SCL)
/BADGE_SDA: J1.4 (SDA), U1.36 (GPIO24), U10.5 (SDA)
/BADGE_SENSE: R16.2, R17.1, U1.42 (GPIO28_ADC2)
/BOOST_EN: R18.1, U1.43 (GPIO29_ADC3), U4.2 (EN)
/BOOST_FB: R19.2, R20.1, U4.1 (FB)
/BOOST_SW: L3.2, U4.5 (SW)
/BOOTSEL_SW: R6.2, SW1.1
/BUCK_FB: R12.2, R13.1, U3.5 (FB)
/BUCK_SW: L2.1, U3.3 (SW)
/CC1: J2.A5 (CC1), R8.1
/CC2: J2.B5 (CC2), R9.1
/DVDD: C10.1, C11.1, C12.1, C13.1, L1.2, U1.6 (DVDD), U1.23 (DVDD), U1.39 (DVDD), U1.50 (VREG_FB)
/GND: C1.2, C2.2, C3.2, C4.2, C5.2, C6.2, C7.2, C10.2, C11.2, C12.2, C13.2, C14.2, C15.2, C16.2, C17.2, C18.2, C20.2, C21.2, C22.2, C23.2, C24.2, C25.2, C26.2, C29.2, C32.2, C33.2, D1.2 (A), H1.1 (1_1), H2.1 (1_1), J1.1 (GND), J1.6 (HEXP_DET), J1.10 (GND), J1.11 (GND), J1.14 (GND), J1.17 (GND), J1.20 (GND), J2.13 (EH), J2.14 (EH), J2.A1B12 (GND), J2.B1A12 (GND), J3.2, J4.1, J5.2 (TMDSData2Shield), J5.5 (TMDSData1Shield), J5.8 (TMDSData0Shield), J5.11 (TMDSClockShield), J5.17 (DDC/CECGround), J5.20, J5.21, J5.22, J5.23, LED1.2 (K), LED2.2 (K), LED3.1 (GND), R8.2, R9.2, R13.2, R15.2, R17.2, R18.2, R20.2, R35.2, SW1.2, SW2.2, TP3.1 (1_1), U1.47 (VREG_PGND), U1.61 (EP), U2.1 (GND), U3.2 (GND), U4.4 (GND), U6.3 (GND), U6.8 (GND), U7.3 (GND), U7.8 (GND), U8.2 (GND), U9.4 (VSS), U10.1 (A0), U10.2 (A1), U10.3 (A2), U10.4 (GND), U10.7 (WP), U11.3 (GND), Y1.2 (GND), Y1.4 (GND)
/HDMI_CK_N: J5.12 (TMDSClock-), U1.19 (GPIO15), U6.5 (D2-), U6.6 (NC)
/HDMI_CK_P: J5.10 (TMDSClock+), U1.18 (GPIO14), U6.4 (D2+), U6.7 (NC)
/HDMI_D0_N: J5.9 (TMDSData0-), U1.31 (GPIO19), U7.5 (D2-), U7.6 (NC)
/HDMI_D0_P: J5.7 (TMDSData0+), U1.29 (GPIO18), U7.4 (D2+), U7.7 (NC)
/HDMI_D1_N: J5.6 (TMDSData1-), U1.28 (GPIO17), U7.2 (D1-), U7.9 (NC)
/HDMI_D1_P: J5.4 (TMDSData1+), U1.27 (GPIO16), U7.1 (D1+), U7.10 (NC)
/HDMI_D2_N: J5.3 (TMDSData2-), U1.17 (GPIO13), U6.2 (D1-), U6.9 (NC)
/HDMI_D2_P: J5.1 (TMDSData2+), U1.16 (GPIO12), U6.1 (D1+), U6.10 (NC)
/HDMI_HPD: J5.19 (HotPlugDetect), R34.1
/HPD_SENSE: R34.2, R35.1, U1.4 (GPIO2)
/HS_F: J1.12 (HS_F), R36.1
/HS_G: J1.13 (HS_G), R38.1
/HS_H: J1.18 (HS_H), R37.1, R41.2
/HS_I: J1.19 (HS_I), R39.1
/LED1_A: LED1.1 (A), R50.2
/LED2_A: LED2.1 (A), R51.2
/LED_STATUS: R51.1, U1.3 (GPIO1)
/LS_A: J1.2 (LS_A), R4.2, U11.2 (A)
/LS_B: J1.3 (LS_B), R40.1
/MUX_PR1: R14.2, R15.1, U2.4 (PR1)
/PSRAM_CS: R7.2, U1.2 (GPIO0), U9.1 (~CE)
/QSPI_SCLK: U1.56 (QSPI_SCLK), U9.6 (SCLK)
/QSPI_SD0: U1.57 (QSPI_SD0), U9.5 (SI/SIO[0])
/QSPI_SD1: U1.59 (QSPI_SD1), U9.2 (SO/SIO[1])
/QSPI_SD2: U1.58 (QSPI_SD2), U9.3 (SIO[2])
/QSPI_SD3: U1.55 (QSPI_SD3), U9.7 (SIO[3])
/QSPI_SS: R6.1, U1.60 (QSPI_SS)
/QWIIC_PU: JP1.2 (B), R48.1, R49.1
/QWIIC_SCL: J4.4, R49.2, U1.10 (GPIO7)
/QWIIC_SDA: J4.3, R48.2, U1.9 (GPIO6)
/RGB_DIN: R52.1, U1.41 (GPIO27_ADC1)
/RGB_DIN_R: LED3.2 (DIN), R52.2
/RUN: R3.2, SW2.1, U1.26 (RUN), U11.4 (Y)
/SPI_CS: R37.2, U1.33 (GPIO21)
/SPI_MISO: R39.2, U1.35 (GPIO23)
/SPI_MOSI: R36.2, U1.32 (GPIO20)
/SPI_SCK: R38.2, U1.34 (GPIO22)
/SWCLK: J3.1, U1.24 (SWCLK)
/SWDIO: J3.3, U1.25 (SWDIO)
/USB_CONN_DN: J2.A7 (Dn1), J2.B7 (Dn2), R11.1, U8.3 (I/O2), U8.4 (I/O2)
/USB_CONN_DP: J2.A6 (Dp1), J2.B6 (Dp2), R10.1, U8.1 (I/O1), U8.6 (I/O1)
/USB_DN: R11.2, U1.51 (USB_DM)
/USB_DP: R10.2, U1.52 (USB_DP)
/V5_BOOST: C26.1, F1.1, R19.1, U4.6 (VOUT)
/V5_HDMI: F1.2, J5.18 (+5VPower), TP2.1 (1_1)
/VBUS: C21.1, D1.1 (K), J2.A4B9 (VBUS), J2.B4A9 (VBUS), U3.1 (EN), U3.4 (VIN), U8.5 (VBUS)
/VREG_AVDD: C15.1, R1.2, U1.46 (VREG_AVDD)
/VREG_LX: L1.1, U1.48 (VREG_LX)
/XIN: C17.1, U1.21 (XIN), Y1.1
/XOUT: R2.1, U1.22 (XOUT)
/XOUT_XTAL: C18.1, R2.2, Y1.3

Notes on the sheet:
USB-C input (sink only) and 5V -> 3V3 buck
HDMI Type A (DVI over HSTX)
LEDs, test pads, mounting
Reset, BOOTSEL, SWD
MCU - RP2354A (2 MB flash in package)
Hexpansion edge connector (badge side)
Qwiic (I2C1)
Power mux - never back-powers the badge
Notes: - Design rule: this hexpansion never powers the badge (HISTORY.md section 4.5). - Pull-ups on badge-facing lines go to 3V3_BADGE, never +3V3. No pull-ups on BADGE_SDA/SCL (badge has them). - Firmware: tri-state SPI_MISO and BADGE_IRQ until BADGE_SENSE (GPIO28) reads the badge rail live. - Fi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
HDMI +5V boost (enabled by GPIO29)
PSRAM - DNP, hand-solder (QSPI CS1 = GPIO0)

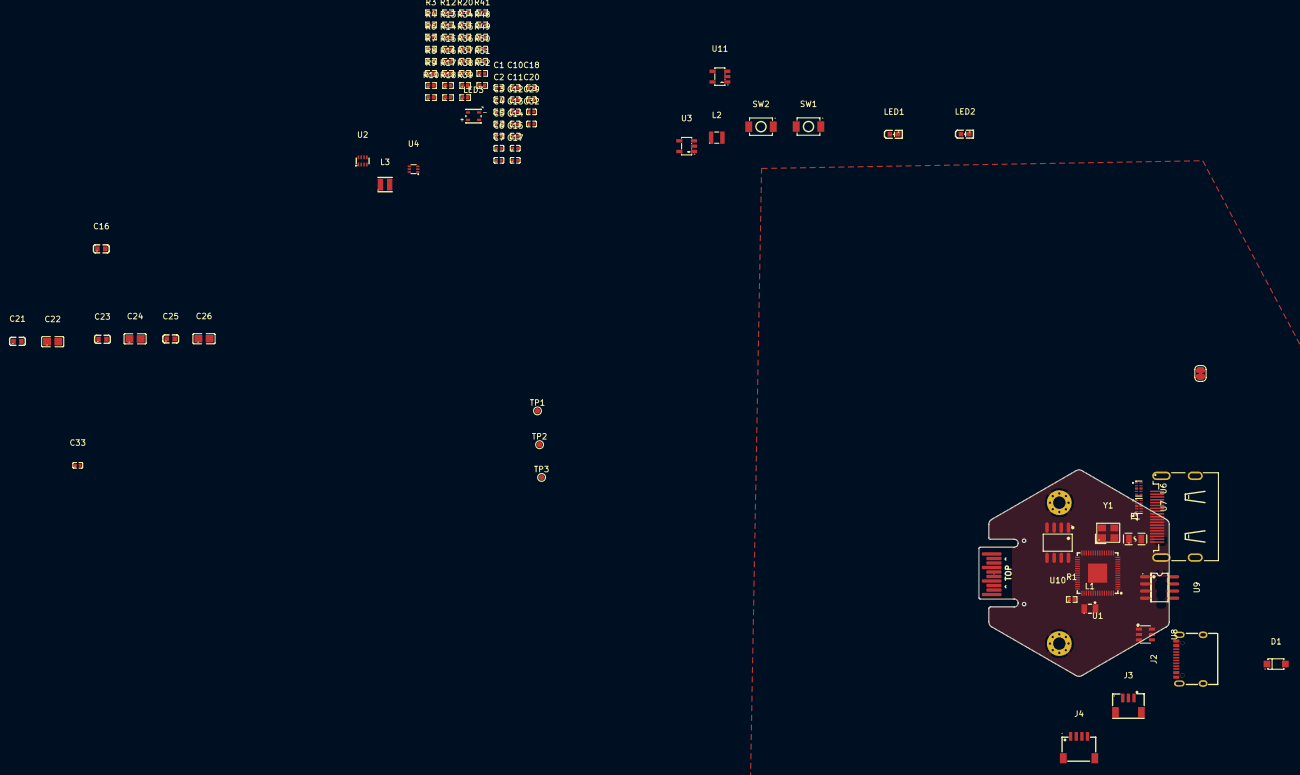
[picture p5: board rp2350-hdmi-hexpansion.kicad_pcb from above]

Board: 4 copper layers, 33.7 x 36.6 mm, 90 parts (0 on the bottom side), 68 nets.

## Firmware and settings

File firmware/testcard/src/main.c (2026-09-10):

// Hexi-GFX end-to-end link test (rp2350-hdmi-hexpansion, VID=0x1969
// PID=0x4544): the first firmware combining every Phase 0 piece into
// one image and one demonstration -- see ../../../README.md section 8.
//
// Badge plugs in -> discovers the emulated EEPROM (I2C0 target,
// eeprom_i2c.c, real VID/PID) -> mounts the real LittleFS image inside
// it (fs_image.h) -> auto-launches badge_app/app.py -> that app opens
// SPI0 (mode 3, CS-continuous -- the exact protocol proven in Phase 0
// A2/C3) and streams a live, badge-generated frame, row by row -> this
// firmware writes each row into framebuf and the connected monitor
// (HSTX/DVI, colour-correct per Phase 0 A1) shows it, continuously, "as
// if mirrored from the badge". Every link in that chain was proven
// individually in Phase 0; this is the first firmware to run all of
// them at once.
//
// 2026-08-30: reworked from a 4-pattern SELECT-command demo (badge picks
// among a few RP2350-generated test cards) into this -- the badge itself
// generates 240x240 RGB565 frame content in Python and streams it,
// matching what the real product's primary mode actually does (main
// README section 3.1), not just proving a control link. NOT a literal
// mirror of the badge's own rendered screen -- that needs display.get_fb()
// (Phase 0 C2's patch, written but never verified, and would mean
// flashing custom firmware onto a real physical badge, out of scope
// here) -- the badge instead builds pixel data directly in Python. Same
// wire format and bandwidth profile the real thing needs either way.
//
// Board: Metro RP2350 -- same bench rig as A2/C3/C4 (I2C0 on GPIO4/5,
// SPI0 on GPIO20-23) and phase0-dvi-colorfix (HSTX on GPIO12-19, its own
// dedicated 22-pin connector). All three pin groups are disjoint, so one
// physical board runs the whole demo.
//
// HSTX geometry: A1 Stage 2's real target -- 240x240 source, pillarboxed
// and circular-masked into 640x480 (matching the badge's own round
// display, per main README section 3.1/3.4) -- not Stage 1's simpler
// exact-double 320x240 shape the original pattern-select version of this
// file used. Row-fill/mask logic is phase0-dvi2's proven code, unchanged;
// colour config is the root-cause fix from firmware/phase0-dvi-colorfix/.

#include "hardware/clocks.h"
#include "hardware/dma.h"
#include "hardware/gpio.h"
#include "hardware/irq.h"
#include "hardware/pio.h"
#include "hardware/spi.h"
#include "hardware/structs/bus_ctrl.h"
#include "hardware/structs/hstx_ctrl.h"
#include "hardware/structs/hstx_fifo.h"
#include "hardware/sync.h"
#include "hardware/vreg.h"
#include "pico/multicore.h"
#include "pico/stdlib.h"
#include <math.h>
#include <stdio.h>
#include <string.h>

#include "ws2812.pio.h"

#include "eeprom_i2c.h"

// ----------------------------------------------------------------------------
// DVI constants (standard CEA-861 VIC 1, 640x480@60 -- see main README section 3.3)

#define TMDS_CTRL_00 0x354u
#define TMDS_CTRL_01 0x0abu
#define TMDS_CTRL_10 0x154u
#define TMDS_CTRL_11 0x2abu

#define SYNC_V0_H0 (TMDS_CTRL_00 | (TMDS_CTRL_00 << 10) | (TMDS_CTRL_00 << 20))
#define SYNC_V0_H1 (TMDS_CTRL_01 | (TMDS_CTRL_00 << 10) | (TMDS_CTRL_00 << 20))
#define SYNC_V1_H0 (TMDS_CTRL_10 | (TMDS_CTRL_00 << 10) | (TMDS_CTRL_00 << 20))
#define SYNC_V1_H1 (TMDS_CTRL_11 | (TMDS_CTRL_00 << 10) | (TMDS_CTRL_00 << 20))

#define MODE_H_FRONT_PORCH   16
#define MODE_H_SYNC_WIDTH    96
#define MODE_H_BACK_PORCH    48
#define MODE_H_ACTIVE_PIXELS 640

#define MODE_V_FRONT_PORCH   10
#define MODE_V_SYNC_WIDTH    2
#define MODE_V_BACK_PORCH    33
#define MODE_V_ACTIVE_LINES  480

#define MODE_V_TOTAL_LINES  ( \
    MODE_V_FRONT_PORCH + MODE_V_SYNC_WIDTH + \
    MODE_V_BACK_PORCH  + MODE_V_ACTIVE_LINES \
)

#define HSTX_CMD_RAW_REPEAT  (0x1u << 12)
#define HSTX_CMD_TMDS        (0x2u << 12)
#define HSTX_CMD_NOP         (0xfu << 12)

// ----------------------------------------------------------------------------
// Source image: 240x240 (the badge's own screen size), pre-doubled
// horizontally to 480-wide RGB565 rows in SRAM -- byte-for-byte
// phase0-dvi2's proven geometry. Vertical 2x re-reads each row twice
// (see dma_irq_handler). 240 words/row * 240 rows * 4 bytes = 230400
// bytes.

#define SRC_ROWS   240
#define DBL_W      480                 // 240 source pixels, doubled
#define DBL_WORDS  (DBL_W / 2)         // 2 RGB565 pixels/word
#define PILLARBOX  ((MODE_H_ACTIVE_PIXELS - DBL_W) / 2)  // 80px each side

// Real double buffering (2026-09-07) -- HEX_EEPROM_SIZE shrank from
// 64 KiB to 8 KiB (see eeprom_i2c.c) specifically to make room for this
// second 230400-byte copy: framebuf[2][...][...], one "front" (DMA scans
// it out continuously) and one "back" (the CPU writes freely into it,
// with NO per-row gating needed -- DMA never touches this index, so
// there is no race to guard against). front_index is flipped by
// dma_irq_handler itself, only ever at the start of vblank (v_scanline
// == 0, see below) and only when back_buffer_ready says a complete new
// frame is waiting -- the flip is a single word write, so it can't be
// caught mid-scanout the way the old single-buffer row-by-row copy
// could. This replaces both frame_staging (received rows now go
// straight into the back buffer's doubled/BGR-corrected words, no
// separate source-resolution staging copy needed) and
// framebuf_row_write_is_safe()/wait_until_row_write_safe() (nothing
// outside dma_irq_handler touches the front buffer at all, so there's
// nothing left for them to guard).
static uint32_t framebuf[2][SRC_ROWS][DBL_WORDS];
static volatile int front_index = 0;
static volatile bool back_buffer_ready = false;
static volatile uint32_t swap_count = 0;  // TEMP DEBUG: real front/back swaps done by dma_irq_handler

static inline int back_index(void) {
    return 1 - front_index;
}

// "No signal" pattern -- analog-TV-style static, generated here on the
// RP2350 (not sent by the badge), shown at boot before the badge's first
// streamed row ever arrives. A simple xorshift32 PRNG, not
// cryptographic-quality -- fine for visual noise.
static uint32_t rng_state = 0xC0FFEEu;

static inline uint32_t xorshift32(void) {
    uint32_t x = rng_state;
    x ^= x << 13;
    x ^= x >> 17;
    x ^= x << 5;
    rng_state = x;
    return x;
}

static inline uint16_t random_gray_pixel(void) {
    uint8_t v = (uint8_t)(xorshift32() & 0xFF);
    // RGB565 gray: top bits of the same 8-bit value into each channel's
    // field width (5/6/5), so R==B and G is the closest 6-bit match --
    // visually neutral gray, not tinted.
    return (uint16_t)(((v >> 3) << 11) | ((v >> 2) << 5) | (v >> 3));
}

static void fill_static_noise_row(int buf, int row) {
    for (int w = 0; w < DBL_WORDS; w++) {
        uint16_t c0 = random_gray_pixel();
        uint16_t c1 = random_gray_pixel();
        framebuf[buf][row][w] = (uint32_t)c0 | ((uint32_t)c1 << 16);
    }
}

// Fills the BACK buffer and flags it ready -- dma_irq_handler flips
// front_index at the next vblank (see its own comment). Safe to call at
// boot too (before core 1/HSTX has even started, back_buffer_ready is
// simply picked up the first time dma_irq_handler runs).
static void fill_static_noise(void) {
    int buf = back_index();
    for (int row = 0; row < SRC_ROWS; row++) {
        fill_static_noise_row(buf, row);
    }
    back_buffer_ready = true;
}

// EMF Camp colour-bar + logo test card -- a boot-time liveness indicator
// shown while waiting for the badge to stream its first full frame,
// distinct from fill_static_noise() above ("no signal" -- the link was
// working and has since gone quiet). Ported verbatim (same tables, same
// rasterisation) from spaceagon-display-tap's firmware/phase3-merged/,
// which uses this same pattern for the same purpose on the same
// framebuf geometry (240 source rows x 480 doubled-word columns).
static const uint16_t bar_colours[8] = {
    0xFFFF, // white   R+G+B
    0xFFE0, // yellow  R+G
    0x07FF, // cyan    G+B
    0x07E0, // green   G
    0xF81F, // magenta R+B
    0xF800, // red     R
    0x001F, // blue    B
    0x0000, // black
};

// Rasterized from the official symbol-only SVG (emfcamp.org/about/
// branding, emf2026-logo-black.svg) at 64x64 cells (each cell = one
// framebuf (row,word) entry = a 2x2 output-pixel block), 1 bit/pixel,
// MSB-first, 8 bytes/row.
#define EMF_LOGO_SIZE 64
static const uint8_t emf_logo_bitmap[EMF_LOGO_SIZE][EMF_LOGO_SIZE / 8] = {
    {0x00,0x00,0x00,0x01,0x80,0x00,0x00,0x00},
    {0x00,0x00,0x00,0x01,0x80,0x00,0x00,0x00},
    {0x00,0x00,0x00,0x01,0x80,0x00,0x00,0x00},
    {0x00,0x00,0x00,0x01,0x80,0x00,0x00,0x00},
    {0x00,0x00,0x00,0x01,0x80,0x00,0x00,0x00},
    {0x00,0x00,0x00,0x01,0x80,0x00,0x00,0x00},
    {0x00,0x00,0x00,0x01,0x80,0x00,0x00,0x00},
    {0x00,0x00,0x00,0x01,0x80,0x00,0x00,0x00},
    {0x00,0x00,0x00,0x01,0xc0,0x00,0x00,0x00},
    {0x1f,0x80,0x00,0x07,0xe0,0x00,0x00,0x00},
    {0x7f,0xfc,0x00,0x7f,0xfe,0x00,0x00,0x00},
    {0x78,0x00,0x01,0xff,0xff,0x80,0x00,0x00},
    {0x70,0x00,0x07,0xf0,0x0f,0xe0,0x00,0x38},
    {0x70,0x00,0x1f,0x80,0x01,0xf0,0x00,0x38},
    {0x70,0x00,0x1e,0x00,0x00,0x7c,0x00,0x10},
    {0x30,0x00,0x3c,0x00,0x00,0x3e,0x00,0x00},
    {0x30,0x00,0x78,0x00,0x00,0x1e,0x00,0x00},
    {0x10,0x00,0xf0,0x00,0x00,0x0f,0x00,0x00},
    {0x08,0x01,0xe0,0x00,0x00,0x07,0x80,0x00},
    {0x0c,0x01,0xc0,0x00,0x00,0x03,0x80,0x00},
    {0x06,0x03,0xc0,0x00,0x00,0x01,0xc0,0x00},
    {0x02,0x03,0x80,0x00,0x00,0x01,0xc0,0x00},
    {0x01,0x07,0x80,0x00,0x00,0x00,0xe0,0x00},
    {0x00,0x87,0x00,0x00,0x00,0x00,0xe0,0x00},
    {0x00,0x47,0x00,0x00,0x00,0x00,0xe0,0x00},
    {0x00,0x27,0x00,0x00,0x00,0x00,0xe0,0x00},
    {0x00,0x0e,0x00,0x1c,0x00,0x00,0x70,0x00},
    {0x00,0x0e,0x00,0x3f,0x07,0x00,0x70,0x00},
    {0x00,0x0e,0x00,0x7f,0xcf,0x00,0x70,0x00},
    {0x00,0x0f,0x00,0xff,0xfe,0x00,0x70,0x00},
    {0x00,0x0f,0x00,0xe1,0xfe,0x00,0x70,0x00},
    {0x00,0x06,0x00,0x40,0x78,0x00,0x78,0x00},
    {0x00,0x07,0x00,0x00,0x00,0x00,0xe4,0x00},
    {0x00,0x07,0x00,0x00,0x00,0x00,0xe2,0x00},
    {0x00,0x07,0x00,0x00,0x00,0x00,0xe1,0x00},
    {0x00,0x03,0x80,0x00,0x00,0x01,0xe0,0x80},
    {0x00,0x03,0x80,0x00,0x00,0x01,0xc0,0x40},
    {0x00,0x03,0xc0,0x00,0x00,0x03,0xc0,0x20},
    {0x00,0x01,0xc0,0x00,0x00,0x03,0x80,0x10},
    {0x00,0x01,0xe0,0x00,0x00,0x07,0x80,0x18},
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
};

#define EMF_LOGO_ROW0 88
#define EMF_LOGO_COL0 88
#define EMF_LOGO_ORANGE 0xF3E0u  // EMF's brand orange #F77F02 in RGB565
#define EMF_LOGO_BLACK  0x0000u

// Raw per-buffer writers (like fill_static_noise_row) -- callers pick
// the target buffer once, do all the writes a single logical update
// needs (bars, then optionally the logo on top), and only flag
// back_buffer_ready afterward. Doing it this way (rather than each
// function self-contained like fill_static_noise()) matters here
// specifically because the logo overlay must land in the SAME back
// buffer as the bars underneath it, before that buffer is handed to
// dma_irq_handler -- see both call sites in main().
static void fill_test_card_row(int buf, int row) {
    for (int w = 0; w < DBL_WORDS; w++) {
        int x0 = w * 2;
        int x1 = w * 2 + 1;
        uint16_t c0 = bar_colours[x0 / 60];
        uint16_t c1 = bar_colours[x1 / 60];
        framebuf[buf][row][w] = (uint32_t)c0 | ((uint32_t)c1 << 16);
    }
}

static void fill_test_card(int buf) {
    for (int row = 0; row < SRC_ROWS; row++) {
        fill_test_card_row(buf, row);
    }
}

static void draw_test_card_logo_row(int buf, int logo_row) {
    int fr = EMF_LOGO_ROW0 + logo_row;
    for (int w = 0; w < EMF_LOGO_SIZE; w++) {
        int fw = EMF_LOGO_COL0 + w;
        bool ink = (emf_logo_bitmap[logo_row][w / 8] >> (7 - (w % 8))) & 1;
        uint16_t colour = ink ? EMF_LOGO_ORANGE : EMF_LOGO_BLACK;
        framebuf[buf][fr][fw] = (uint32_t)colour | ((uint32_t)colour << 16);
    }
}

// Per active-output-row (0..479) half-width of the visible circle, in
// pixels, always even (word-aligned: 2 RGB565 pixels/word) -- unchanged
// from phase0-dvi2, see that file for the full derivation.
static uint16_t row_half_width[MODE_V_ACTIVE_LINES];

static void build_row_table(void) {
    const float radius = DBL_W / 2.0f;
    const float centre = (MODE_V_ACTIVE_LINES - 1) / 2.0f;
    for (int row = 0; row < MODE_V_ACTIVE_LINES; row++) {
        float dy = row - centre;
        float hw = 0.0f;
        if (fabsf(dy) < radius) {
            hw = sqrtf(radius * radius - dy * dy);
        }
        int half_width = (int)(hw + 0.5f);
        half_width -= half_width & 1;
        if (half_width < 0) half_width = 0;
        if (half_width > (int)radius) half_width = (int)radius;
        row_half_width[row] = (uint16_t)half_width;
    }
}

// ----------------------------------------------------------------------------
// HSTX command lists -- unchanged from phase0-dvi2 (proven on hardware).

static uint32_t vblank_line_vsync_off[] = {
    HSTX_CMD_RAW_REPEAT | MODE_H_FRONT_PORCH,
    SYNC_V1_H1,
    HSTX_CMD_RAW_REPEAT | MODE_H_SYNC_WIDTH,
    SYNC_V1_H0,
    HSTX_CMD_RAW_REPEAT | (MODE_H_BACK_PORCH + MODE_H_ACTIVE_PIXELS),
    SYNC_V1_H1,
    HSTX_CMD_NOP
};

static uint32_t vblank_line_vsync_on[] = {
    HSTX_CMD_RAW_REPEAT | MODE_H_FRONT_PORCH,
    SYNC_V0_H1,
    HSTX_CMD_RAW_REPEAT | MODE_H_SYNC_WIDTH,
    SYNC_V0_H0,
    HSTX_CMD_RAW_REPEAT | (MODE_H_BACK_PORCH + MODE_H_ACTIVE_PIXELS),
    SYNC_V0_H1,
    HSTX_CMD_NOP
};

// One HSTX_CMD_TMDS covering the full 640px active width -- see
// phase0-dvi2/src/main.c's comment for why the black pillarbox/mask
// fill must be plain DMA data under this same command, never separate
// TMDS commands (extra command-boundary stalls break horizontal sync).
static uint32_t vactive_line[] = {
    HSTX_CMD_RAW_REPEAT | MODE_H_FRONT_PORCH,
    SYNC_V1_H1,
    HSTX_CMD_NOP,
    HSTX_CMD_RAW_REPEAT | MODE_H_SYNC_WIDTH,
    SYNC_V1_H0,
    HSTX_CMD_NOP,
    HSTX_CMD_RAW_REPEAT | MODE_H_BACK_PORCH,
    SYNC_V1_H1,
    HSTX_CMD_TMDS       | MODE_H_ACTIVE_PIXELS
};

#define ZERO_BUF_WORDS 160
static uint32_t zero_buf[ZERO_BUF_WORDS] = {0};

// ----------------------------------------------------------------------------
// DMA logic -- two channels ping-ponging via chain_to, four phases per
// active row (command list / left fill / pixel data / right fill), one
// HSTX command total per row -- unchanged from phase0-dvi2. Reads
// framebuf[front_index], never the back buffer -- see framebuf's own
// declaration comment above for the double-buffering design and why the
// swap below can never land mid-scanout.

#define DMACH_PING 0
#define DMACH_PONG 1

static bool dma_pong = false;
static volatile uint v_scanline = 2;  // read from main() only for DEBUG_SERIAL logging now -- must not be cached across a spin loop
static int active_phase = 0;  // 0=left fill, 1=pixel data, 2=right fill
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
int main(void) {
    // Claim the HSTX ping-pong channels BEFORE anything else calls
    // dma_claim_unused_channel() (spi0_slave_init(), below, for its own
    // SPI0 RX DMA) -- hstx_dvi_init() configures DMACH_PING/DMACH_PONG
    // by hardcoded channel number directly, never through
    // dma_channel_claim(), so the SDK's own claimed-channel bookkeeping
    // has no way to know they're spoken for otherwise, and
    // dma_claim_unused_channel() could hand one of them out to whatever
    // asks first. Same class of bug spaceagon-display-tap's
    // firmware/phase3-merged/ already hit and fixed for its own,
    // different second DMA consumer (see that project's main() comment).
    dma_channel_claim(DMACH_PING);
    dma_channel_claim(DMACH_PONG);

    // Section 5 mitigation #1: I2C0 target up before anything else,
    // including clock reconfiguration -- see eeprom_i2c.h.
    eeprom_i2c_start();

    // clk_hstx follows clk_sys undivided by default; 640x480@60 needs
    // clk_sys=126MHz -- see phase0-dvi/README.md for the derivation.
    set_sys_clock_khz(126000, true);

    // RP2350 core1-launch voltage erratum (spaceagon-display-tap's
    // firmware/phase3-merged/README.md, "Bug 1"): multicore_launch_core1()
    // can hang -- core 1 stuck in a bootrom FIFO-status-polling loop,
    // never reaching its entry function -- at stock 1.10V, independent
    // of target clock frequency. Bump before launching core 1, with a
    // short settle delay.
    vreg_set_voltage(VREG_VOLTAGE_1_20);
    sleep_ms(10);

    build_row_table();
    fill_test_card(back_index());  // EMF bars, shown until the badge's first full frame arrives -- see ever_received_frame below
    back_buffer_ready = true;
    spi0_slave_init();
    neopixel_init();

    // Video (HSTX/DMA setup + dma_irq_handler) now runs on its own core;
    // this core's main loop below keeps the SPI0 receive path. Matches
    // the core assignment spaceagon-display-tap's firmware/phase3-merged
    // found necessary on real RP2350 hardware ("Bug 2" in that project's
    // README): the opposite assignment (video on core 0, the
    // receive/decode job launched onto core 1) reproducibly broke video
    // on that project's identical silicon -- confirmed fixed by swapping
    // which job runs on which core, root cause never pinned down at the
    // register level. Applied here pre-emptively, before this firmware
    // hits the same wall. This also removes hstx_dvi_init()'s original
    // need to fight the SPI0 polling loop for core time via a DMA_IRQ_0
    // priority boost (see that function's own history) -- they no longer
    // share a core at all.
    multicore_launch_core1(core1_video_entry);

    uint8_t row_rx[ROW_RX_BYTES];
    uint row_index = 0;
    int recv_buf = back_index();  // which buffer the in-progress frame's rows land in -- refreshed at each frame's row 0, see below

    // Heartbeat: RED, 1Hz, wall-clock-timed (not tied to row/frame
    // arrival -- this must keep blinking even with no badge connected at
    // all, which the old row-count-based version couldn't do since it
    // never ran without SPI activity). GREEN briefly overrides it for
    // ~80ms whenever a new frame actually completes, so red = alive,
    // green = link active, distinguishable at a glance.
    bool heartbeat_red_on = false;
    absolute_time_t next_red_toggle = make_timeout_time_ms(500);
    absolute_time_t green_flash_until = nil_time;

    // Idle detection is wall-clock-timed: spi0_take_row() itself is
    // instant (just checks a flag set by the ISR), so the outer loop
    // spins fast regardless of link state -- IDLE_AFTER_MS is what
    // actually distinguishes "genuinely idle" from a brief gap between
    // rows (MicroPython GC pauses, background WiFi/BT servicing,
    // scheduler jitter between one row and the next).
    #define IDLE_AFTER_MS 500
    absolute_time_t last_row_time = get_absolute_time();

    // Set the first time a full frame lands (row_index wraps back to 0
    // below) -- gates which fallback pattern genuine idle shows.
    // Before it: EMF test card (this hexpansion is up, just waiting for
    // the badge's app to start). After it: static noise (the link WAS
    // working and has since gone quiet) -- see the genuinely_idle
    // branch below. Matches spaceagon-display-tap's own frame_ready
    // semantics ("stop overwriting framebuf with the synthetic
    // bars/logo pattern" once real content has ever arrived).
    bool ever_received_frame = false;
    // Set on the very first successful got_row, before ever_received_frame --
    // gates the EMF test card blink below (must stop the instant real
    // bytes start arriving, not only once a full frame completes; see
    // that block's own comment).
    bool ever_received_any_row = false;
    bool testcard_logo_on = false;
    absolute_time_t next_testcard_blink = make_timeout_time_ms(700);

#ifdef DEBUG_SERIAL
    // UART, not USB -- see CMakeLists.txt's own comment on this build's
    // stdio choice. No stdio_usb_connected()-style handshake exists (or
    // is needed) for a plain UART; a short fixed settle delay is enough
    // for a host-side terminal to already be listening.
    stdio_init_all();
    sleep_ms(200);
    printf("\ntestcard DEBUG_SERIAL build: entering SPI0 receive loop\n");
    uint32_t rows_received = 0;
#endif

    for (;;) {
        spi0_process_ring();
        bool got_row = spi0_take_row(row_rx);

        if (got_row) {
#ifdef DEBUG_SERIAL
            rows_received++;
            if (rows_received <= 5 || (rows_received % 240) == 0) {
                printf("row_rx #%lu: first 8: %02x %02x %02x %02x %02x %02x %02x %02x\n",
                       (unsigned long)rows_received,
                       row_rx[0], row_rx[1], row_rx[2], row_rx[3],
                       row_rx[4], row_rx[5], row_rx[6], row_rx[7]);
            }
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

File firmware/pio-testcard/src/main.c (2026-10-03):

// pio-testcard: firmware/testcard's real HSTX/DVI video pipeline and
// double-buffered framebuffer, combined with firmware/mirror_debug's
// PIO-based SPI0 slave receiver -- see this project's own CMakeLists.txt
// comment and hexigfx-mirror-status memory (2026-09-19) for the full
// history. Where testcard/src/main.c's own receiver spoke the OLDER
// badge_app/app.py synthetic-frame protocol (mode 3, an 8-byte 0xA55A
// marker, no real CS framing), this firmware speaks hazanjon's REAL
// `flow3r_bsp_display_mirror.c` protocol from badge-2024-software: mode 0
// (CPOL=0, CPHA=0), a real 4-byte "TDHD" header, one continuous CS-low
// burst per whole frame (header immediately followed by the raw 240x240
// RGB565 pixel payload, CS only deasserting once the whole frame is
// sent) -- exactly what mirror_debug proved receives correctly on real
// hardware via a from-scratch PIO program instead of the RP2350's own
// hardware SPI0/PL022 peripheral (which loses byte-alignment mid-burst
// and never recovers -- proven via a real logic-analyzer capture plus a
// fine-grained SSPSR/DMA trace, see spi_slave_rx.pio's own comment).
//
// Board: Metro RP2350 by default, same bench rig as testcard/mirror_debug
// (SPI0 on GPIO20-23, HSTX on GPIO12-19, I2C0/EEPROM emulation on GPIO4/5
// -- see eeprom_i2c.h). Or, with -DHEXI_BOARD=feather, an Adafruit Feather
// RP2350 + HSTX: same HSTX and I2C0 pins, SPI slave moved to GPIO9-11 and
// the NeoPixel to GPIO21 (see PIN_MOSI below). Carries testcard's
// hexpansion-EEPROM emulation (copied verbatim 2026-09-20) so the badge
// auto-enumerates this hexpansion and auto-launches the packed app.py,
// instead of needing a manual sideload of mirror_screen_test/
// display_manager on every badge used for testing.
//
// HSTX geometry, framebuffer layout, double-buffering, EMF test-card/
// static-noise fallback patterns, and the DMA ping-pong scanout itself
// are all UNCHANGED from testcard/src/main.c (already proven on real
// hardware) -- only the SPI0 receive path and main()'s own frame-
// assembly loop are new.

#include "hardware/clocks.h"
#include "hardware/dma.h"
#include "hardware/gpio.h"
#include "hardware/irq.h"
#include "hardware/pio.h"
#include "hardware/structs/bus_ctrl.h"
#include "hardware/structs/hstx_ctrl.h"
#include "hardware/structs/hstx_fifo.h"
#include "hardware/vreg.h"
#include "pico/multicore.h"
#include "pico/stdlib.h"
#include <math.h>
#include <stdio.h>
#include <string.h>

#include "eeprom_i2c.h"
#include "spi_slave_rx.pio.h"
#include "ws2812.pio.h"

// ----------------------------------------------------------------------------
// DVI constants (standard CEA-861 VIC 1, 640x480@60) -- identical to
// firmware/testcard/src/main.c.

#define TMDS_CTRL_00 0x354u
#define TMDS_CTRL_01 0x0abu
#define TMDS_CTRL_10 0x154u
#define TMDS_CTRL_11 0x2abu

#define SYNC_V0_H0 (TMDS_CTRL_00 | (TMDS_CTRL_00 << 10) | (TMDS_CTRL_00 << 20))
#define SYNC_V0_H1 (TMDS_CTRL_01 | (TMDS_CTRL_00 << 10) | (TMDS_CTRL_00 << 20))
#define SYNC_V1_H0 (TMDS_CTRL_10 | (TMDS_CTRL_00 << 10) | (TMDS_CTRL_00 << 20))
#define SYNC_V1_H1 (TMDS_CTRL_11 | (TMDS_CTRL_00 << 10) | (TMDS_CTRL_00 << 20))

#define MODE_H_FRONT_PORCH   16
#define MODE_H_SYNC_WIDTH    96
#define MODE_H_BACK_PORCH    48
#define MODE_H_ACTIVE_PIXELS 640

#define MODE_V_FRONT_PORCH   10
#define MODE_V_SYNC_WIDTH    2
#define MODE_V_BACK_PORCH    33
#define MODE_V_ACTIVE_LINES  480

#define MODE_V_TOTAL_LINES  ( \
    MODE_V_FRONT_PORCH + MODE_V_SYNC_WIDTH + \
    MODE_V_BACK_PORCH  + MODE_V_ACTIVE_LINES \
)

#define HSTX_CMD_RAW_REPEAT  (0x1u << 12)
#define HSTX_CMD_TMDS        (0x2u << 12)
#define HSTX_CMD_NOP         (0xfu << 12)

// ----------------------------------------------------------------------------
// Source image: 240x240 (the real Tildagon screen's own resolution,
// matching hazanjon's real payload size of SRC_ROWS*ROW_RX_BYTES =
// 240*480 = 115200 bytes -- see [[hexigfx-mirror-status]]'s own repeated
// "~100-110ms per 115200-byte payload" measurements), pre-doubled
// horizontally to 480-wide RGB565 rows in SRAM -- unchanged geometry from
// testcard/src/main.c.

#define SRC_ROWS   240
#define DBL_W      480                 // 240 source pixels, doubled
#define DBL_WORDS  (DBL_W / 2)         // 2 RGB565 pixels/word -- also equals the real, undoubled pixels/row (240), since this image happens to be square
#define PILLARBOX  ((MODE_H_ACTIVE_PIXELS - DBL_W) / 2)  // 80px each side

static uint32_t framebuf[2][SRC_ROWS][DBL_WORDS];
static volatile int front_index = 0;
static volatile bool back_buffer_ready = false;
static volatile uint32_t swap_count = 0;  // TEMP DEBUG: real front/back swaps done by dma_irq_handler

// DIAGNOSTIC (2026-09-20): increments on every dma_irq_handler call --
// several times per scanline, entirely independent of SPI0/core0 activity
// -- so this is a direct "is core1/HSTX still alive" signal. Added to
// disambiguate a reinsertion-triggered blank-monitor bug: UART evidence so
// far shows core0 either stops printing "frame landed" or (this session)
// goes silent after a handful of real frames, and it was never clear
// whether core1/HSTX itself had also hung or was still scanning out fine
// with nothing new to show. See the DEBUG_SERIAL heartbeat print in the
// main loop below.
static volatile uint32_t hstx_irq_count = 0;

static inline int back_index(void) {
    return 1 - front_index;
}

// "No signal" pattern -- shown once a real frame has landed before, then
// the link goes idle. Unchanged from testcard/src/main.c.
static uint32_t rng_state = 0xC0FFEEu;

static inline uint32_t xorshift32(void) {
    uint32_t x = rng_state;
    x ^= x << 13;
    x ^= x >> 17;
    x ^= x << 5;
    rng_state = x;
    return x;
}

static inline uint16_t random_gray_pixel(void) {
    uint8_t v = (uint8_t)(xorshift32() & 0xFF);
    return (uint16_t)(((v >> 3) << 11) | ((v >> 2) << 5) | (v >> 3));
}

static void fill_static_noise_row(int buf, int row) {
    for (int w = 0; w < DBL_WORDS; w++) {
        uint16_t c0 = random_gray_pixel();
        uint16_t c1 = random_gray_pixel();
        framebuf[buf][row][w] = (uint32_t)c0 | ((uint32_t)c1 << 16);
    }
}

static void fill_static_noise(void) {
    int buf = back_index();
    for (int row = 0; row < SRC_ROWS; row++) {
        fill_static_noise_row(buf, row);
    }
    back_buffer_ready = true;
}

// EMF Camp colour-bar + logo test card -- boot-time liveness indicator
// shown until the badge's first full frame arrives. Unchanged from
// testcard/src/main.c.
static const uint16_t bar_colours[8] = {
    0xFFFF, 0xFFE0, 0x07FF, 0x07E0, 0xF81F, 0xF800, 0x001F, 0x0000,
};
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

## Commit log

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2026-08-30 Phase 0 Part B: PSRAM bring-up via pico-sdk's official hardware_psram
    Upgraded to pico-sdk 2.3.0, which added an official BSD-3 hardware_psram
    library (auto-detects CS pin and size) -- avoids hand-rolling QMI PSRAM
    init or picking up a GPL-3.0 third-party driver by accident. Board
    header sets PICO_PSRAM_CS_PIN 47 + PICO_AUTO_DETECT_PSRAM_SIZE 1,
    matching Raspberry Pi's own adafruit_feather_rp2350.h idiom. Firmware
    now runs a write/read-back self-test across the whole detected chip on
    boot, timed, before the existing blink/heartbeat loop.
    Verified with an actual cmake --build: links hardware_psram cleanly and
    produces bringup.uf2.
    Clau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
    [main.c]
2026-08-30 Wait for USB CDC connection instead of a fixed sleep before printing
    Bytes written before the host opens the CDC port are dropped, not
    buffered, so a fixed sleep_ms() just gambles on how fast the terminal
    gets opened -- easy to miss the one-time PSRAM result. Now blinks fast
    while polling stdio_usb_connected(), up to a 10s timeout so the board
    still runs standalone with nothing attached.
    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
    [main.c]
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2026-08-30 Phase 0 B2 (microSD half): SD card + FatFs bring-up
    Vendors carlk3/no-OS-FatFS-SD-SDIO-SPI-RPi-Pico (Apache-2.0, wraps
    elm-chan's FatFs) as a submodule under third_party/, rather than
    hand-rolling the SD-over-SPI protocol -- same reasoning as using
    pico-sdk's official hardware_psram over a hand-written one: a
    well-tested implementation beats a hand-written one for something this
    easy to get subtly wrong at the protocol level.
    hw_config.c wires it to this board's socket (SPI0 on GPIO34/35/36,
    CS GPIO39, matching boards/adafruit_metro_rp2350.h). Card-detect
    (GPIO40) deliberately left unused -- polarity isn't confirmed against
    Adafruit's schematic, and a wrong guess would misreport presence
    ra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
    [hw_config.c, main.c]
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2026-08-30 B2 scanout result: 27 MB/s DMA read, short of the ~37 MB/s needed
    Measured on the Metro: bulk and per-line DMA reads both land around
    27.1 MB/s -- a real ~3.3x win over B1's CPU-scalar raw-write number
    (8.3 MB/s), and bulk/per-line being nearly identical confirms this is
    close to the actual hardware ceiling, not a DMA-setup-overhead
    artifact.
    That's ~27% short of the ~35-37 MB/s that continuous 640x480@60
    scanout literally requires (640x480x2 bytes x 60fps), not just a
    number to beat. Added a diagnostic (clk_sys frequency + QMI M1 CLKDIV
    register readback) to main.c's PSRAM section to find out whether
    that's a conservative default clock divisor before concluding
    anything stronger -- not yet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
    [main.c]
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2026-08-30 B3: Feather RP2350 bench, reusing the Metro's PSRAM/ctx benchmarks
    New firmware/phase0-feather/ targets the RP2350A Feather -- the chip
    variant the actual hexpansion design targets (README section 4.1).
    Uses Adafruit's official adafruit_feather_rp2350 pico-sdk board
    header (no custom header needed, unlike the Metro).
    Reuses copies (not a shared library -- disposable Phase 0 bench code,
    two independent copies beat coupling two bench projects together) of
    ctx_bench.c, psram_dma_bench.c and third_party/ctx from phase0-metro,
    since both benchmarks are board-agnostic. No SD bench (Feather has no
    microSD slot). Both benchmarks already skip cleanly if PSRAM isn't
    detected, so this runs safely whet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
    [main.c]
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2026-08-30 phase0-dvi: add heartbeat LED for diagnosis
    This firmware had zero local feedback (no LED, no USB serial) --
    useless for telling apart "crashed before main()", "hung during
    HSTX/DMA setup", and "running fine, video config itself is wrong"
    when nothing shows on the monitor. Added: 3 fast blinks right at the
    start of main() (proves boot+GPIO work), then a continuous ~1Hz
    heartbeat once HSTX/DMA setup completes.
    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
    [main.c]
2026-08-30 phase0-dvi: fix HSTX pixel clock (CLKDIV 5 -> 6)
    First hardware test: cable was flipped (confirmed separately by
    flashing CircuitPython + Adafruit's own picodvi driver, which showed
    a correct solid-red frame once reconnected properly -- so the
    physical chain and pin/lane mapping are both good). With the cable
    fixed, this firmware's own output got "out of range" on the monitor,
    not "no signal" -- meaning HSTX/DMA/sync generation is fundamentally
    working, just at the wrong pixel clock.
    Root cause: both reference implementations (pico-examples,
    Adafruit's PicoDVI) assumed clk_hstx defaults to 125MHz. It actually
    defaults to clk_sys undivided (pico-sdk's runtime_init_clocks), which
    is 150MHz on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
    [main.c]
2026-08-30 phase0-dvi: revert the CLKDIV change -- it was wrong
    CLKDIV is not a pixel-clock divisor. Per RP2350 datasheet section
    12.11.4, it only sets the dedicated clock-generator output's period,
    which must equal N_SHIFTS (5) to keep the clock and data streams
    aligned for valid TMDS -- the datasheet's own worked TMDS example
    uses exactly N_SHIFTS=5, CLKDIV=5. The previous commit's CLKDIV=6
    change desynced clock from data and broke TMDS decoding outright:
    confirmed on hardware, regressed from "out of range" (monitor
    detected a mode, just the wrong one) to "no signal" (undetected).
    The actual fix needs clk_hstx itself reconfigured to 126 MHz via
    clock_configure() -- a real pixel clock is fixed at clk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
    [main.c]
2026-08-30 phase0-dvi: set clk_sys to 126MHz for a correct 25.2MHz pixel clock
    clk_hstx follows clk_sys undivided by default, and the real pixel
    clock is fixed at clk_hstx/5 by the N_SHIFTS=5 DDR scheme (see the
    CSR comment in the previous commit). 640x480@60 needs 25.2MHz, i.e.
    clk_sys=126MHz -- confirmed against Panda381/DispHSTX's own tested
    video mode table (vmodetime_640x480, Unlicense), which explicitly
    sets "system clock 126 MHz" for this exact mode. The stock default
    (150MHz) was the actual root cause of the "out of range" result.
    One-line fix via pico-sdk's own set_sys_clock_khz(126000, true) --
    simpler than reconfiguring clk_hstx in isolation via clock_configure,
    and doesn't require adopting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
    [main.c]
2026-08-30 phase0-dvi: Stage 1 working -- 8 bars confirmed on real monitor
    Third bug found on hardware: colour channels come out in a clean
    3-way rotation (sent yellow -> displayed purple, sent cyan ->
    displayed yellow, etc. -- white/black round-trip correctly since
    they're invariant to any channel reorder). Confirms the doubling
    math, DMA read addressing, and TMDS/HSTX/DMA/timing chain are all
    correct -- only the R/G/B channel assumption was off.
    Fixed by empirically inverting the observed substitution table in
    bar_colours[] -- a test-pattern-level fix, not root-caused yet. Real
    badge pixel data can't be pre-rotated like this for free, so the
    actual expand_tmds/lane-mapping bug still needs finding be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
    [main.c]
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2026-08-30 Stage 2 fix: "no signal" was extra HSTX command-boundary stalls
    First hardware test: LED heartbeat and CPU-load measurement both
    completed fine (board alive, IRQ handler running continuously across
    many frames), but no picture -- "no signal", worse than Stage 1's
    "out of range".
    Root cause: the original design used three separate HSTX_CMD_TMDS/
    TMDS_REPEAT *commands* per active row (left fill, priming, right
    fill). Per RP2350 datasheet section 12.11.5, "the command expander
    cannot output data on the cycle where it pops a command from the
    FIFO, so the expansion shift register is empty for at least one
    cycle" -- each extra command boundary costs a stall Stage 1's proven
    single-command active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
    [main.c]
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2026-08-30 A2: SPI0-slave half confirmed working on real hardware, mode 3 + CS-continuous
    The all-zero/all-0xff failures were a physical wiring fault, not a mode/CPHA
    issue: the CS wire (HS_G -> Metro's SCL/GPIO21) wasn't actually reaching the
    RP2350, while SCK and MOSI on the same protoboard pass worked the whole time.
    Three new diagnostic firmwares (gpio_probe, spi_status_probe, spi_loopback_test)
    isolated this by ruling out the SPI0 peripheral itself (loopback test: match)
    and pinpointing CS specifically (edge counter: 0 edges on CS vs. correct counts
    on SCK/MOSI).
    After rewiring CS, the full sequence re-confirms clean: CS/SCK/MOSI edge counts
    all correct, SSPSR shows continuous RNE activity (48/48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
    [badge_test.py, gpio_probe.c, main.c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]
2026-08-30 C3: SPI0 link speed sweep + real 115,200-byte frame, confirmed on real hardware
    Swept 100 kHz-40 MHz over dupont-wire bench wiring: 100 kHz-20 MHz fully
    reliable once a repeatable ESP32-S3 master-side first-transaction artifact
    is accounted for (round 0 only, same fixed garbage every time, self-corrects
    from round 1 -- not a link problem, confirmed against an already-proven-good
    run). Genuine bit errors start at 30/40 MHz, matching the badge's own
    matrix-routed HS-pin ceiling (main README section 1.2).
    Pushed one real 115,200-byte frame (the badge's actual mirrored-framebuffer
    size) at 10 and 20 MHz: 0 mismatches both directions at both rates, wire
    time within 2-4% of the clock-rate theoret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
    [spi_frame_test.c, spi_frame_timing.py, spi_speed_sweep.py]
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2026-08-30 A1: root-cause the colour channel rotation, confirmed on real hardware
    The clean 3-way colour rotation phase0-dvi found on first bring-up wasn't
    a simple lane swap: the expand_tmds values copied from Adafruit's PicoDVI
    driver assumed the wrong TMDS lane order (L0=Red -- the real DVI/HDMI
    convention is L0=Blue/L1=Green/L2=Red, not alphabetical) and didn't
    decode to a clean bit-field under RP2350's own documented ROT/NBITS
    register semantics for this project's actual RGB565 packing.
    Recomputed from scratch (ROT = (channel_MSB_bit_index - 7) mod 32, from
    pico-sdk's own register header docs) and validated the formula against
    raspberrypi/pico-examples' own RGB332 sample before trusting it. New
    f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
    [main.c]
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2026-08-31 testcard: badge-generated mirror streaming, confirmed on real hardware
    The badge now generates the displayed frames itself (colour-rotating
    bars, built in Python) and streams them to the RP2350 over SPI0, rather
    than the RP2350 selecting among a few fixed patterns. Adds a NeoPixel
    heartbeat (red 1Hz when idle/alive, green flash per completed frame) and
    RP2350-generated analog-TV-style static shown at boot/no-signal.
    Three real-hardware bugs found and fixed along the way:
    - spi0_receive_row() relied on gpio_get() to detect CS edges, but that
    pin reads 0 unconditionally while configured GPIO_FUNC_SPI on this
    board -- CS-edge detection at the GPIO level doesn't work here at all.
    Replaced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
    [app.py, main.c]
2026-08-31 testcard: frame-rate investigation and badge-generated test screens
    Investigated a 15fps target for the mirror stream: tried one CS burst
    per frame instead of per row, plus 20MHz SPI (up from 1MHz), reaching
    a real ~5fps -- but that combination produced genuine visible
    corruption on the monitor (bus contention between continuous SPI
    receive polling and simultaneous HSTX DMA scanout, a combination Phase
    0 C3's own speed sweep never tested). Reverted to the per-row/1MHz
    protocol already confirmed clean, and root-caused the actual ceiling:
    badge-2024-software's own scheduler hardcodes a 50ms/tick floor on
    every foreground app's update() loop, which alone caps this well
    below 15fps regardless of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
    [app.py, main.c]
2026-08-31 testcard: correct icon1/icon2 identification, note unverified web source
    icon1 (U+71E9) re-confirmed spider-like even after the earlier centering
    fix, alongside icon2 (U+81E9) -- genuinely two similar glyphs, not one
    misread via clipping as first suspected.
    A badge docs page was checked for the "duck"/"spider"/"EMF logo" codepoint
    question. Its first fetch returned a suspiciously specific, likely
    hallucinated attribution; a second, less leading fetch gave different,
    less detailed content on the same URL. Since this fetch tool summarizes
    through a model regardless of prompt, specific per-codepoint claims from
    it aren't treated as verified -- only the general "shark, duck, spider,
    bats" masco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
    [app.py]
2026-08-31 testcard: confirm duck icon on real hardware, name screens, add colours
    Swapped icon4's codepoint from U+BA7B (a second bat-like glyph) to
    U+21E9, the separately-claimed "duck" codepoint that looked implausible
    from the font source alone (it sits mid-sequence among ordinary
    directional arrows). Tested directly on real hardware instead of
    continuing to argue from inference: U+21E9 genuinely renders as a
    rubber duck. Confirmed where source-reading and an unreliable web
    fetch both fell short.
    Screens now have descriptive names (bunny/spider7/spider8/bat/duck)
    instead of generic icon0..icon4, and each (except bunny, whose glyph
    sets its own colours internally) has a requested colour scheme:
    spi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
    [app.py]
2026-09-07 testcard: fix BGR colour swap, move video to core 1
    Port two fixes proven on real hardware in the sibling
    spaceagon-display-tap project's firmware/phase3-merged:
    - undo_madctl_bgr(): the real GC9A01 driver sets MADCTL_BGR, so the
    panel swaps Red/Blue in hardware relative to the plain RGB565 the
    badge packs. Currently latent here (badge_app's synthetic pattern
    never goes through the real panel driver) but will corrupt colours
    the moment this firmware mirrors a real display.get_fb() feed.
    - Launch HSTX/DMA setup (hstx_dvi_init, dma_irq_handler) on core 1 via
    multicore_launch_core1(), keeping the SPI0 receive loop on core 0.
    spaceagon-display-tap found the reverse assignment reprod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
    [main.c]
2026-09-07 testcard: EMF bars/logo test card at boot, static only once link drops
    Port spaceagon-display-tap's firmware/phase3-merged boot-time liveness
    pattern (same bar_colours/emf_logo_bitmap tables, same geometry) as a
    distinct state from the existing "no signal" static noise:
    - Before the badge has ever streamed a full frame: EMF colour bars,
    blinking in the EMF logo every 700ms -- "hexpansion is up, waiting
    for the badge app to start".
    - After a real frame has landed at least once, if the link then goes
    idle: static noise, unchanged from before -- "was working, now quiet".
    ever_received_frame gates the switch permanently once real content
    has arrived, matching phase3-merged's own frame_re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
    [main.c]
2026-09-07 testcard: real double-buffered framebuf, shrink EEPROM to fit it
    Fixes the visible tearing on every landed frame (framebuf wasn't
    double-buffered; per-row write-gating avoided corrupting the exact
    row DMA was reading but couldn't stop a frame showing a mix of
    old/new rows during the ~240-row copy).
    - HEX_EEPROM_SIZE: 64 KiB -> 8 KiB (the smallest size that stays on
    the badge's proven >=8KiB/512-byte-block path). badge_app/ is no
    longer packed into the emulated EEPROM's LittleFS -- side-load it
    onto the badge directly for testing instead. fs_image.h regenerated
    as an empty 15-block image; the badge's hexpansion manager already
    handles an empty mount gracefully (logs "App module not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
    [eeprom_i2c.c, main.c]
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2026-09-07 testcard: real get_fb() mirror app, fix SPI-poll/HSTX bus contention
    badge_app/app.py:
    - Add MirrorApp: the real display.get_fb() mirror TestcardApp stood in
    for, now that badge-2024-software's get_fb() patch has landed
    (commit 28e1906). Runs in background_update() (not update()), so it
    never steals foreground from whatever app the user actually has
    open -- background_update() runs for every registered app every
    ~50ms regardless of foreground state, unlike update()/draw() which
    are foreground-only (see system/app.py's App.run() docstring).
    - _swap_bytepairs(): tildagon_fb is CTX_FORMAT_RGB565_BYTESWAPPED (the
    real panel's own wire-format need), but the RP2350 side expects plain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
    [app.py, main.c]
2026-09-07 testcard: frame-sync marker, fixes the remaining row-drift issue
    Fixes the known, documented limitation left over after the SPI-poll
    bus-contention fix: with no CS-level framing, a single dropped byte
    anywhere left the badge's and RP2350's row counts permanently out of
    phase, self-correcting only by chance. Confirmed on real hardware as
    an occasional, visible vertical misalignment ("blue/white at the top
    of the screen", content changing/settling over several seconds).
    - FRAME_MARKER: 8-byte alternating-bit pattern (0xA55A repeated), sent
    as its own CS-low burst once before row 0 of every frame, by both
    TestcardApp._send_frame() and MirrorApp.background_update().
    src/m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
    [app.py, main.c]
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2026-09-08 testcard: DMA-driven SPI receive, real fixes and honest limits for fps
    Pursuing a 15fps target (main README section 3.1's C1 measurement:
    real apps render up to ~14fps) surfaced two more real, hardware-
    confirmed bugs and one hard hardware limit not yet root-caused.
    src/main.c:
    - Replace the interrupt-driven SPI0 receiver with a DMA-driven one
    (spi_rx_ring, a ring-addressed buffer; spi0_process_ring(), called
    from main()'s own loop instead of an ISR). Found needed at 20MHz:
    the interrupt-driven receiver's per-byte entry/register-read
    overhead couldn't keep up with the raw byte rate, causing real,
    reproducible corruption (diagonal streaking) confirmed on real
    hardware. A DMA chan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
    [app.py, main.c]
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2026-09-08 MirrorApp registers its own launcher menu entry from the hexpansion
    Replaces the separate hexi_mirror.py badge-2024-software launcher app
    entirely: MirrorApp now emits HexpansionAppLauncherAddEvent(port,
    "HDMI Mirror") from its own __init__ when genuinely hexpansion-
    launched, the same pattern Corteil/tildagon-space-unicorn's app.py
    uses. This makes "HDMI Mirror" a normal, dynamically-registered
    launcher entry with zero badge-2024-software-side code and no
    developer mode required, matching how a real hexpansion is meant to
    work.
    Added a minimal update()/draw() so tapping the entry shows a status
    readout (CANCEL to return) instead of a blank foregrounded screen --
    mirroring itself is unaffec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
    [app.py]
2026-09-10 testcard: switch to hazanjon's attach_mirror sink, fix real-hardware sync bugs
    Migrates off display.get_fb() polling onto hazanjon's push-based
    display.attach_mirror() sink per hdmi-mirror-plan.md. Found and fixed four
    real bugs along the way, all confirmed on real hardware: a dc-pin/MISO
    electrical conflict causing a badge panic-reboot loop, GPIO21/22's
    hardware-fixed (not software-reassignable) SPI0 roles that made reception
    silently receive zero bytes, a CPHA0-vs-CPHA1 mismatch against hazanjon's
    ESP32 SPI master, and a frame-resync marker that fought its own reception
    by resetting row_index on every marker instead of only at genuine frame
    boundaries. Real, correctly-interactive badge UI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
    [app.py, main.c]
2026-09-11 testcard: delay first attach_mirror() call, fix text centering, correct scope claims
    Defers MirrorApp's first display.attach_mirror() call by 1.5s past insertion
    (via background_update(), not a blocking sleep) after isolating a genuine
    permanent hang (spi_device_acquire_bus's unbounded portMAX_DELAY wait, no
    error-path cleanup) specifically to attach_mirror() itself -- app load and
    EEPROM/hexpansion detection were independently confirmed clean with the
    call skipped entirely. Real-hardware testing of this fix was complicated by
    an unrelated mixup (a physical badge running stock firmware gave a false
    "no hang" reading via a harmlessly-caught AttributeError); re-verified
    against confirmed-hazan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
    [app.py]
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2026-09-13 fix(mirror_debug): core1-launch hang, NeoPixel heartbeat, wiring diagnostics
    Fixes a real core1-launch hang: enabling the CS-edge GPIO IRQ before
    multicore_launch_core1() consistently left core1 stuck in the RP2350's
    bootrom FIFO-handoff loop (confirmed via GDB, PC parked outside any
    loaded symbol). Moved the GPIO IRQ setup, and NeoPixel PIO init added
    below, to after the launch instead.
    Adds a real NeoPixel heartbeat (ported from testcard/src/main.c) since
    this firmware previously had no liveness indicator independent of its
    own on-monitor diagnostic colour, which caused real confusion when a
    dark "boot" state looked identical to a genuine crash.
    Switches spi0_slave_init()'s nominal init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
    [main.c]
2026-09-13 mirror_debug: add a bright inset border around the diagnostic fill
    STATE_BOOT's dark grey fill is easy to mistake for "no signal" on some
    monitors/capture chains. Add a white border, inset 10px from the true
    screen edge, around the state-colour area so a real picture is always
    unambiguous regardless of which diagnostic state is showing.
    Claude-Session: https://claude.ai/code/session_01NbfxABZ1XT5pcv3hNi3dsj
    [main.c]
2026-09-13 mirror_debug: explicitly disable pulls on SPI0 slave pins
    RP2350 GPIOs reset with a pull-down enabled, and gpio_set_function()
    doesn't touch that (separate PADS register from the function mux).
    PIN_MOSI/PIN_CS also double as the board's STEMMA QT I2C0 SDA/SCL
    pins, which may add an on-board hardware pull-up. Rules out stray
    pull loading as a factor in the SPI reception investigation, though
    it did not change the observed symptom.
    Claude-Session: https://claude.ai/code/session_01KhNH6Y2N4khXWwpjoUBHwR
    [main.c]
2026-09-19 mirror_debug: replace hardware SPI0 slave with a PIO-based receiver
    The RP2350's PL022 SPI0 peripheral loses byte-alignment after the first
    word of a continuous CS-low burst and never recovers -- proven this
    session via a real Kingst LA2016 capture (SCK/MOSI electrically perfect
    for 14+ bytes straight through the failure point) plus a fine-grained
    SSPSR/DMA-write-pointer trace (BSY stuck at 1, RNE never observed, DMA
    itself proven healthy). This has been the root cause of "1 byte per SPI
    transaction, TDHD header never matches" since 2026-08-30.
    Replace it with a from-scratch PIO program (spi_slave_rx.pio) doing
    mode-0 bit sampling with full software control, no PL022-style internal
    shift-re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
    [main.c]
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2026-09-19 pio-testcard: add CS-fall and abandoned-frame counters, close the 12% mystery
    Confirms header_match_count running ahead of frames_received is not a
    glitch: cs_fall_count == header_match_count always, and
    last_frame_extra_cs_falls is always 0 for completed frames, ruling out a
    spurious CS edge. abandoned_frame_count (incremented when a fresh header
    match arrives mid-stream of a prior, unfinished frame) exactly accounts
    for the whole gap in every sample taken -- the badge occasionally starts
    a new frame before the RP2350 finishes the previous one, which discards
    it outright. Benign for a redraw-driven mirror, not corruption.
    [main.c]
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2026-09-20 pio-testcard: fade the mask to black at the screen edges
    The pillarbox/corner mask area was flat black (zero_buf). Replace it
    with left_mask_buf/right_mask_buf: grey near the visible circular
    content, fading to black over a 32px band as it approaches the true
    left/right screen edge, mirrored on each side.
    right_mask_buf's content-adjacent word is index 0, since phase 3 reads
    away from the content towards the edge. left_mask_buf's is its last
    index instead, since phase 1 reads towards the content -- so its DMA
    read is started at an offset chosen so it always ends on that last
    word regardless of the row's actual mask width.
    [main.c]
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
